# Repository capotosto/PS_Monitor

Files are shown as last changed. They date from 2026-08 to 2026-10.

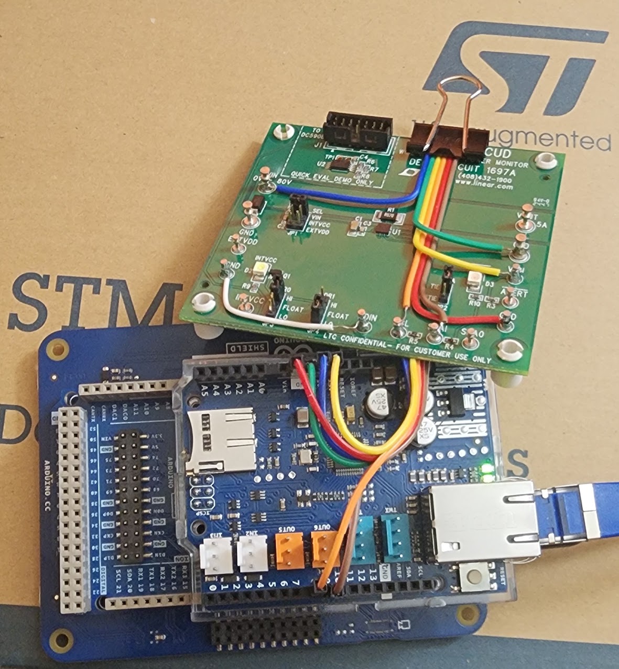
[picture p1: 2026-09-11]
documentation/Pictures/EVBArduinoAssembly.jpg

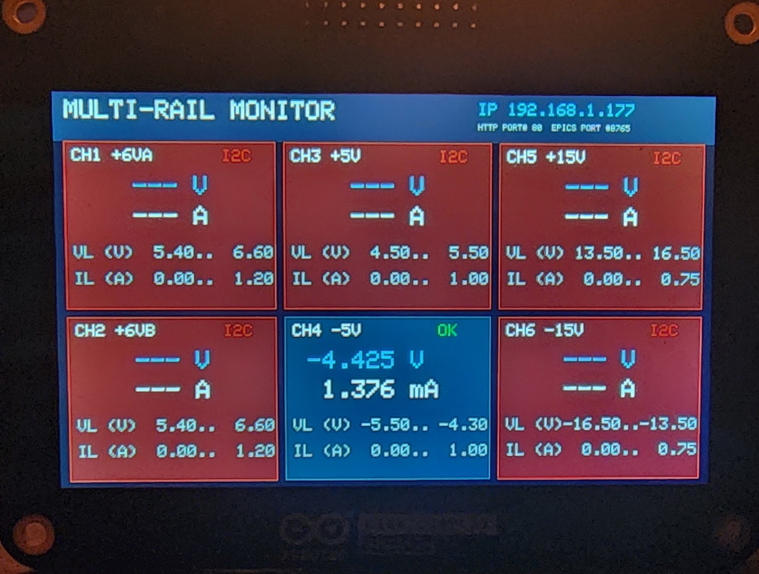
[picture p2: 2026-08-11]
documentation/Pictures/ExampleDisplay-Single_EVB_Connected_Non-ALM-3k3Load.jpg

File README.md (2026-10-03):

# Multi-Rail Isolated Power Supply Monitoring System

**Repository:** `PS_Monitor`  
**Author:** Mike Capotosto

## Project Overview

The Multi-Rail Isolated Power Supply Monitoring System measures the voltage and current of up to six floating power-supply rails while preserving galvanic isolation between measurement channels. Each rail is monitored by an LTC2945 power monitor connected through an isolated I²C interface to an Arduino GIGA R1 WiFi. The Arduino firmware performs data acquisition, engineering-unit conversion, alarm evaluation, persistent configuration storage, local display control, HTTP service, and Ethernet communication with an EPICS Input/Output Controller. Measurement and status information is presented locally on the GIGA Display Shield, through a browser-based dashboard, and remotely through a Phoebus Control System Studio operator interface.

The monitored rails are:

- `+5VA`
- `+5VB`
- `+5V`
- `-5V`
- `+15V`
- `-15V`

---

## System Features

- Six isolated voltage and current measurement channels
- LTC2945 voltage, current, and power monitoring
- Independent I²C isolation for each floating rail
- Support for positive and negative supply rails
- Configurable upper and lower voltage limits
- Configurable upper and lower current limits
- Persistent alarm and network settings stored in internal QSPI flash
- Local touchscreen display using the Arduino GIGA Display Shield
- Browser-based monitoring and configuration dashboard
- Ethernet communication through the Arduino Ethernet Shield
- PSC (Portable Streaming Controller) protocol interface for EPICS integration
- EPICS Process Variables for measurements, limits, alarms, and status
- Phoebus OPI for centralized operator monitoring
- I²C communication-error detection
- Text-based alarm states such as `OVL`, `UVL` (over/under voltage limit), `OCL`, and `UCL` (over/under current limit)

---

## System Architecture

### Data Flow

```text
┌──────────────────────────────────────────────┐
│ Floating Power-Supply Rails                  │
│ +5VA, +5VB, +5V, -5V, +15V, and -15V        │
└──────────────────────┬───────────────────────┘
                       │
                       ▼
┌──────────────────────────────────────────────┐
│ LTC2945 Voltage and Current Monitors         │
│ One monitor per power-supply rail            │
└──────────────────────┬───────────────────────┘
                       │
                       ▼
┌──────────────────────────────────────────────┐
│ Isolated I²C Interfaces                      │
│ Maintains isolation between floating rails   │
└──────────────────────┬───────────────────────┘
                       │
                       ▼
┌──────────────────────────────────────────────┐
│ Arduino GIGA R1 WiFi Firmware                │
│                                              │
│ • Sensor acquisition                         │
│ • Engineering-unit conversion                │
│ • Negative-rail sign correction              │
│ • Alarm evaluation                           │
│ • Persistent settings                        │
│ • Local display                              │
│ • HTTP dashboard                             │
│ • PSC protocol server                        │
└───────────────┬────────────────────┬─────────┘
                │                    │
                ▼                    ▼
┌─────────────────────────┐  ┌──────────────────────┐
│ GIGA Display Shield     │  │ Ethernet Network     │
│ Local touchscreen UI    │  │ HTTP and PSC         │
└─────────────────────────┘  └──────────┬───────────┘
                                       │
                                       ▼
                            ┌────────────────────────┐
                            │ EPICS IOC              │
                            │ PSCDriver and records  │
                            └──────────┬─────────────┘
                                       │
                                       ▼
                            ┌────────────────────────┐
                            │ Phoebus / CSS OPI      │
                            │ Operator interface     │
                            └────────────────────────┘
```

### Major Subsystems

| Subsystem | Function |
|---|---|
| Sensor hardware | Measures rail voltage, shunt voltage, current, and power |
| I²C isolation | Preserves galvanic isolation between floating rails |
| Arduino firmware | Acquires data, evaluates alarms, stores settings, and manages communications |
| Local display | Shows rail measurements, limits, alarms, and communication status |
| HTTP dashboard | Provides browser-based monitoring and configuration |
| PSC interface | Transfers measurement and status data to the EPICS IOC |
| EPICS IOC | Converts device data into EPICS Process Variables |
| Phoebus OPI | Provides the centralized operator interface |

---

## Repository Structure

```text
PS_Monitor/
├── README.md
├── hardware/
│   ├── kicad/
│   ├── bom/
│   ├── gerbers/
│   ├── mechanical/
│   └── datasheets/
├── firmware/
│   ├── platformio.ini
│   ├── include/
│   ├── lib/
│   ├── src/
│   └── test/
├── epics-ioc/
│   ├── configure/
│   ├── db/
│   ├── dbd/
│   ├── iocBoot/
│   ├── psuMonitorApp/
│   └── opi/
└── documentation/
```

### Directory Descriptions

- **`/hardware`**  
  KiCad schematic and PCB files, manufacturing outputs, bill of materials, mechanical drawings, and related.

- **`/firmware`**  
  PlatformIO project for the Arduino GIGA R1 WiFi. This directory contains the application source code, configuration headers, local libraries, and build configuration.

- **`/epics-ioc`**  
  EPICS IOC source tree containing database files, record definitions, startup scripts, PSCDriver configuration, device communication settings, and Phoebus Control System Studio displays.

- **`/documentation`**  
  Assorted Documentation

---

## Hardware

### Primary Components

- Arduino GIGA R1 WiFi
- Arduino GIGA Display Shield
- Arduino Ethernet Shield
- LTC2945 voltage, current, and power monitors
- DC1697A LTC2945 demonstration board for prototype testing
- Per-channel I²C digital isolators
- Current-sense shunt resistors
- Custom monitoring and interface PCB
- Six isolated power-supply inputs

### Measurement Method

Each LTC2945 measures:

- Supply voltage
- Differential voltage across a current-sense shunt
- Calculated load current
- Calculated electrical power

Because each monitored supply may float at a different potential, every sensor channel communicates through its own isolated I²C interface. Negative rails are monitored within their isolated domains, and the firmware applies the appropriate sign to the reported engineering values.

---

## Firmware

The firmware is built with PlatformIO using the Arduino Mbed OS framework.

### Main Firmware Modules

| Module | Responsibility |
|---|---|
| `AppState` | Global channel data, settings, alarms, and system state |
| `SensorManager` | Sensor initialization, acquisition, and channel updates |
| `LTC2945` | Low-level LTC2945 register access and unit conversion |
| `DisplayUI` | GIGA Display Shield rendering and status updates |
| `EthernetServices` | Ethernet initialization and network service handling |
| `HttpDashboard` | Browser-based monitoring and configuration |
| `PscProtocol` | PSC protocol communication with the EPICS IOC |
| `PersistentStorage` | QSPI storage of alarm limits and network settings |
| `main` | System initialization and application scheduling |

### Firmware Configuration

Hardware-specific settings are stored in configuration headers, including:

- I²C addresses
- Shunt-resistance values
- Channel names
- Rail polarity
- Voltage and current scaling
- Default alarm limits
- Static network configuration
- MAC address
- PSC port configuration
- Sensor polling intervals

---

## Persistent Settings

The firmware stores configuration data in the Arduino GIGA internal QSPI flash using LittleFS.

Saved settings include:

- Per-channel voltage-low limit
- Per-channel voltage-high limit
- Per-channel current-low limit
- Per-channel current-high limit
- Static IP address
- Subnet mask
- Gateway address
- DNS server address
---

## Network Interfaces

### HTTP Dashboard

The firmware hosts a local web interface for:

- Viewing voltage and current measurements
- Viewing alarm and communication status
- Editing alarm limits
- Editing network parameters
- Saving settings to QSPI

### PSC Protocol

The Arduino exposes a PSC protocol service over Ethernet. The EPICS IOC connects to the device using PSCDriver and maps transmitted parameters into EPICS records.

---

## EPICS IOC

### Requirements

- EPICS Base
- ASYN
- PSCDriver
- A supported Linux environment
- Phoebus for the operator interface

### Build the IOC

From the repository root:

```bash
cd epics-ioc
make
```

### Start the IOC

```bash
cd iocBoot/iocpsuMonitor
./st.cmd
```

An equivalent direct launch command may also be used:

```bash
../../bin/linux-x86_64/psuMonitor st.cmd
```

### Example IOC Configuration

```text
P=TEST:
R=GIGA
DEVICE=GIGA_PSC
HOST=192.168.1.177
PORT=8765
```

The final values are defined in the IOC startup script.

---

## EPICS Process Variables

The IOC is intended to provide Process Variables for:

- Channel voltage
- Channel current
- Voltage-low limit
- Voltage-high limit
- Current-low limit
- Current-high limit
- Voltage alarm status
- Current alarm status
- Sensor communication status
- I²C error status
- Arduino connection status
- Network information
- Firmware status

### Alarm States

| Status | Meaning |
|---|---|
| `OK` | Measurement is within configured limits |
| `OVL` | Over-voltage limit |
| `UVL` | Under-voltage limit |
| `OCL` | Over-current limit |
| `UCL` | Under-current limit |
| `I2C Error` | Sensor communication failure |
| `Disconnected` | IOC communication failure |

---

## Operator Interface

The Phoebus OPI provides a centralized display for all monitored rails.

Planned or implemented interface elements include:

- Voltage and current readbacks
- Alarm-limit displays
- Text-based alarm indicators
- Connection-status indicator
- I²C error indicator
- Per-channel status cards
- Network and firmware information
- Overall system status

---

## Project Milestones

- [x] Define system requirements and monitored power rails
- [x] Select the Arduino GIGA R1 WiFi as the primary controller
- [x] Establish the PlatformIO firmware project
- [x] Develop the initial six-channel display layout
- [x] Add configurable voltage and current alarm limits
- [x] Establish the Ethernet and PSC communication architecture
- [x] Complete single-channel LTC2945 prototype validation
- [ ] Verify current scaling for each shunt-resistor value
- [ ] Complete six-channel isolated I²C hardware
- [ ] Finalize persistent storage and recovery testing
- [ ] Complete browser-based configuration testing
- [ ] Finalize EPICS database records
- [ ] Complete Phoebus OPI
- [ ] Fabricate and assemble the custom PCB
- [ ] Calibrate all measurement channels
- [ ] Perform end-to-end system validation
- [ ] Complete final project documentation

---

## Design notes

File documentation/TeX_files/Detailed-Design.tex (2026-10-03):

% !TeX root = ../main.tex
\chapter{Detailed Design Review}
\label{chap:detailed-design}

\begin{weekthreechange}
    The preliminary architecture has been carried forward into this detailed implementation of six galvanically isolated V/I measurement channels, an Arduino Giga R1 micro, display module, ethernet interface, EPICS IOC, and Phoebus control panels. The monitored rails in this design are digital supplies +5VA, +5VB, and analog voltages +/-5V, and +/-15V. Component-level ratings, procurement, and porduction cost impacts are reviewed in the BOM and cost analysis sections of the following review.
\end{weekthreechange}

\section{Purpose and Scope}
This chapter documents the hardware and software design of the
Multi-Rail Isolated Power Supply Monitoring System. The design monitors six
power-supply rails, measures rail voltage and load current, preserves electrical
isolation between floating supplies and the controller, evaluates measurements
against user-configurable alarm limits, presents local status on the controller
display, and publishes measurements and status to an EPICS control-system
interface.

This design is intended to establish the major analog and digital
functional blocks, document supporting engineering calculations, define the
hardware schematic baseline, and provide software flowcharts detailed enough to
support implementation.

\section{Problem Definition}
The project addresses the need to monitor several low-voltage power-supply rails
that do not necessarily share a common reference. A conventional
monitoring circuit that directly connects the grounds together
would defeat the electrical isolation of the supplies and could create unwanted
return paths. However, the user needs a single location from which to observe rail voltage, rail current, alarm state, communication status, and the overall condition of the power system.

The required monitoring system must therefore make accurate measurements on
six separate rails while preserving isolation between the monitored domains. It
must support both positive and negative rails, detect sensor or communication
faults, provide configurable voltage and current limits, retain configuration
information after reset, present useful local status, and make the same data
available to the facility control system over Ethernet. The monitored rails in
the present design are +5 V A, +5 V B, +/-5 V, and +/-15 V.

\section{Proposed Solution}
The proposed solution assigns one LTC2945 voltage/current monitor to each power
rail. Load current is converted to a small differential voltage by a precision
high-side shunt resistor and the LTC2945 digitizes both the shunt voltage and the
rail voltage. Each sensor remains referenced to its own monitored supply domain.
The I\textsuperscript{2}C communication path is then isolated so that digital
measurement data can be transferred to a common Arduino GIGA R1 WiFi controller
without directly bonding the isolated supply returns together.

The Arduino GIGA performs channel acquisition, engineering-unit conversion,
negative-rail sign handling, alarm evaluation, configuration storage, display
updates, and network communication. A local GIGA Display Shield provides
immediate status at the hardware. Ethernet transports measurement and status
data using the PSC protocol to an EPICS IOC, where PSCDriver and EPICS records
make the values available to a CS-Studio Phoebus operator interface. This
architecture separates the rail-side analog measurement functions from the
controller and supervisory-control functions while maintaining a single user
interface for the complete system.

\section{Chosen Conceptual Design and Functional Block Diagram}
\label{sec:functional-blocks}
The major system functions are summarized below.

\begin{enumerate}
    \item \textbf{Power-Supply Interface:} Connect to the six monitored rails and
    route each rail through the associated voltage/current monitoring channel.
    \item \textbf{Current Measurement:} Convert load current to a differential
    voltage across a precision shunt resistor and digitize it with the
    LTC2945.
    \item \textbf{Voltage Measurement:} Measure the monitored rail voltage using
    the LTC2945 supply-voltage ADC channel.
    \item \textbf{Electrical Isolation:} Maintain galvanic isolation between each
    floating monitored supply and the common controller-side I\textsuperscript{2}C bus.
    \item \textbf{Digital Acquisition:} Poll each monitor, identify communication
    faults, apply channel-specific sign/scaling information, and calculate
    engineering-unit values.
    \item \textbf{Alarm Processing:} Compare voltage and current values against
    configured upper and lower limits and generate channel alarm states.
    \item \textbf{Local User Interface:} Present all rail measurements, alarms,
    network state, and communication status on the Arduino GIGA Display.
    \item \textbf{Network/EPICS Interface:} Publish measurements, alarm limits,
    alarm state, and connection status over Ethernet for the EPICS IOC and
    Phoebus interface.
\end{enumerate}

\subsection{Functional Block Diagram}

\begin{figure}[H]
    \centering

    \makebox[\textwidth][c]{%
        \rotatebox{90}{%
            \begin{minipage}{0.9\textheight}
                \centering

                \resizebox{0.78\textheight}{!}{%
                    \begin{tikzpicture}[
                        >=Stealth,
                        font=\small,
                        block/.style={
                            draw,
                            rectangle,
                            rounded corners=2pt,
                            align=center,
                            minimum height=1.25cm,
                            minimum width=2.75cm,
                            text width=2.45cm,
                            inner sep=5pt,
                            line width=0.8pt
                        },
                        rail/.style={
                            draw,
                            rectangle,
                            rounded corners=2pt,
                            align=center,
                            minimum height=0.55cm,
                            minimum width=1.35cm,
                            font=\footnotesize,
                            line width=0.7pt
                        },
                        group/.style={
                            draw,
                            dashed,
                            rounded corners=4pt,
                            inner sep=8pt,
                            line width=0.8pt
                        },
                        signal/.style={
                            ->,
                            line width=0.9pt
                        },
                        line/.style={
                            line width=0.9pt
                        },
                        bus/.style={
                            line width=1.1pt
                        },
                        busarrow/.style={
                            ->,
                            line width=1.1pt
                        },
                        siglabel/.style={
                            font=\scriptsize,
                            fill=white,
                            inner sep=1.5pt,
                            text depth=0pt,
                            text height=1.5ex,
                            align=center
                        }
                        ]

                        % ============================================================
                        % MONITORED POWER RAILS
                        % ============================================================

                        \node[rail] (p6a) at (0, 2.25) {+6 V A};
                        \node[rail] (p6b) at (0, 1.35) {+6 V B};
                        \node[rail] (p5)  at (0, 0.45) {+5 V};
                        \node[rail] (m5)  at (0,-0.45) {$-5$ V};
                        \node[rail] (p15) at (0,-1.35) {+15 V};
                        \node[rail] (m15) at (0,-2.25) {$-15$ V};

                        \node[
                        above=0.30cm of p6a,
                        font=\bfseries
                        ] {Monitored Power-Supply Rails};

                        % ============================================================
                        % RAIL COLLECTION BUS
                        % ============================================================

                        \coordinate (railBusTop)    at (1.15, 2.25);
                        \coordinate (railBusBottom) at (1.15,-2.25);
                        \coordinate (railBusMid)    at (1.15, 0);

                        \draw[bus] (railBusTop) -- (railBusBottom);

                        % Individual rail connections -- no overlapping arrowheads.
                        \foreach \railname/\y in {
                            p6a/2.25,
                            p6b/1.35,
                            p5/0.45,
                            m5/-0.45,
                            p15/-1.35,
                            m15/-2.25
                        }{
                            \draw[line] (\railname.east) -- (1.15,\y);
                        }

                        % ============================================================
                        % POWER-SUPPLY INTERFACE BOARD
                        % ============================================================

                        \node[
                        block,
                        anchor=west
                        ] (shunts) at (2.15,0)
                        {
                            High-Side\\
                            Current-Sense Shunts\\[2pt]
                            \footnotesize
                            One independent\\
                            sense element per rail
                        };

                        \node[
                        block,
                        right=0.65cm of shunts
                        ] (ltc)
                        {
                            LTC2945\\
                            Voltage / Current\\
                            Monitor Channels\\[2pt]
                            \footnotesize
                            Six independent\\
                            channels
                        };

                        \node[
                        block,
                        right=0.65cm of ltc
                        ] (iso)
                        {
                            I\textsuperscript{2}C Digital\\
                            Isolation\\[2pt]
                            \footnotesize
                            One isolated interface\\
                            per monitored rail
                        };

                        \draw[busarrow]
                        (railBusMid)
                        --
                        (shunts.west);

                        \draw[busarrow]
                        (shunts.east)
                        --
                        node[
                        siglabel,
                        midway,
                        rotate=90,
                        above=6pt
                        ]
                        {Sense Voltage}
                        (ltc.west);

                        \draw[busarrow]
                        (ltc.east)
                        --
                        node[
                        siglabel,
                        midway,
                        above=4pt
                        ]
                        {I\textsuperscript{2}C}
                        (iso.west);

                        % ============================================================
                        % POWER-SUPPLY INTERFACE GROUP
                        % ============================================================

                        \begin{scope}[on background layer]
                            \node[
                            group,
                            fit=(shunts)(ltc)(iso)
                            ] (interfaceGroup) {};
                        \end{scope}

                        \node[
                        font=\bfseries,
                        fill=white,
                        inner sep=2pt,
                        anchor=south
                        ]
                        at (interfaceGroup.north)
                        {Power Supply Interface Board};

                        % ============================================================
                        % ISOLATION BARRIER
                        % ============================================================

                        \coordinate (barrierTop)
                        at ($(iso.north east)+(0.50,0.55)$);

                        \coordinate (barrierBottom)
                        at ($(iso.south east)+(0.50,-0.55)$);

                        % Keep only the dashed isolation-barrier line; no text label.
                        \draw[
                        dashed,
                        line width=1.1pt
                        ]
                        (barrierTop) -- (barrierBottom);

                        % ============================================================
                        % ARDUINO GIGA
                        % ============================================================

                        \node[
                        block,
                        right=1.45cm of iso
                        ] (giga)
                        {
                            Arduino GIGA R1 WiFi\\[2pt]
                            \footnotesize
                            Acquire Measurements\\
                            Apply Scaling and Polarity\\
                            Evaluate Alarm Limits\\
                            Manage Configuration
                        };

                        \draw[busarrow]
                        (iso.east)
                        --
                        node[
                        siglabel,
                        midway,
                        rotate=90,
                        above=6pt
                        ]
                        {Isolated I\textsuperscript{2}C}
                        (giga.west);

                        % ============================================================
                        % DISPLAY AND ETHERNET
                        % ============================================================

                        \node[
                        block,
                        right=1.25cm of giga,
                        yshift=1.55cm
                        ] (display)
                        {
                            GIGA Display Shield\\[2pt]
                            \footnotesize
                            Voltage / Current\\
                            Alarm Status\\
                            Communication Status
                        };

                        \node[
                        block,
                        right=1.25cm of giga,
                        yshift=-1.55cm
                        ] (ethernet)
                        {
                            Ethernet Interface\\[2pt]
                            \footnotesize
                            PSC Protocol\\
                            Configuration Interface
                        };

                        \coordinate (controllerBranch)
                        at ($(giga.east)+(0.55,0)$);

                        \draw[line]
                        (giga.east)
                        --
                        (controllerBranch);

                        \draw[signal]
                        (controllerBranch)
                        |-
                        (display.west);

                        \draw[signal]
                        (controllerBranch)
                        |-
                        (ethernet.west);

                        \fill (controllerBranch) circle (1.5pt);

                        % ============================================================
                        % CONTROLLER GROUP
                        % ============================================================

                        \begin{scope}[on background layer]
                            \node[
                            group,
                            fit=(giga)(display)(ethernet)
                            ] (controllerGroup) {};
                        \end{scope}

                        \node[
                        font=\bfseries,
                        fill=white,
                        inner sep=2pt,
                        anchor=south
                        ]
                        at (controllerGroup.north)
                        {Controller Assembly};

                        % ============================================================
                        % EPICS IOC
                        % ============================================================

                        \node[
                        block,
                        right=1.20cm of ethernet
                        ] (ioc)
                        {
                            EPICS IOC / PSCDriver\\[2pt]
                            \footnotesize
                            Receive Measurements\\
                            Publish Engineering Values\\
                            Generate EPICS Alarms
                        };

                        \draw[busarrow]
                        (ethernet.east)
                        --
                        node[
                        siglabel,
                        midway,
                        rotate=90,
                        above=6pt
                        ]
                        {Ethernet}
                        (ioc.west);

                        % ============================================================
                        % PHOEBUS
                        % ============================================================

                        \node[
                        block,
                        right=1.20cm of ioc
                        ] (phoebus)
                        {
                            CS-Studio Phoebus\\[2pt]
                            \footnotesize
                            Operator Interface\\
                            Voltage / Current Display\\
                            Alarm and System Status
                        };

                        \draw[busarrow]
                        (ioc.east)
                        --
                        node[
                        siglabel,
                        midway,
                        rotate=90,
                        below=6pt
                        ]
                        {EPICS Channel Access}
                        (phoebus.west);

                        % ============================================================
                        % SUPERVISORY GROUP
                        % ============================================================

                        \begin{scope}[on background layer]
                            \node[
                            group,
                            fit=(ioc)(phoebus)
                            ] (supervisoryGroup) {};
                        \end{scope}

                        \node[
                        font=\bfseries,
                        fill=white,
                        inner sep=2pt,
                        anchor=south
                        ]
                        at (supervisoryGroup.north)
                        {Supervisory Control System};

                    \end{tikzpicture}%
                }

                \vspace{0.25cm}

                \caption{
                    Functional block diagram of the multi-rail isolated
                    power supply monitoring system. Six independent power-supply rails
                    are measured using high-side current sensing and LTC2945 voltage/current
                    monitoring channels. Digital isolation preserves electrical independence
                    between the monitored supplies and the common controller. The Arduino
                    GIGA processes the measurements, provides a local operator display, and
                    transmits measurement and status information over Ethernet to the EPICS
                    IOC and CS-Studio Phoebus operator interface.
                }
                \label{fig:functional-block-diagram}

            \end{minipage}%
        }%
    }

\end{figure}

\section{Engineering Calculations}
\label{sec:engineering-calculations}

\section{Functional Specifications}
\label{sec:functional-specifications}
The functional specifications used for the design are summarized in
Table~\ref{tab:functional-specifications}. These values define the intended
operating envelope of the prototype and establish the quantities that must be
checked during circuit analysis and later verification testing.

\begin{table}[H]
    \centering
    \caption{Functional specifications.}
    \label{tab:functional-specifications}
    \begin{tabularx}{\textwidth}{>{\raggedright\arraybackslash}p{0.27\textwidth}X}
        \toprule
        \textbf{Function} & \textbf{Specification} \\
        \midrule
        Monitored rails & +5 V A, +5 V B, +5 V, -5 V, +15 V, and -15 V \\
        Number of channels & Six independent voltage/current measurement channels \\
        +5 V A/B current range & 0 to 2 A design range per rail \\
        +5 V, -5 V, +15 V, -15 V current range & 0 to 1 A design range per rail \\
        Voltage measurement resolution & 25 mV/LSB nominal using the LTC2945 rail-voltage ADC \\
        Current-sense resolution & 25 \(\mu\)V/LSB across the selected shunt resistor; approximately 0.641 mA/LSB with 39 m\(\Omega\) and 0.500 mA/LSB with 50 m\(\Omega\) \\
        Isolation & Independent digital isolation for every floating monitor channel \\
        Alarm processing & User-configurable upper/lower voltage and current limits with local and EPICS status indication \\
        Fault handling & Detect failed I\textsuperscript{2}C transactions and prevent invalid data from being treated as a valid measurement \\
        Local interface & GIGA Display Shield showing voltage, current, alarm state, communication state, and configured limits \\
        Network interface & Ethernet PSC server for EPICS IOC communication plus browser-based configuration/monitoring services \\
        Configuration retention & Network parameters and alarm limits stored in nonvolatile memory \\
        Controller logic level & 3.3 V; external interfaces must not exceed the GIGA I/O limits \\
        \bottomrule
    \end{tabularx}
\end{table}

\section{Design Methodology}
The design was developed by dividing the system into measurement, isolation,
controller, user-interface, and control-system functions and then verifying the
interfaces between those blocks. The analog measurement design began with the
maximum required rail current. The shunt value was selected so that the maximum
nominal current produces a differential voltage comfortably below the LTC2945
102.4 mV current-sense full-scale value. Power dissipation in each shunt was
then calculated using \(P=I^2R\), and the selected resistor rating was checked
against the calculated worst-case dissipation. The same approach was used for
PCB copper: maximum continuous current, allowable temperature rise, and voltage
drop were considered before final trace and copper-pour dimensions were chosen.
Detailed calculations are included in Appendix~\ref{app:design-calculations}.

Electrical isolation was treated as a system-interface requirement rather than
only a component-selection problem. Each LTC2945 remains electrically local to
its rail, and the digital signals cross the isolation boundary through isolated
logic. Controller-side I\textsuperscript{2}C buffering and level compatibility
were checked against 3.3 V logic requirements. The controller does not drive
loads directly; its GPIO and I\textsuperscript{2}C pins only interface to
logic-level circuitry. This substantially reduces the current demanded from an
individual microcontroller pin and allows the high-current rail paths to remain
on the dedicated sensor hardware.

The embedded-software design follows the same functional partitioning. Sensor
acquisition is separated from display formatting, network services, persistent
storage, and PSC message handling. Alarm processing is performed on engineering-unit values after
channel polarity and scaling are applied. The EPICS IOC is intentionally kept
outside the embedded controller so that the Arduino is responsible for hardware
acquisition while the IOC is responsible for exposing process variables to the remote user control system.

\section{Design Schematics}
\label{sec:prelim-schematics}

The hardware schematics are maintained in KiCad and are included
below directly from the plotted PDF files in the project hardware directory.

\subsection{Sensor Board Schematic}

\includepdf[
pages=-,
angle=90,
scale=0.90,
pagecommand={}
]{
    ../hardware/Isolated Multi-Rail Power Supply Monitor Sensor Board/%
    Isolated Multi-Rail Power Supply Monitor Sensor Board.pdf
}

\subsection{Arduino Shield Board Schematic}

\includepdf[
pages=-,
angle=90,
scale=0.90,
pagecommand={}
]{
    ../hardware/Isolated Multi-Rail Power Supply Monitor Arduino Shield Board/%
    Isolated Multi-Rail Power Supply Monitor Arduino Shield Board.pdf
}

\section{Software Architecture and Critical Software Test Results}
\label{sec:software-architecture-tests}
The embedded software is organized into functional modules rather than one
loop. The current implementation contains shared application state,
sensor-management and LTC2945 register-access code, display handling, Ethernet
services, an web control page, PSC protocol handling, persistent storage, and the
main application controller. This separation permits the measurement code to be
tested independently of the EPICS IOC and permits the network/control-system
interface to consume already processed engineering-unit values.

At startup, the firmware initializes hardware interfaces, loads persistent
settings, configures the monitoring channels, and then enters repetitive sensor
acquisition and service processing. Each channel read is checked for successful
I\textsuperscript{2}C communication before conversion. Valid raw ADC values are
scaled using the configured shunt resistance and channel polarity; invalid
transactions produce a communication error state. Voltage and current values
are then compared with their configured lower and upper limits before the local
display and PSC message data are updated. The detailed execution flow is shown
in Appendix~\ref{app:software-flowchart}.

The most critical functions were tested to the extent possible on the available
single-channel evaluation board setup. Sensor acquisition returned stable voltage
and current data, open\slash unconnected channels produced I\textsuperscript{2}C fault
states instead of plausible but invalid values, negative-rail sign handling was
visible on the -5 V test channel, and changing a voltage limit changed the local
alarm state as expected. Ethernet/PSC communication was verified by the EPICS
IOC reporting a connected driver and by Phoebus displaying the same test-channel
voltage/current data. Remaining multi-channel verification, long-duration
operation, restart/persistence checks, and final PCB testing will be repeated on
the assembled production hardware. This is shown in more detail in \nameref{chap:prototyping-dev}

\section{Summary of Preliminary-Design Changes and Project Impact}
\label{sec:w2-design-changes}
The preliminary-design work identified several items that were clarified or
changed from the earliest project documentation. Table~\ref{tab:w2-changes}
summarizes the principal changes and their effect on the design baseline.

\begin{table}[H]
    \centering
    \caption{Week 2 design changes and resulting impact.}
    \label{tab:w2-changes}
    \begin{tabularx}{\textwidth}{>{\raggedright\arraybackslash}p{0.25\textwidth}>{\raggedright\arraybackslash}p{0.31\textwidth}X}
        \toprule
        \textbf{Item} & \textbf{Preliminary-design result} & \textbf{Impact} \\
        \midrule
        Rail naming & The two high-current digital rails are +5 V A and +5 V B. & Some documentation and channel labels were corrected where it showed +6V; electrical architecture is unchanged. \\
        Production shunts & 39 m\(\Omega\) selected for 2 A +5 V rails and 50 m\(\Omega\) selected for 1 A rails. & Improves headroom and keeps shunt dissipation well below the selected resistor rating. \\
        Prototype shunt & The DC1697A shunt was changed to approximately 17.8 \(\Omega\) for low-current Arduino-driven loads. & Allows realistic ADC utilization during testing without exceeding Arduino regulator current limits. \\
        I\textsuperscript{2}C pull-ups & External 4.7 k\(\Omega\) pull-up footprints remain available but are DNP where the selected buffer/current-source arrangement makes them unnecessary. & Reduces unnecessary loading and preserves the intended I\textsuperscript{2}C interface behavior. \\
        Fault handling & Missing or failed sensors are represented as communication faults rather than numerical measurements. & Reduces risk of a supervisory system accepting stale or fabricated values. \\
        Configuration and network software & Alarm/network settings, HTTP services, PSC communication, and the Phoebus interface are now part of the implemented software baseline. & Adds firmware integration work but reduces final-system risk because these interfaces can be exercised before all six production channels are assembled. \\
        Cost/schedule baseline & No formal budget or schedule re-baseline is required solely because of the Week 2 design changes. & Component values and firmware structure changed within the existing architecture; procurement cost will be rechecked after first-article PCB testing and any resulting BOM revisions. \\
        \bottomrule
    \end{tabularx}
\end{table}

The largest remaining technical risk is integration of all six isolated channels
on the final PCB rather than operation of any single functional block. The
single-channel prototype reduced uncertainty in the LTC2945 measurement,
firmware scaling, alarm processing, Ethernet/PSC firmware, and operator interface.
Final verification will focus on channel-to-channel isolation,
concurrent I\textsuperscript{2}C operation, and confirmation that all configured settings survive normal resets and power cycles.

\begin{weekthreechange}
    Following the PDR, the hardware design was finalized to the component level without change. The measurement architecture developed in the PDR is unchanged. Component selections were once again verified, confirming voltage, current, powe,r and tolerance of components were within requirements to meet the design specifications. Component availability and part numbers were verified against the BOM to ensure correct parts were specified.

    The hardware and firmware were reviewed together to ensure the software's scaling settings correspond to the component values selected, and to confirm channel polarity is consistent between the input and the software's final readout to the user.
\end{weekthreechange}

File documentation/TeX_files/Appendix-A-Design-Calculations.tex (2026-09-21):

% !TeX root = ../main.tex
\chapter{Design Calculations and Circuit Analysis}
\label{app:design-calculations}
This appendix contains the electrical calculations used to select and verify the
preliminary hardware. In addition to nominal values, voltage, current, power,
logic-level compatibility, and component capability are considered so that the
design does not intentionally operate a component beyond its specified limits.

\section{Current-Sense Shunt Resistor Sizing}
\label{sec:shunt-sizing}
The LTC2945 measures the differential voltage between SENSE+ and SENSE-- with a
full-scale range of \SI{102.4}{\milli\volt}. The ideal shunt resistance for a
specified maximum measurable current is therefore
\begin{equation}
    R_{SHUNT,ideal}=\frac{V_{SENSE,FS}}{I_{MAX}}
    =\frac{\SI{102.4}{\milli\volt}}{I_{MAX}}.
\end{equation}
To prevent saturation, a scaling factor, $K_H$, is applied to leave some headroom:
\begin{equation}
    R_{SHUNT}=K_H\frac{\SI{102.4}{\milli\volt}}{I_{MAX}},
    \qquad 0<K_H<1.
\end{equation}
For example, $K_H=0.80$ reserves 20\% headroom for overload, tolerance, and
transient conditions.

The shunt power at maximum continuous current is
\begin{equation}
    P_{SHUNT}=I_{MAX}^{2}R_{SHUNT}.
\end{equation}
The installed resistor power rating should exceed this value.

\subsection{Current Measurement Resolution}
The LTC2945 current-sense ADC has a nominal sense-voltage resolution of
\SI{25}{\micro\volt} per LSB. The current represented by one ADC count is
\begin{equation}
    I_{LSB}=\frac{\SI{25}{\micro\volt}}{R_{SHUNT}}.
\end{equation}
This relationship provides an important design tradeoff: a smaller shunt lowers
power dissipation but also increases the minimum current increment represented by
one ADC count.

\subsection{Production Shunt Design Table}
\begin{table}[H]
    \centering
    \caption{Production current-sense resistor calculations.}
    \label{tab:production-shunts}
    \begin{tabular}{lrrrrrr}
        \toprule
        Rail & $I_{MAX}$ & $R_{ideal}$ & Selected $R$ &
        $V_{SHUNT}$ & $I_{LSB}$ & $P_{MAX}$ \\
        & (A) & ($\Omega$) & ($\Omega$) &
        (mV) & (mA/LSB) & (W) \\
        \midrule
        +5VA  & 2.00 & 0.0512 & 0.039 & 78.0 & 0.641 & 0.156 \\
        +5VB  & 2.00 & 0.0512 & 0.039 & 78.0 & 0.641 & 0.156 \\
        +5V   & 1.00 & 0.1024 & 0.050 & 50.0 & 0.500 & 0.050 \\
        -5V   & 1.00 & 0.1024 & 0.050 & 50.0 & 0.500 & 0.050 \\
        +15V  & 1.00 & 0.1024 & 0.050 & 50.0 & 0.500 & 0.050 \\
        -15V  & 1.00 & 0.1024 & 0.050 & 50.0 & 0.500 & 0.050 \\
        \bottomrule
    \end{tabular}
\end{table}

\subsection{Evaluation-Board Shunt Calculation}
The prototype LTC2945 evaluation board was tested from a \SI{5}{\volt} source
with a load range of approximately \SI{1}{\kilo\ohm} to \SI{10}{\kilo\ohm}.
This is a low-current bench-test condition and is separate from the production
shunt design.

At the minimum load resistance, the shunt required to place the current-sense
input at full scale is
\begin{equation}
    R_{S,FS}=\frac{V_{SHUNT}R_L}{V_S-V_{SHUNT}}
    =\frac{(\SI{0.1024}{\volt})(\SI{1}{\kilo\ohm})}
    {\SI{5}{\volt}-\SI{0.1024}{\volt}}
    =\SI{20.91}{\ohm}.
\end{equation}
Applying approximately 15\% headroom gives
\begin{equation}
    R_S=(0.85)(\SI{20.91}{\ohm})\approx\SI{17.8}{\ohm}.
\end{equation}
At a \SI{10}{\kilo\ohm} load,
\begin{equation}
    I_{MIN}=\frac{\SI{5}{\volt}}
    {\SI{10}{\kilo\ohm}+\SI{17.8}{\ohm}}
    \approx\SI{499.1}{\micro\ampere},
\end{equation}
and therefore
\begin{equation}
    V_{SHUNT,MIN}=I_{MIN}R_S
    \approx(\SI{499.1}{\micro\ampere})(\SI{17.8}{\ohm})
    \approx\SI{8.88}{\milli\volt}.
\end{equation}
The prototype sense voltage therefore remains inside the LTC2945
\SI{102.4}{\milli\volt} full-scale range over the intended test loads.

\section{PCB Trace and Copper-Pour Current Capacity}
\label{sec:trace-width}
Power-path copper must carry the maximum rail current without excessive
temperature rise or voltage drop. KiCad's track-width calculator uses a
closed-form fit to IPC-2152 data. For an external trace it can be expressed as
\begin{equation}
    \Delta T = K I^a W^b T_h^c,
\end{equation}
where $I$ is current in amperes, $W$ is trace width in mils, $T_h$ is copper
thickness in mils, and for external tracks the KiCad coefficients are
\begin{equation}
    K=215.3,\qquad a=2,\qquad b=-1.15,\qquad c=-1.0.
\end{equation}
Solving for minimum width,
\begin{equation}
    W_{MIN}=\left(\frac{\Delta T}
    {K I^a T_h^c}\right)^{1/b}.
\end{equation}
For \SI{1}{oz} copper ($T_h\approx\SI{1.378}{mil}$) and a preliminary
\SI{10}{\celsius} allowed rise, the calculated external-trace widths are
approximately \SI{3.27}{mil} at \SI{0.5}{A}, \SI{10.9}{mil} at \SI{1}{A}, and
\SI{36.4}{mil} at \SI{2}{A}. These are thermal minimums only; the actual layout
should use wider traces or copper pours where space permits.

\section{I\texorpdfstring{\textsuperscript{2}}{2}C Pull-Up Resistor Sizing}
\label{sec:i2c-pullups}
The I2C bus buffer and I2C line driver both have internal active current sources that eliminate the need for external pullups. Footprints were placed for 4.7k pullups but are set as Do Not Populate.

\section{LTC2945 Voltage Measurement Resolution}
The LTC2945 rail-voltage channel has a nominal full-scale range of
\SI{102.4}{\volt} and a nominal resolution of \SI{25}{\milli\volt} per LSB.
The quantization-only percentage of a measured rail voltage is therefore
\begin{equation}
    \epsilon_Q=\frac{\SI{25}{\milli\volt}}{V_{RAIL}}\times100\%.
\end{equation}
For example, one count corresponds to approximately 0.50\% of a \SI{5}{\volt}
rail and 0.17\% of a \SI{15}{\volt} rail.
This is only ADC resolution and not total measurement
accuracy.

\section{Negative-Rail Sign Convention}
The -5 V and -15 V supplies are electrically isolated from the controller. The
monitor can therefore be placed in the high side of each isolated rail and read a
positive local differential quantity even when the system-level rail is labeled
negative. Firmware applies the configured sign after acquisition:
\begin{equation}
    V_{DISPLAY}=S_VV_{MEASURED},\qquad S_V\in\{+1,-1\}.
\end{equation}
The same channel metadata is used by the local display and network interface so
that a negative rail is represented consistently throughout the system.

\section{Alarm-Limit Scaling}
User alarm thresholds are stored and compared in engineering units. For a lower
voltage limit $V_L$ and upper voltage limit $V_H$, the normal voltage state is
\begin{equation}
    V_L\le V_{MEAS}\le V_H.
\end{equation}
Similarly, for lower and upper current limits,
\begin{equation}
    I_L\le I_{MEAS}\le I_H.
\end{equation}
If raw ADC thresholds are ever written directly to the LTC2945, the corresponding
register value must be calculated from the ADC LSB size. For the current-sense
channel,
\begin{equation}
    N_I=\frac{I_{LIMIT}R_{SHUNT}}{\SI{25}{\micro\volt/LSB}},
\end{equation}
and for the rail-voltage channel,
\begin{equation}
    N_V=\frac{V_{LIMIT}}{\SI{25}{\milli\volt/LSB}}.
\end{equation}

\section{Controller-Supply Power Budget}

A preliminary controller power budget was developed using datasheet maximum
values where available and conservative design-current allowances for assemblies
where a complete board-level maximum current is not specified. A 25\% design
margin is applied to the calculated load.

\begin{table}[H]
    \centering
    \caption{Preliminary controller-side power budget.}
    \label{tab:power-budget}
    \begin{tabular}{lrrr}
        \toprule
        Load & Supply & Design Current & Power \\
        & (V) & (A) & (W) \\
        \midrule
        Arduino GIGA R1 WiFi
        & 5.0 & 0.500 & 2.500 \\

        GIGA Display Shield
        & 3.3 & 0.250 & 0.825 \\

        W6100 Ethernet interface
        & 3.3 & 0.265 & 0.875 \\

        I\textsuperscript{2}C isolation/controller circuitry
        & 3.3 & 0.065 & 0.215 \\
        \midrule
        Subtotal
        & -- & -- & 4.415 \\

        25\% design margin
        & -- & -- & 1.104 \\
        \midrule
        \textbf{Total}
        & -- & -- & \textbf{5.519} \\
        \bottomrule
    \end{tabular}
\end{table}

\section{Component Capability Checks}
\label{sec:component-capability}
The calculations above establish the required electrical values. The following
checks compare those values with the capability of the selected components.

\section{Current-Sense Resistor Power Margin}
The selected LVK-series 39 m\(\Omega\) and 50 m\(\Omega\) four-terminal shunts
are rated at 0.75 W. At the maximum design current of 2 A, the 39 m\(\Omega\)
resistor dissipates
\begin{equation}
    P=(2\,\mathrm{A})^2(0.039\,\Omega)=0.156\,\mathrm{W}.
\end{equation}
This is approximately 20.8\% of the 0.75 W rating, corresponding to about a
4.8:1 power-rating margin before considering PCB temperature and derating. At
1 A, a 50 m\(\Omega\) shunt dissipates only 0.050 W, approximately 6.7\% of a
0.75 W rating.

\section{LTC2945 Input and ADC Range}
The highest monitored nominal rail is 15 V, far below the LTC2945 0--80 V rail
monitoring range. The selected production shunts produce 78 mV at 2 A on the
39 m\(\Omega\) channels and 50 mV at 1 A on the 50 m\(\Omega\) channels. Both
values are below the 102.4 mV current-sense full scale, leaving approximately
24.4 mV and 52.4 mV of ADC headroom respectively. The LTC2945 can operate from
an external 2.7--5.9 V supply, so a 3.3 V sensor-side logic supply is within its
specified operating range.

\section{Microcontroller I/O Compatibility}
The Arduino GIGA R1 WiFi operates with 3.3 V logic and specifies 8 mA maximum DC
current per I/O pin. The controller-side I\textsuperscript{2}C interface is a
logic interface, not a load-power interface. The TCA9803 used in the design
supports a 0.8--3.6 V A-side supply and a 1.65--3.6 V B-side supply and provides
an internal B-side current source of up to 3 mA. A 3 mA bus-low current is below
the 8 mA GIGA per-pin limit, providing more than a factor of two current margin.
The GIGA pins therefore do not directly source the optocoupler LED or rail-load
current; the external interface circuitry performs the required buffering and
isolation.

\section{Digital-Isolation Margin}
The ACPL-064L digital optocoupler is specified for 3.3 V/5 V operation and is
UL 1577 recognized for 3750 V\textsubscript{RMS} isolation for one minute. The
largest normal potential difference between the nominal monitored rails is only
30 V from -15 V to +15 V. The optocoupler rating therefore greatly exceeds the
functional isolation voltage required by this low-voltage monitoring system.
This comparison verifies component capability; it is not intended to redefine
the safety rating of the complete assembled product, which also depends on PCB
creepage, clearance, connectors, wiring, and enclosure construction.

\section{3.3 V Regulator Loading}
The TPS62912 is rated for up to 2 A output. Using the Week 1 design-current
allowances for the display, Ethernet interface, and controller-side isolation
circuitry gives an estimated 3.3 V load of
\begin{equation}
    I_{3.3}=0.250+0.265+0.065=0.580\,\mathrm{A}.
\end{equation}
This is approximately 29\% of the regulator's 2 A output rating and leaves
substantial current margin for transient and implementation variation.

\section{Tolerance and Measurement-Uncertainty Considerations}
The production current-sense resistors have a 1\% resistance tolerance. Because
current is calculated from \(I=V_{SHUNT}/R_{SHUNT}\), an uncorrected 1\% shunt
error produces approximately a 1\% gain error in calculated current. On a 2 A
range, this corresponds to approximately 20 mA, which is much larger than the
0.641 mA quantization step of the 39 m\(\Omega\) channel. The LTC2945 also has
its own conversion error; therefore component tolerance rather than ADC
quantization is an important contributor to absolute current accuracy. If
higher accuracy is required, the actual shunt resistance can be measured and a
per-channel calibration factor stored in firmware.

A conservative worst-case linear addition of a 1\% shunt tolerance and the
LTC2945's less-than-\(\pm0.75\%\) total unadjusted conversion error gives an
upper-bound estimate of approximately \(\pm1.75\%\) before wiring, thermal, and
calibration effects. This estimate is used for design margin rather than as a
claim of final calibrated system accuracy.

\section{Reference Specifications Used for Capability Checks}
\begin{itemize}
    \item Analog Devices, LTC2945 data sheet and product information: \url{https://www.analog.com/en/products/ltc2945.html}
    \item Arduino, GIGA R1 WiFi technical specifications: \url{https://store.arduino.cc/products/giga-r1-wifi}
    \item Broadcom, ACPL-064L low-power digital optocoupler data sheet/product page: \url{https://www.broadcom.com/products/optocouplers/industrial-plastic/digital-optocouplers/10mbd/acpl-064l-000e}
    \item Texas Instruments, TCA9803 I\textsuperscript{2}C buffer data sheet: \url{https://www.ti.com/product/TCA9803}
    \item Texas Instruments, TPS62912 buck converter data sheet: \url{https://www.ti.com/product/TPS62912}
    \item Ohmite LVK-series current-sense resistor specifications:
    \url{https://www.ohmite.com/assets/files/Datasheets/lvk-series.pdf}
\end{itemize}

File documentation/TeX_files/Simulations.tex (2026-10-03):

% !TeX root = ../main.tex
\chapter{Simulation Results}
\label{chap:simulations}

\begin{weekthreechange}
    \st{No simulations were performed for this project; instead, calculations were performed, and preliminary tests carried out with an evaluation board.}

    Simulations were performed using LTSpice in a DC Operating Point simulation to verify the calculation for the full-load shunt voltage for each of the voltages. Only the positive polarity was tested in the simulation, as negative polarity will naturally not matter to a a passive element such as the resistor.

    The data collected in this simulation matches the data found in Appendix A section \ref{sec:shunt-sizing}, table \ref{tab:production-shunts}

    \begin{figure}[H]
        \centering
        \includegraphics[
        width=.85\textwidth,
        %height=0.85\textwidth,
        keepaspectratio
        ]{Pictures/SimulationResultsLog}
        \caption{Simulation verifying current shunt voltage drops, data log}
    \end{figure}

\end{weekthreechange}

\clearpage

\begin{sidewaysfigure}[p]
    \centering
    \includegraphics[
    width=0.95\textheight,
    keepaspectratio
    ]{Pictures/SimulationResults}
    \caption{Simulation verifying current shunt voltage drops, full simulation screenshot}
    \label{fig:SimulationResults}
\end{sidewaysfigure}

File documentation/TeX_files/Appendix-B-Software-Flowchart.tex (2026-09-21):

% !TeX root = ../main.tex
\chapter{Detailed Software Flowchart}
\label{app:software-flowchart}
This appendix provides the detailed software flow requested for the Week 2
preliminary-design package. It shows the firmware acquisition/alarm loop and the
PSC-to-EPICS data path used by the implemented software.

The software for the Multi-Rail Isolated Power Supply Monitoring System is
maintained with the hardware design files in the project Git repository:

\begin{center}
    \url{https://github.com/capotosto/PS_Monitor}
\end{center}

The repository provides version control for the Arduino GIGA firmware,
hardware-design files, and EPICS IOC software used by the monitoring system.
The embedded firmware is maintained under the \texttt{firmware} portion of the
repository, while the EPICS IOC and associated database/configuration files are
maintained under \texttt{epics-ioc}. The flowcharts in this section describe
the major software operations implemented by these portions of the project.

The Arduino GIGA firmware performs system initialization, acquires voltage and
current measurements from the six LTC2945 monitor channels, evaluates alarm
conditions, updates the local display, and publishes data through the Ethernet interface. The primary firmware execution
sequence is:

\begin{enumerate}
    \item Initialize the GIGA Display, persistent settings, Ethernet interface,
    I\textsuperscript{2}C interface, and channel configuration.

    \item Load stored network parameters and voltage/current alarm limits from
    persistent storage.

    \item Initialize communication with each of the six LTC2945 monitoring
    channels.

    \item Enter the continuous acquisition and communication loop.

    \item Poll each LTC2945 channel for voltage and current measurements.

    \item Verify I\textsuperscript{2}C communication status for each channel.

    \item If communication fails, mark the associated channel with an
    I\textsuperscript{2}C error and prevent invalid measurement data from being
    used.

    \item Convert valid raw measurement data to engineering units and apply the
    appropriate channel polarity and calibration/scaling information.

    \item Compare each voltage and current measurement with its configured
    upper and lower alarm limits.

    \item Update the GIGA Display when measurement values, alarm states, or
    communication states change.

    \item Publish the current measurements and status information through the
    Ethernet PSC protocol interface.

    \item Service incoming configuration requests and store modified settings
    when required.

    \item Repeat the acquisition and communication sequence continuously.
\end{enumerate}

% =====================================================================
\section{Arduino GIGA Firmware Flowchart}
\label{sec:giga-firmware-flowchart}

Figure~\ref{fig:firmware-flowchart} shows the top-level execution flow of the
Arduino GIGA firmware. Following initialization, the controller continuously
acquires data from each monitoring channel, verifies communication, converts
valid measurements to engineering units, evaluates alarm limits, updates the
local display, and services the Ethernet/PSC interface.

\begin{figure}[H]
    \centering

    \begin{adjustbox}{
            max totalsize={0.94\textwidth}{0.88\textheight},
            center
        }

        \begin{tikzpicture}[
            >=Stealth,
            font=\small,
            node distance=0.55cm and 1.6cm,
            process/.style={
                draw,
                rectangle,
                rounded corners=2pt,
                align=center,
                minimum width=5.0cm,
                minimum height=0.80cm,
                text width=4.7cm,
                inner sep=4pt,
                line width=0.8pt
            },
            decision/.style={
                draw,
                diamond,
                aspect=2.4,
                align=center,
                text width=2.8cm,
                inner sep=1pt,
                line width=0.8pt
            },
            terminator/.style={
                draw,
                rectangle,
                rounded corners=8pt,
                align=center,
                minimum width=3.2cm,
                minimum height=0.75cm,
                line width=0.8pt
            },
            arrow/.style={
                ->,
                line width=0.9pt
            },
            flowlabel/.style={
                font=\scriptsize,
                fill=white,
                inner sep=1.5pt
            }
            ]

            % ============================================================
            % INITIALIZATION
            % ============================================================

            \node[terminator] (start)
            {Power-Up / Reset};

            \node[process, below=of start] (init)
            {Initialize GIGA Hardware\\
                Display, I\textsuperscript{2}C, Ethernet, and GPIO};

            \node[process, below=of init] (settings)
            {Load Persistent Configuration\\
                Network Settings and Alarm Limits};

            \node[process, below=of settings] (configure)
            {Configure Six LTC2945 Monitor Channels\\
                and Initialize PSC Communication};

            % ============================================================
            % ACQUISITION LOOP
            % ============================================================

            \node[process, below=0.9cm of configure] (select)
            {Select Next Monitor Channel};

            \node[process, below=of select] (read)
            {Request Voltage and Current\\
                Measurements from LTC2945};

            \node[decision, below=0.70cm of read] (comm)
            {I\textsuperscript{2}C Communication\\Successful?};

            % Error branch
            \node[process, right=2.1cm of comm] (error)
            {Set Channel\\
                I\textsuperscript{2}C Error Status};

            % Valid measurement path
            \node[process, below=0.75cm of comm] (convert)
            {Convert Raw ADC Data to Engineering Units\\
                and Apply Scaling / Rail Polarity};

            \node[process, below=of convert] (alarms)
            {Compare Voltage and Current\\
                Against Configured Alarm Limits};

            \node[decision, below=0.70cm of alarms] (last)
            {Last Channel?};

            % ============================================================
            % SYSTEM UPDATE
            % ============================================================

            \node[process, below=0.75cm of last] (display)
            {Update Changed Display Fields\\
                Measurements, Alarms, and Status};

            \node[process, below=of display] (psc)
            {Publish Measurements and Status\\
                through PSC / Ethernet};

            \node[decision, below=0.70cm of psc] (configreq)
            {Configuration\\Request Received?};

            \node[process, right=2.1cm of configreq] (save)
            {Process Request and Save\\
                Persistent Settings};

            % ============================================================
            % PRIMARY FLOW
            % ============================================================

            \draw[arrow] (start) -- (init);
            \draw[arrow] (init) -- (settings);
            \draw[arrow] (settings) -- (configure);
            \draw[arrow] (configure) -- (select);
            \draw[arrow] (select) -- (read);
            \draw[arrow] (read) -- (comm);

            % Communication successful
            \draw[arrow]
            (comm.south)
            --
            node[flowlabel, right] {Yes}
            (convert.north);

            \draw[arrow] (convert) -- (alarms);
            \draw[arrow] (alarms) -- (last);

            % Communication failure
            \draw[arrow]
            (comm.east)
            --
            node[flowlabel, above] {No}
            (error.west);

            % Error skips conversion/alarm processing
            \draw[arrow]
            (error.south)
            |- (last.east);

            % More channels remain
            \draw[arrow]
            (last.west)
            -- ++(-1.3,0)
            |- node[flowlabel, near start, above] {No}
            (select.west);

            % All six channels complete
            \draw[arrow]
            (last.south)
            --
            node[flowlabel, right] {Yes}
            (display.north);

            \draw[arrow] (display) -- (psc);
            \draw[arrow] (psc) -- (configreq);

            % Configuration request
            \draw[arrow]
            (configreq.east)
            --
            node[flowlabel, above] {Yes}
            (save.west);

            % No configuration request:
            % loop back without dropping below the figure
            \coordinate (loopbottom)
            at ($(configreq.south)+(0,-0.45)$);

            \draw[arrow]
            (configreq.south)
            --
            node[flowlabel, right] {No}
            (loopbottom)
            -| ($(select.west)+(-1.3,0)$)
            |- (select.west);

            % After saving configuration, re-enter acquisition loop
            \draw[arrow]
            (save.south)
            |- ($(configreq.south)+(0,-0.45)$);

        \end{tikzpicture}

    \end{adjustbox}

    \caption{
        Top-level Arduino GIGA firmware flowchart. Following initialization,
        the controller continuously acquires measurements from the six LTC2945
        monitoring channels, validates I\textsuperscript{2}C communication,
        converts valid data to engineering units, evaluates configured alarm
        limits, updates the local display, publishes measurements through the
        PSC/Ethernet interface, and services configuration requests.
    }
    \label{fig:firmware-flowchart}

\end{figure}

\section{PSC and EPICS Communication Flow}
\label{sec:epics-software-flowchart}
% =====================================================================

The Arduino GIGA does not directly implement EPICS Channel Access. Instead,
measurement and status information is transmitted through the Ethernet
interface using the PSC protocol. The EPICS IOC uses PSCDriver to communicate
with the GIGA, maps the received values into EPICS process variables, and makes
those process variables available to the CS-Studio Phoebus operator interface.

This separation allows the embedded controller to remain responsible for
hardware acquisition and local alarm evaluation while the IOC provides the
interface between the embedded hardware and the facility control system.
Figure~\ref{fig:epics-data-flow} summarizes this software data path.

\begin{figure}[H]
    \centering

    \resizebox{0.95\textwidth}{!}{%
        \begin{tikzpicture}[
            >=Stealth,
            node distance=1.25cm,
            process/.style={
                draw,
                rectangle,
                rounded corners=2pt,
                align=center,
                minimum width=3.2cm,
                minimum height=1.5cm,
                text width=3.0cm,
                line width=0.8pt
            },
            arrow/.style={
                ->,
                line width=1.0pt
            },
            siglabel/.style={
                font=\scriptsize,
                fill=white,
                inner sep=2pt,
                rotate=90
            }
            ]

            \node[process] (measure)
            {Arduino GIGA\\[2pt]
                \footnotesize
                Acquire and Process\\
                Measurements};

            \node[process, right=1.5cm of measure] (psc)
            {PSC Protocol\\[2pt]
                \footnotesize
                Package Voltage, Current,\\
                Alarm, and Status Data};

            \node[process, right=1.5cm of psc] (ethernet)
            {Ethernet Interface\\[2pt]
                \footnotesize
                Network Transport};

            \node[process, right=1.5cm of ethernet] (ioc)
            {EPICS IOC / PSCDriver\\[2pt]
                \footnotesize
                Decode Data and Update\\
                EPICS Process Variables};

            \node[process, right=1.5cm of ioc] (phoebus)
            {CS-Studio Phoebus\\[2pt]
                \footnotesize
                Display Measurements,\\
                Alarms, and Status};

            \draw[arrow]
            (measure.east) --
            node[siglabel, midway] {Processed Data}
            (psc.west);

            \draw[arrow]
            (psc.east) --
            node[siglabel, midway] {PSC Messages}
            (ethernet.west);

            \draw[arrow]
            (ethernet.east) --
            node[siglabel, midway] {Ethernet}
            (ioc.west);

            \draw[arrow]
            (ioc.east) --
            node[siglabel, midway] {EPICS Channel Access}
            (phoebus.west);

        \end{tikzpicture}%
    }

    \caption{
        Software communication path from the Arduino GIGA firmware through
        PSCDriver and the EPICS IOC to the CS-Studio Phoebus operator interface.
    }
    \label{fig:epics-data-flow}
\end{figure}

% =====================================================================
\section{Software Configuration Management}
\label{sec:software-configuration}
% =====================================================================

Firmware, IOC configuration files, database definitions, and operator-interface
files are maintained under Git version control so that hardware and software
revisions can be associated with a defined project baseline. The current
software implementation and revision history are available in the
\texttt{PS\_Monitor} repository at:

\begin{center}
    \url{https://github.com/capotosto/PS_Monitor}
\end{center}

Changes made during implementation and testing are committed to the repository,
providing traceability between the preliminary design presented in this report
and the final implemented system. The repository therefore serves as the
controlled source for the firmware and control-system software associated with
the project.

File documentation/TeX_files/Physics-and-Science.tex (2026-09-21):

% !TeX root = ../main.tex
\chapter{Role of Physics and Other Sciences}
\label{chap:physics-science}

To measure the currents of the various supplies, the load current is passed through a shunt resistor for each supply. Ohm's law, \(V=IR\), converts the sampled current into a voltage that can be measured by the LTC2945 PMIC. For example, the digital rail's 2 A current flowing
through a 39 m\(\Omega\) shunt produces a 78 mV differential voltage. The
resistor also converts part of the electrical energy into heat according to
Joule heating, \(P=I^2R\). That same 2 A operating point dissipates 0.156 W in
the shunt. These two equations create the main current-sensor design tradeoff:
a larger resistance produces more measurable voltage and better current
resolution, but also produces greater voltage drop and heat. The selected shunt
must therefore provide adequate ADC signal while remaining comfortably below its
power rating and while causing acceptably small voltage/IR drop to the monitored
rail.

Voltage measurement relies on the physics of electric potential difference and
on analog-to-digital (ADC) conversion. Each LTC2945 is referenced to its own local
power-supply domain via optocouplers, so it can measure the potential of that rail without
requiring all six rails to share a common ground. The converter represents an
analog input with a finite number of digital states. With the LTC2945's 25
mV-per-count resolution, quantization sets the bar for the lower measurable limit. The current channel similarly resolves 25 \(\mu\)V per count across the shunt. Mathematics is required not only to convert the ADC code into volts and amps but also to determine whether the selected shunt and expected signal range make use of the full
ADC span. The calculations in Appendix~\ref{app:design-calculations} explicitly
convert between current, shunt voltage, ADC counts, and measurement resolution.

Galvanic isolation is another important physical concept in the project. Two
circuits can exchange information without sharing a conductive DC path by using
an isolator. In the ACPL-064L, an electrical input drives an LED, which is then detected by a photodiode on the other side, forming an isolated barrier between the two sides of the circuit. The signal crosses the isolation barrier while the two circuit grounds remain
electrically independent. This is important because directly connecting the
returns of floating supplies can create ground loops or force current through a
path that the original power system did not intend. The mathematical treatment
of the isolation interface includes logic voltage limits, LED/interface current,
and the allowable voltage across the isolation barrier. Although the monitored
rails are only in the tens of volts, the isolation components have ratings in excess of 100V, providing ample headroom.

The digital communication buses also depend on basic circuit behavior. An
I\textsuperscript{2}C bus uses open-drain I/O, meaning that devices pull a
line low while a pull-up element or active current source returns it high. Bus
capacitance and pull-up strength determine the line's electrical rise time. Pull ups that are too weak, or too much bus capacitance can prevent a logic-high level from being
reached quickly enough at the selected clock rate. The TCA9803 buffer used in
the design includes an active current source on one side, which eliminates the need to be concerned with setting RC time constants so long as bus capacitance remains below the max for the driver.

Power conversion on the controller hardware also uses electromagnetic energy
storage. The TPS62912 is a switching buck regulator: it alternately connects and
disconnects the input through switching devices while an inductor and capacitors
store and release energy to produce a lower average DC output. The basic
relationships among voltage, current, inductance, capacitance, switching
frequency, ripple, and load determine output quality. For this project the regulator is required to produce a 3.3 V logic rail from a higher input while supplying the display, Ethernet, and interface electronics. The preliminary load estimate is compared with the regulator's output-current rating so the design has sufficient current and thermal margin rather than selecting the regulator only from its nominal output voltage.

Finally, the project relies on mathematics to turn these physical principles
into engineering decisions. Kirchhoff's and Ohm's laws are used to solve the
prototype test network; \(P=VI\), \(P=I^2R\), and related equations are used for
component heating and power budgeting; ADC scale factors are used to convert
between raw counts and engineering units; inequalities define acceptable alarm
regions; and tolerance analysis estimates how resistor error and converter error
propagate into the reported current. The firmware then implements these same
relationships numerically. In this sense the software is not separate from the
physics of the hardware: it is the mathematical model that converts measured
electrical quantities into the voltage, current, alarm, and status information
presented to the user and to EPICS.

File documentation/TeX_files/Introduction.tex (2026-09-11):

% !TeX root = ../main.tex

\chapter{Introduction}
\label{chap:introduction}

\section{Project Overview}

The Multi-Rail Isolated Power Supply Monitoring System is a hardware and
software system developed to provide centralized monitoring of multiple
electrically isolated power-supply rails. The system measures both output
voltage and load current, provides configurable alarm
limits, displays operating status and measurement data via a local display or ethernet for integration with an EPICS-based control system.

The completed system monitors six independent power-supply rails:

\begin{itemize}
    \item +5VA
    \item +5VB
    \item +5V
    \item -5V
    \item +15V
    \item -15V
\end{itemize}

Because the monitored supplies may be electrically isolated from one another,
the monitoring system must preserve that isolation while still allowing all six
channels to communicate with a common controller. Each supply rail therefore
uses an independent voltage/current monitoring channel and an isolated digital
communication path.

The primary controller is an Arduino GIGA R1 WiFi. The controller acquires
measurement data from the individual monitor channels, converts the data to
engineering units, applies the appropriate rail polarity, evaluates configured
alarm limits, and presents the resulting information on a GIGA Display Shield.
An Ethernet interface provides network communication between the embedded
controller and an EPICS Input/Output Controller (IOC). The EPICS IOC then makes
the measurements, alarms, and system status available to a CS-Studio Phoebus
operator interface.

\section{Project Motivation}

Power-supply systems containing multiple isolated voltage rails present a
monitoring challenge because each circuit associated with one supply
can't share a direct electrical reference with another supply.
Connecting conventional measurement or communication circuits across these
references can break isolation between the rails.

A centralized monitor is desirable because it allows the user to observe all supply voltages and currents from a single interface,
identify abnormal operating conditions, detect communication or sensor faults,
and integrate the power-supply status into a larger control system.

The design developed for this project addresses these requirements by
performing voltage and high-side current measurement locally on each monitored
rail and transferring the resulting information across electrically isolated
digital interfaces. The controller receives measurement data from all
six rails without requiring their power references to be directly connected
together.

\section{System Architecture}

The monitoring system is divided into three primary functional areas:
the power-supply monitoring hardware, the microcontroller, and the
supervisory control interface.

The power supply monitoring hardware contains the current-sense resistors,
LTC2945 PMICs, and digital isolation circuitry. Each LTC2945 measures the supply
voltage and the differential voltage developed across a high-side current-sense
resistor. The resulting digital measurement information is sent over the I\textsuperscript{2}C bus while maintaining the required electrical isolation.

The Arduino GIGA R1 WiFi provides the mcu processing functions. Its
firmware initializes the monitoring channels, acquires voltage and current
measurements, detects communication errors, converts raw measurements to
engineering units, applies channel-specific polarity and scaling, evaluates
alarm limits, and updates the local display. Configuration information,
including network parameters and alarm limits, is retained in persistent
storage so that required settings can survive a controller reset or power
cycle.

Network communication is provided through an Ethernet interface using the PSC
protocol. The EPICS IOC communicates with the embedded controller using
PSCDriver and converts the transmitted values into EPICS process variables.
CS-Studio Phoebus provides the remote operator interface for viewing
measurements, alarm conditions, connection status, and system state.

\section{Design Objectives}

The major design objectives for the Multi-Rail Isolated Power Supply Monitoring
System are to:

\begin{enumerate}
    \item Measure the voltage of six independent power-supply rails.

    \item Measure the load current of each rail using high-side current sensing.

    \item Preserve electrical isolation between independently referenced
    power-supply rails and the common controller.

    \item Convert acquired data into meaningful engineering units and correctly
    represent both positive and negative voltage rails.

    \item Detect I\textsuperscript{2}C communication failures and prevent invalid
    sensor data from being presented as valid measurements.

    \item Compare voltage and current measurements against configurable upper and
    lower alarm limits.

    \item Provide a local graphical display of voltage, current, alarm status,
    communication status, and network state.

    \item Retain configuration and alarm settings through controller resets and
    power cycles.

    \item Provide Ethernet communication for remote monitoring and configuration.

    \item Integrate the monitoring system with an EPICS IOC and CS-Studio Phoebus
    operator interface.

    \item Maintain the hardware, firmware, and control-system software under
    revision control so that changes made during design, implementation, and
    testing remain traceable.
\end{enumerate}

\section{Project Scope}

The scope of the project includes the design and implementation of the sensor
interface hardware, Arduino GIGA controller hardware, embedded firmware,
Ethernet communication interface, EPICS IOC, and operator-interface software.
The hardware portion includes the six voltage/current monitoring channels,
current-sense resistors, digital isolation circuitry, controller interface,
Ethernet circuitry, and supporting power-supply circuitry.

The software portion includes the embedded acquisition and alarm-processing
firmware, persistent configuration storage, local display interface, PSC
network communication, EPICS IOC configuration and database records, and the
CS-Studio Phoebus operator interface.

Design files and software associated with the project are maintained in the
project Git repository:

\begin{center}
    \url{https://github.com/capotosto/PS_Monitor}
\end{center}

The repository provides revision control for the hardware design, firmware,
EPICS IOC files, documentation, and other project artifacts generated during
development.

\section{Report Organization}

This report documents the development of the monitoring system from preliminary
design through implementation and testing. The preliminary-design chapter
defines the major functional blocks, presents the system architecture,
documents supporting engineering calculations, includes the hardware
schematics and bills of materials, and describes the primary firmware and
control-system software flows.

Subsequent chapters document prototyping and development activities, the EPICS
IOC implementation, and the CS-Studio Phoebus operator interface. Supporting
project-management and design documents developed during the earlier phases of
the capstone project are retained as part of the overall project documentation
and provide traceability between the original requirements, design decisions,
implementation, and final system.

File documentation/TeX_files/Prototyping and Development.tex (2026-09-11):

% !TeX root = ../main.tex
\chapter{Prototyping and Development}
\label{chap:prototyping-dev}

\section{Introduction}

\section{Testing the LTC2945}
    The LTC2945 testing was carried out using a Linear Tech eval board, DEMO CIRCUIT 1697A. Connections and modifications were made as follows:
    \begin{itemize}
        \item VIN: tied to Arduino +5V
        \item GND: tied to Arduino GND
        \item ADIN: Tied to GND
        \item SCL: Tied to Arduino Pin D8 I2C2 SCL
        \item SDAI/SDAO (JP2 set to TIE): Arduino Pin D9 I2C2 SDA
        \item VPU: Tied to Arduino +3v3
        \item VOUT: Float or tied to dummy load (1k$\Omega$ to 10k$\Omega$)
        \item 20m$\Omega$ shunt replaced with 17$\Omega$ shunt for testing with $\sim$5k$\Omega$ load
        \item Installed 4.7k$\Omega$ pull up on I2C lines via R4, R5 footprints on EVB
    \end{itemize}

    \newpage
    \subsection{Calculating Shunt Value for Test}
    Using the 5V from the arduino as a source, and a load ranging 1k to 10k ohms, we calculate:
    $$R_{L,min}=1k\Omega$$
    $$V_{shunt}=V_S\frac{R_S}{R_L+R_S}$$
    $$R_S=\frac{V_{Shunt}R_L}{V_s-V_{Shunt}}$$
    $$V_{shunt}=0.1024V$$
    $$R_{S,full scale}=\frac{(0.1024V)(1k\Omega)}{5V-0.1024V}=20.91\Omega$$
    Adding some headroom, say, 15\%, and going to an E96 resistor value...
    $$R_S=0.85(20.91)=17.8\Omega$$
    Verifying for the high end of the range:
    $$I_{min}=\frac{5V}{10k\Omega + 17.8\Omega}=499.1\mu A$$
    $$V_{shunt, min}=(499.1\mu A)(17.8\Omega)=8.88mV$$
    The shunt will range from 8.88mV to 87.44mV, within the ADC's usable range of 0V to 102.4mV.

    \newpage
    \subsection{Pictures of Evaluation Board, Display, and Phoebus Panels}
    \begin{figure}[H]
        \centering
        \includegraphics[
        width=3.5in,
        %height=0.85\textwidth,
        keepaspectratio
        ]{Pictures/LTC2945_EVB_Original_Shunt}
        \caption{DEMO CIRCUIT 1697A Eval Board with Original Shunt, fly leads to connect to Arduino.}
    \end{figure}

    \begin{figure}[H]
        \centering
        \includegraphics[
        width=3.5in,
        %height=0.85\textwidth,
        keepaspectratio
        ]{Pictures/LTC2945_EVB_17Ohm_Shunt}
        \caption{DEMO CIRCUIT 1697A Eval Board with 17$\Omega$ Shunt, fly leads to connect to Arduino, and 4.7k$\Omega$ test load.}
    \end{figure}

    \begin{figure}[H]
        \centering
        \includegraphics[
        width=3.5in,
        %height=0.85\textwidth,
        keepaspectratio
        ]{Pictures/ExampleDisplay-Single\_EVB_Connected\_Non-ALM}
        \caption{Arduino Giga with GIGA DISPLAY SHIELD showing dummy -5V rail being monitored, without alarm}
    \end{figure}

    \begin{figure}[H]
    \centering
    \includegraphics[
    width=3.5in,
    %height=0.85\textwidth,
    keepaspectratio
    ]{Pictures/ExampleDisplay-Single\_EVB_Connected\_ALM}
    \caption{Arduino Giga with GIGA DISPLAY SHIELD showing dummy -5V rail being monitored, with UVL alarm, other channels I2C ALARM.}
    \end{figure}

    \begin{figure}[H]
        \centering
        \includegraphics[
        width=3.5in,
        %height=0.85\textwidth,
        keepaspectratio
        ]{Pictures/ExampleDisplay-Single\_EVB\_Connected\_Non-ALM-3k3Load}
        \caption{Arduino Giga with GIGA DISPLAY SHIELD showing dummy -5V rail being monitored, without alarm, 3.3k$\Omega$ Load}
    \end{figure}

    \begin{figure}[H]
        \centering
        \includegraphics[
        width=\textwidth,
        %height=0.85\textwidth,
        keepaspectratio
        ]{Pictures/Phoebus-SS-N5V-Test-3k3Load}
        \caption{Arduino Giga with GIGA DISPLAY SHIELD showing dummy -5V rail being monitored, without alarm, 3.3k$\Omega$ Load}
    \end{figure}

    \begin{figure}[H]
        \centering
        \includegraphics[
        width=\textwidth,
        %height=0.85\textwidth,
        keepaspectratio
        ]{Pictures/EVBArduinoAssembly}
        \caption{Arduino Giga with GIGA DISPLAY SHIELD connected to an LTC2945 eval board}
    \end{figure}

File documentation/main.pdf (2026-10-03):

# Multi-Rail Isolated Power Supply Monitoring System

### Capstone Design Documentation

### Michael Capotosto

### September 30, 2026

Rev. ET450-W3

ii

iii

# Contents

1 Introduction | 1
2 Detailed Design Review | 5
3 Cost Analysis, Design for Manufacturing, and Sustainability | 23
September 30, 2026 | Rev. ET450-W3

iv | CONTENTS
4 Simulation Results | 27
5 Role of Physics and Other Sciences | 29
6 Installing EPICS Base and IOCs | 31
7 CS-Studio - Phoebus | 35
8 Prototyping and Development | 37
A Design Calculations and Circuit Analysis | 45

CONTENTS | v
B Detailed Software Flowchart | 53
C Updated Component List | 57

vi | CONTENTS

# Chapter 1

# Introduction

## 1.1 Project Overview

The Multi-Rail Isolated Power Supply Monitoring System is a hardware and software system developed to provide centralized monitoring of multiple electrically isolated power-supply rails. The system measures both output voltage and load current, provides configurable alarm limits, displays operating status and measurement data via a local display or ethernet for integration with an EPICS-based control system.

The completed system monitors six independent power-supply rails:

- +5VA
- +5VB
- +5V
- -5V
- +15V
- -15V

Because the monitored supplies may be electrically isolated from one another, the monitoring system must preserve that isolation while still allowing all six channels to communicate with a common controller. Each supply rail therefore uses an independent voltage/current monitoring channel and an isolated digital communication path.

The primary controller is an Arduino GIGA R1 WiFi. The controller acquires measurement data from the individual monitor channels, converts the data to engineering units, applies the appropriate rail polarity, evaluates configured alarm limits, and presents the resulting information on a GIGA Display Shield. An Ethernet interface provides network communication between the embedded controller and an EPICS Input/Output Controller (IOC). The EPICS IOC then makes the measurements, alarms, and system status available to a CS-Studio Phoebus operator interface.

## 1.2 Project Motivation

Power-supply systems containing multiple isolated voltage rails present a monitoring challenge because each circuit associated with one supply can’t share a direct electrical reference with another supply. Connecting conventional measurement or communication circuits across these references can break isolation between the rails.

A centralized monitor is desirable because it allows the user to observe all supply voltages and currents from a single interface, identify abnormal operating conditions, detect communication or sensor faults, and integrate the power-supply status into a larger control system.

The design developed for this project addresses these requirements by performing voltage and high-side current measurement locally on each monitored rail and transferring the resulting information across electrically isolated digital interfaces. The controller receives measurement data from all six rails without requiring their power references to be directly connected together.

## 1.3 System Architecture

The monitoring system is divided into three primary functional areas: the power-supply monitoring hardware, the microcontroller, and the supervisory control interface.

The power supply monitoring hardware contains the current-sense resistors, LTC2945 PMICs, and digital isolation circuitry. Each LTC2945 measures the supply voltage and the differential voltage developed across a high-side current-sense resistor. The resulting digital measurement information is sent over the I²C bus while maintaining the required electrical isolation.

The Arduino GIGA R1 WiFi provides the mcu processing functions. Its firmware initializes the monitoring channels, acquires voltage and current measurements, detects communication errors, converts raw measurements to engineering units, applies channel-specific polarity and scaling, evaluates alarm limits, and updates the local display. Configuration information, including network parameters and alarm limits, is retained in persistent storage so that required settings can survive a controller reset or power cycle.

Network communication is provided through an Ethernet interface using the PSC protocol. The EPICS IOC communicates with the embedded controller using PSCDriver and converts the transmitted values into EPICS process variables. CS-Studio Phoebus provides the remote operator interface for viewing measurements, alarm conditions, connection status, and system state.

## 1.4 Design Objectives

The major design objectives for the Multi-Rail Isolated Power Supply Monitoring System are to:

1. Measure the voltage of six independent power-supply rails.
2. Measure the load current of each rail using high-side current sensing.
3. Preserve electrical isolation between independently referenced power-supply rails and the common controller.
4. Convert acquired data into meaningful engineering units and correctly represent both positive and negative voltage rails.
5. Detect I²C communication failures and prevent invalid sensor data from being presented as valid measurements.
6. Compare voltage and current measurements against configurable upper and lower alarm limits.
7. Provide a local graphical display of voltage, current, alarm status, communication status, and network state.
8. Retain configuration and alarm settings through controller resets and power cycles.
9. Provide Ethernet communication for remote monitoring and configuration.
10. Integrate the monitoring system with an EPICS IOC and CS-Studio Phoebus operator interface.
11. Maintain the hardware, firmware, and control-system software under revision control so that changes made during design, implementation, and testing remain traceable.

## 1.5 Project Scope

The scope of the project includes the design and implementation of the sensor interface hardware, Arduino GIGA controller hardware, embedded firmware, Ethernet communication interface, EPICS IOC, and operator-interface software. The hardware portion includes the six voltage/current monitoring channels, current-sense resistors, digital isolation circuitry, controller interface, Ethernet circuitry, and supporting power-supply circuitry.

The software portion includes the embedded acquisition and alarm-processing firmware, persistent configuration storage, local display interface, PSC network communication, EPICS IOC configuration and database records, and the CS-Studio Phoebus operator interface.

Design files and software associated with the project are maintained in the project Git repository:

https://github.com/capotosto/PS_Monitor

The repository provides revision control for the hardware design, firmware, EPICS IOC files, documentation, and other project artifacts generated during development.

## 1.6 Report Organization

This report documents the development of the monitoring system from preliminary design through implementation and testing. The preliminary-design chapter defines the major functional blocks, presents the system architecture, documents supporting engineering calculations, includes the hardware schematics and bills of materials, and describes the primary firmware and control-system software flows.

Subsequent chapters document prototyping and development activities, the EPICS IOC implementation, and the CS-Studio Phoebus operator interface. Supporting project-management and design documents developed during the earlier phases of the capstone project are retained as part of the overall project documentation and provide traceability between the original requirements, design decisions, implementation, and final system.

# Chapter 2

# Detailed Design Review

The preliminary architecture has been carried forward into this detailed implementation of six galvanically isolated V/I measurement channels, an Arduino Giga R1 micro, display module, ethernet interface, EPICS IOC, and Phoebus control panels. The monitored rails in this design are digital supplies +5VA, +5VB, and analog voltages +/-5V, and +/-15V. Component-level ratings, procurement, and porduction cost impacts are reviewed in the BOM and cost analysis sections of the following review.

## 2.1 Purpose and Scope

This chapter documents the hardware and software design of the Multi-Rail Isolated Power Supply Monitoring System. The design monitors six power-supply rails, measures rail voltage and load current, preserves electrical isolation between floating supplies and the controller, evaluates measurements against user-configurable alarm limits, presents local status on the controller display, and publishes measurements and status to an EPICS control-system interface.

This design is intended to establish the major analog and digital functional blocks, document supporting engineering calculations, define the hardware schematic baseline, and provide software flowcharts detailed enough to support implementation.

## 2.2 Problem Definition

The project addresses the need to monitor several low-voltage power-supply rails that do not necessarily share a common reference. A conventional monitoring circuit that directly connects the grounds together would defeat the electrical isolation of the supplies and could create unwanted return paths. However, the user needs a single location from which to observe rail voltage, rail current, alarm state, communication status, and the overall condition of the power system.

The required monitoring system must therefore make accurate measurements on six separate rails while preserving isolation between the monitored domains. It must support both positive and negative rails, detect sensor or communication faults, provide configurable voltage and current limits, retain configuration information after reset, present useful local status, and make the same data available to the facility control system over Ethernet. The monitored rails in the present design are +5 V A, +5 V B, +/-5 V, and +/-15 V.

## 2.3 Proposed Solution

The proposed solution assigns one LTC2945 voltage/current monitor to each power rail. Load current is converted to a small differential voltage by a precision high-side shunt resistor and the LTC2945 digitizes both the shunt voltage and the rail voltage. Each sensor remains referenced to its own monitored supply domain. The I²C communication path is then isolated so that digital measurement data can be transferred to a common Arduino GIGA R1 WiFi controller without directly bonding the isolated supply returns together.

The Arduino GIGA performs channel acquisition, engineering-unit conversion, negative-rail sign handling, alarm evaluation, configuration storage, display updates, and network communication. A local GIGA Display Shield provides immediate status at the hardware. Ethernet transports measurement and status data using the PSC protocol to an EPICS IOC, where PSCDriver and EPICS records make the values available to a CS-Studio Phoebus operator interface. This architecture separates the rail-side analog measurement functions from the controller and supervisory-control functions while maintaining a single user interface for the complete system.

## 2.4 Chosen Conceptual Design and Functional Block Diagram

The major system functions are summarized below.

1. Power-Supply Interface: Connect to the six monitored rails and route each rail through the associated voltage/current monitoring channel.
2. Current Measurement: Convert load current to a differential voltage across a precision shunt resistor and digitize it with the LTC2945.
3. Voltage Measurement: Measure the monitored rail voltage using the LTC2945 supply-voltage ADC channel.
4. Electrical Isolation: Maintain galvanic isolation between each floating monitored supply and the common controller-side I²C bus.
5. Digital Acquisition: Poll each monitor, identify communication faults, apply channel-specific sign/scaling information, and calculate engineering-unit values.

6. Alarm Processing: Compare voltage and current values against configured upper and lower limits and generate channel alarm states.
7. Local User Interface: Present all rail measurements, alarms, network state, and communication status on the Arduino GIGA Display.
8. Network/EPICS Interface: Publish measurements, alarm limits, alarm state, and connection status over Ethernet for the EPICS IOC and Phoebus interface.

2.4.1 | Functional Block Diagram +⁶ V A | +⁶ V B | +⁵ V

Figure 2.1: Functional block diagram of the multi-rail isolated power supply monitoring system. Six independent
power-supply rails are measured using high-side current sensing and LTC2945 voltage/current monitoring channels.

Digital isolation preserves electrical independence between the monitored supplies and the common controller. The
Arduino GIGA processes the measurements, provides a local operator display, and transmits measurement and

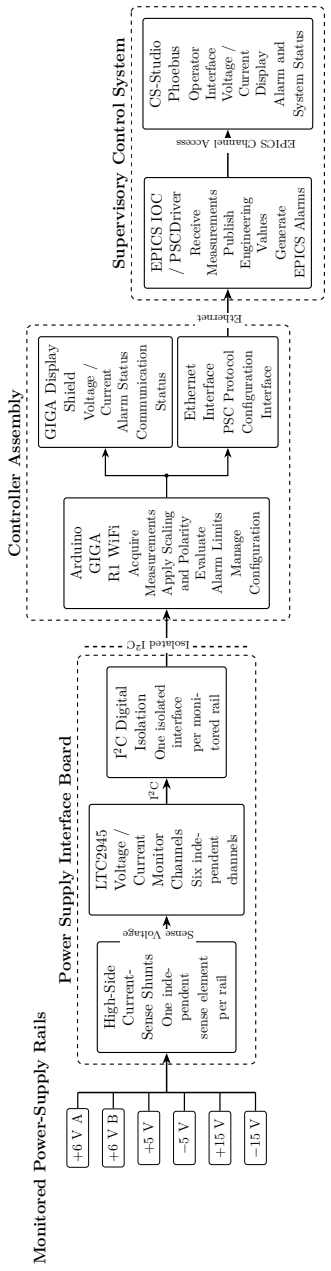
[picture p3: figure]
Monitored Power-Supply Rails; High-Side; Current-; Sense Shunts; One inde-; pendent; sense element; per rail; LTC2945; Voltage /; Current; Monitor; Channels; Six inde-; channels; 2C Digital; Isolation; One isolated; interface; per moni-; tored rail; Power Supply Interface Board Arduino; GIGA; R1 WiFi; Acquire; Measurements; Apply Scaling; and Polarity; Evaluate; Alarm Limits; Manage; Configuration; GIGA Display; Shield; Alarm Status; Communication; Status; Ethernet; Interface; PSC Protocol; Controller Assembly; EPICS IOC; / PSCDriver; Receive; Publish; Engineering; Values; Generate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

status information over Ethernet to the EPICS IOC and CS-Studio Phoebus operator interface.

## 2.5 Engineering Calculations

## 2.6 Functional Specifications

The functional specifications used for the design are summarized in Table 2.1. These values define the intended operating envelope of the prototype and establish the quantities that must be checked during circuit analysis and later verification testing.

Table 2.1: Functional specifications.

Function | Specification
Monitored rails | +5 V A, +5 V B, +5 V, -5 V, +15 V, and -15 V
Number of channels | Six independent voltage/current measurement channels
+5 V A/B current range 0 to 2 A design range per rail
+5 V, -5 V, +15 V, -15 V current range | 0 to 1 A design range per rail
Voltage measurement resolution | 25 mV/LSB nominal using the LTC2945 rail-voltage ADC
Current-sense resolution | 25 µV/LSB across the selected shunt resistor; approximately
| 0.641 mA/LSB with 39 mΩ and 0.500 mA/LSB with 50 mΩ
Isolation | Independent digital isolation for every floating monitor channel
Alarm processing | User-configurable upper/lower voltage and current limits with
| local and EPICS status indication
Fault handling | Detect failed I²C transactions and prevent invalid data from
| being treated as a valid measurement
Local interface | GIGA Display Shield showing voltage, current, alarm state,
| communication state, and configured limits
Network interface | Ethernet PSC server for EPICS IOC communication plus
| browser-based configuration/monitoring services
Configuration retention | Network parameters and alarm limits stored in nonvolatile
| memory
Controller logic level | 3.3 V; external interfaces must not exceed the GIGA I/O limits

## 2.7 Design Methodology

The design was developed by dividing the system into measurement, isolation, controller, user-interface, and control-system functions and then verifying the interfaces between those blocks. The analog measurement design began with the maximum required rail current. The shunt value was selected so that the maximum nominal current produces a differential voltage comfortably below the LTC2945 102.4 mV current-sense full-scale value. Power dissipation in each shunt was then calculated using P = I

| 2R, and the selected resistor rating was
checked against the calculated worst-case dissipation. The same approach was used for PCB copper: maximum continuous current, allowable temperature rise, and voltage drop were considered before final trace and copper-pour dimensions were chosen. Detailed calculations are included in Appendix A.

Electrical isolation was treated as a system-interface requirement rather than only a componentselection problem. Each LTC2945 remains electrically local to its rail, and the digital signals cross the isolation boundary through isolated logic. Controller-side I²C buffering and level compatibility were checked against 3.3 V logic requirements. The controller does not drive loads directly; its GPIO and I²C pins only interface to logic-level circuitry. This substantially reduces the current demanded from an individual microcontroller pin and allows the high-current rail paths to remain on the dedicated sensor hardware.

The embedded-software design follows the same functional partitioning. Sensor acquisition is separated from display formatting, network services, persistent storage, and PSC message handling. Alarm processing is performed on engineering-unit values after channel polarity and scaling are applied. The EPICS IOC is intentionally kept outside the embedded controller so that the Arduino is responsible for hardware acquisition while the IOC is responsible for exposing process variables to the remote user control system.

## 2.8 Design Schematics

The hardware schematics are maintained in KiCad and are included below directly from the plotted PDF files in the project hardware directory.

### 2.8.1 Sensor Board Schematic

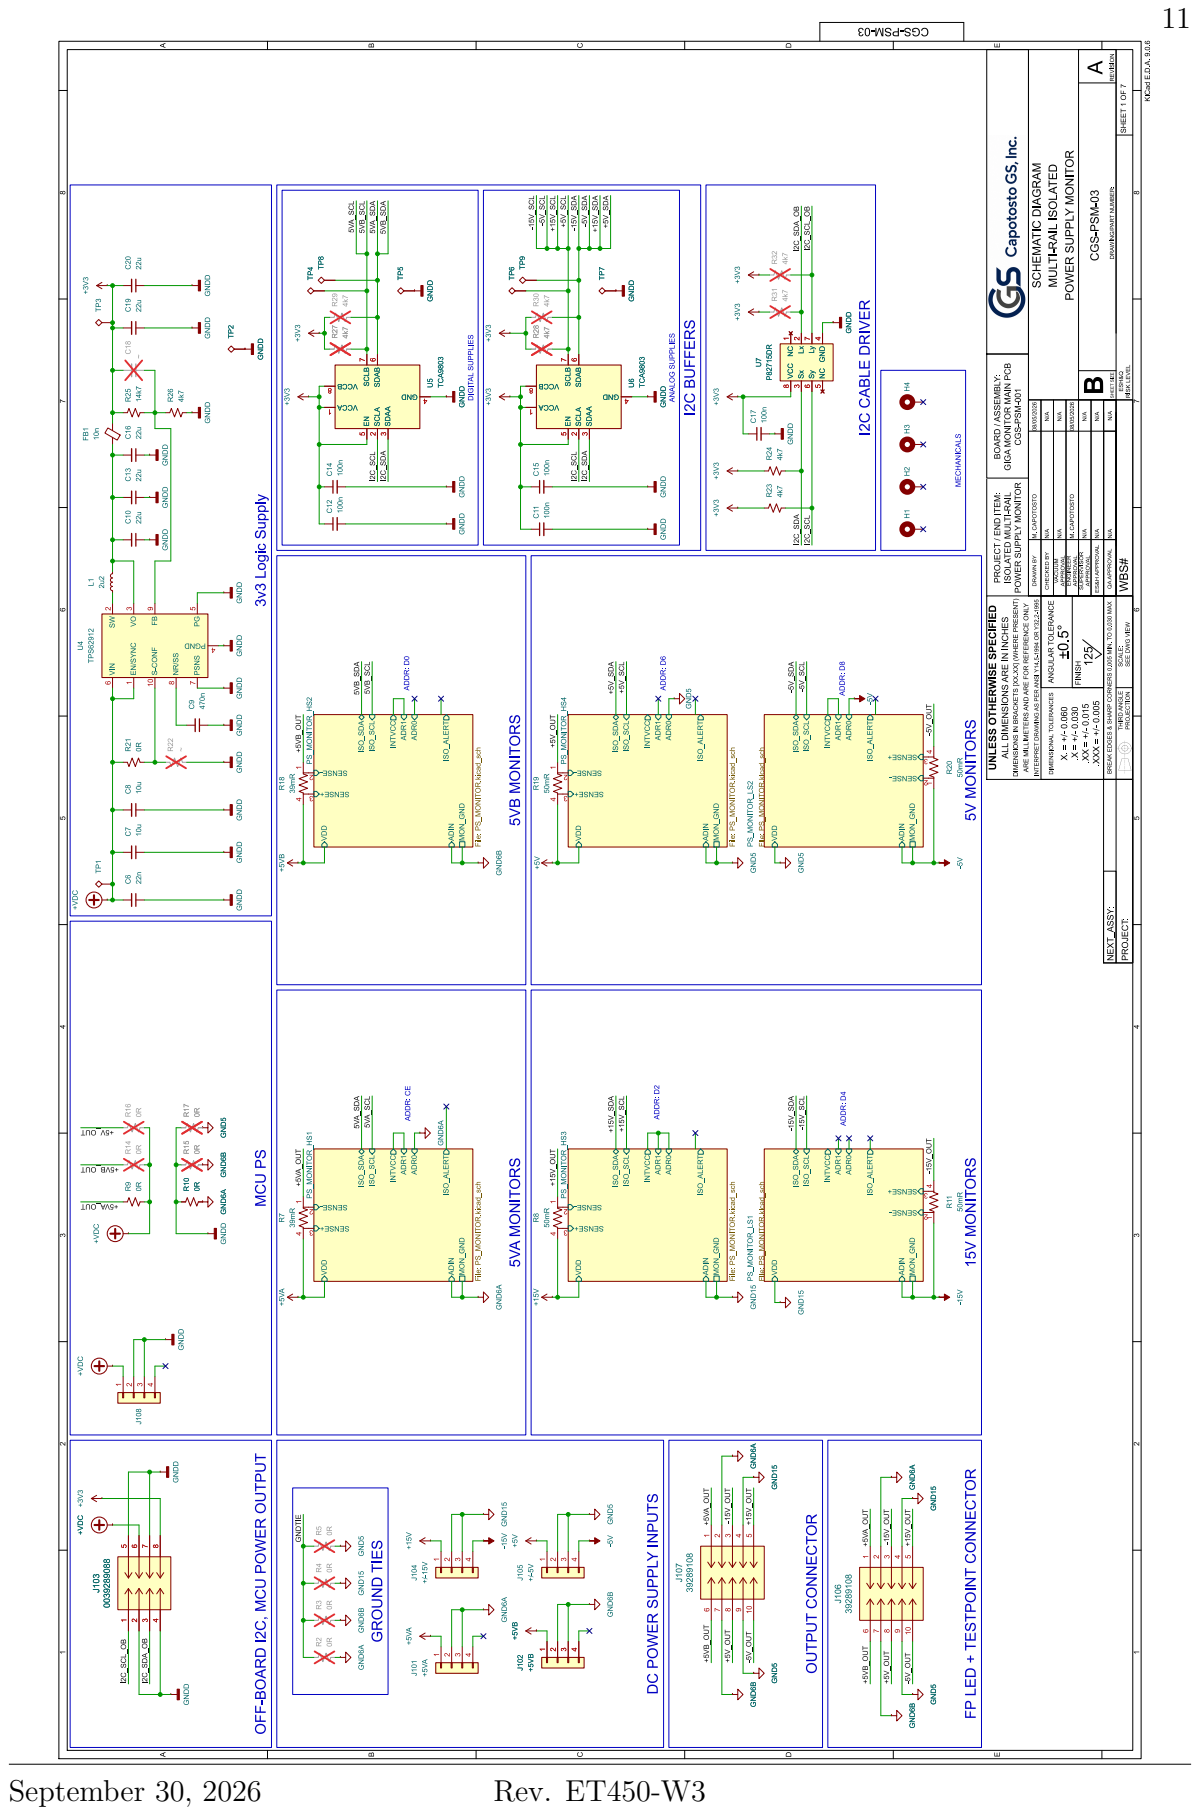
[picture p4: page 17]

KiCad E.D.A. 9.0.6 POWER SUPPLY MONITOR

RISK LEVEL SHEET 1 OF 7 A

SHEET SIZE REVISION DRAWING/PART NUMBER: ESH&Q

TP2 TP8 TP4TP9 TP6 U6 TCA9803 EN 5 SCLA 2 SDAA 3 VCCA

TP5 EN 5 SCLA 2 SDAA 3 VCCA

TP5 U5 TCA9803 EN 5 SCLA 2 SDAA 3 VCCA

Ly 7 GND 4 VCC 8 Sx 3 Sy 6 NC 5 U7 P82715DR R31

CGS-PSM-001 PROJECT / END ITEM:

ADDR: D4 ADDR: D2 ADDR: D0 ADDR: D8 ADDR: D6 GNDD

Ly 7 GND 4 VCC 8 Sx 3 Sy 6 NC 5 GND5 GND6B GND6A GND15 GND5 GND6B GND15GND6A GNDD

GIGA MONITOR MAIN PCB

100n EN 5 SCLA 2 SDAA 3 VCCA

DRAWN BY QA APPROVAL SUPERVISOR

SEE DWG VIEW THIRD ANGLE

PROJECTION UNLESS OTHERWISE SPECIFIED

ALL DIMENSIONS ARE IN INCHES

DIMENSIONS IN BRACKETS [XX.XX] (WHERE PRESENT) ARE MILLIMETERS AND ARE FOR REFERENCE ONLY

INTERPRET DRAWING AS PER ANSI Y14.5-1994 OR Y32.2-1995 NEXT_ASSY:

BREAK EDGES & SHARP CORNERS 0.005 MIN. TO 0.030 MAX

VIN 6 EN/SYNC 1 S-CONF 10 NR/SS 8 PSNS 7 PGND

MCU PS OFF-BOARD I2C, MCU POWER OUTPUT

FP LED + TESTPOINT CONNECTOR

DC POWER SUPPLY INPUTS

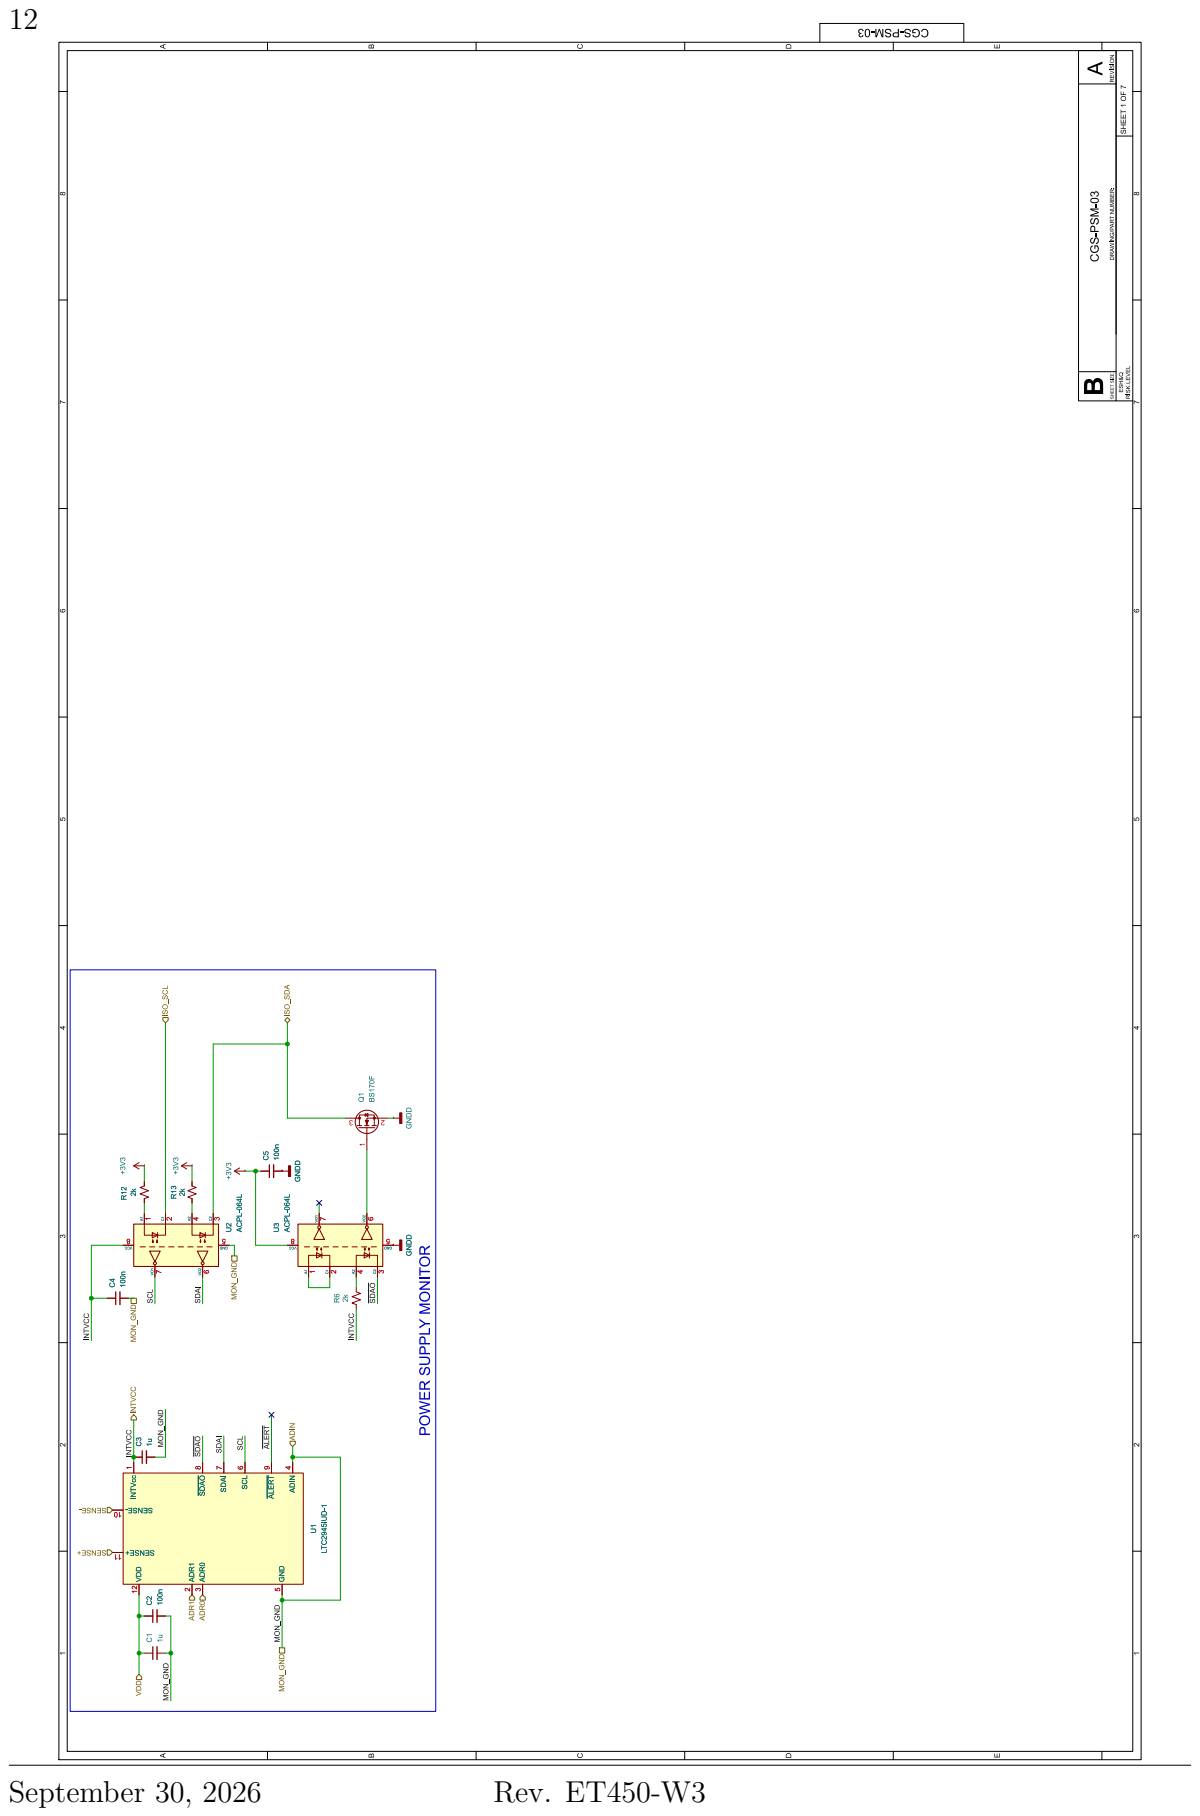
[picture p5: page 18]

RISK LEVEL SHEET 1 OF 7 A CGS-PSM-03 B

SHEET SIZE REVISION DRAWING/PART NUMBER: ESH&Q

INTVcc 1 ~{SDAO}8 SDAI 7 SCL 6 ~{ALERT}9 ADIN 4 C3

INTVcc 1 ~{SDAO}8 SDAI 7 SCL 6 ~{ALERT}9 ADIN 4 U1

LTC2945IUD-1 VDD 12 ADR1 2 ADR0 3 GND 5 SENSE+ 11 SENSE- 10

1u VDD 12 ADR1 2 ADR0 3 GND 5 SENSE+ 11 SENSE- 10

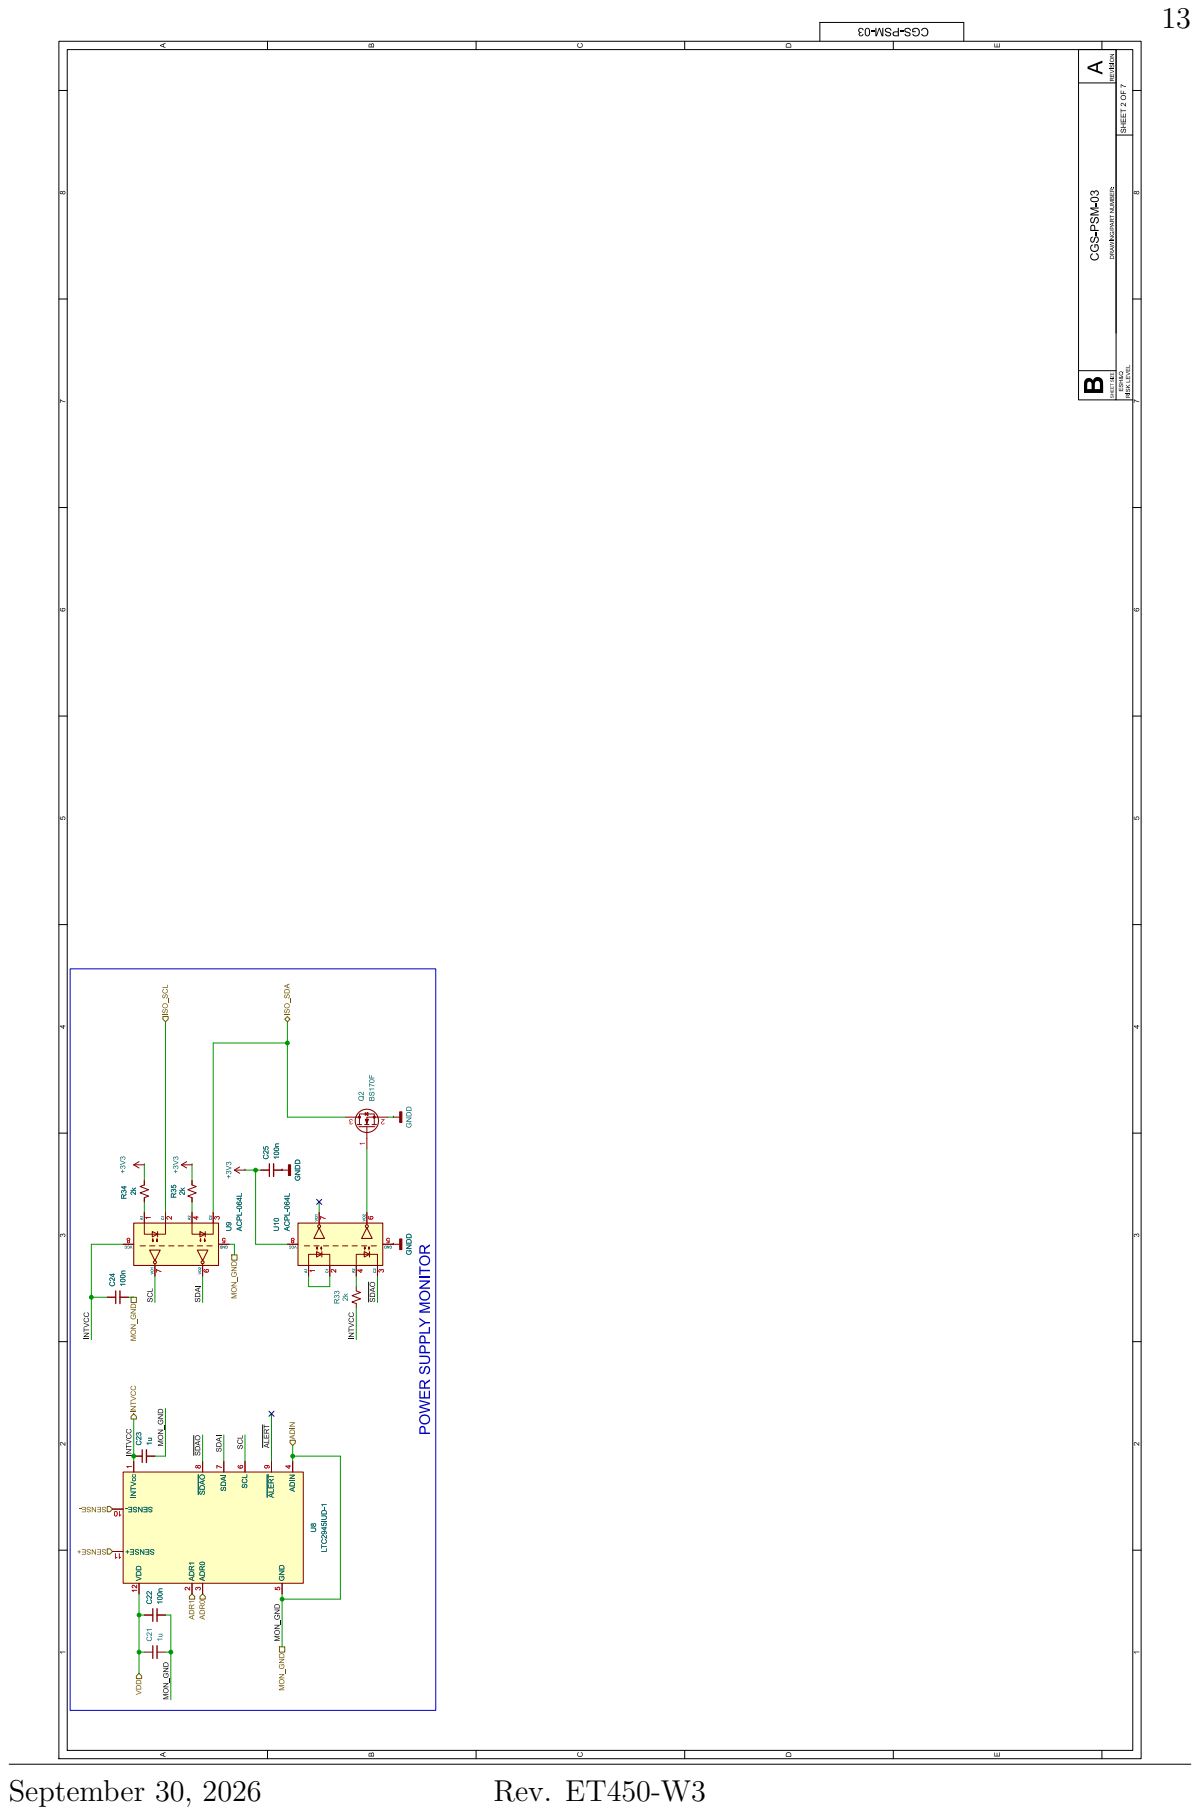
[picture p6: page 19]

RISK LEVEL SHEET 2 OF 7 A CGS-PSM-03 B

SHEET SIZE REVISION DRAWING/PART NUMBER: ESH&Q

~{SDAO} SCLPOWER SUPPLY MONITOR

1u VDD 12 ADR1 2 ADR0 3 GND 5 SENSE+ 11 SENSE- 10

INTVcc 1 ~{SDAO}8 SDAI 7 SCL 6 ~{ALERT}9 ADIN 4 C23

INTVcc 1 ~{SDAO}8 SDAI 7 SCL 6 ~{ALERT}9 ADIN 4 U8

LTC2945IUD-1 VDD 12 ADR1 2 ADR0 3 GND 5 SENSE+ 11 SENSE- 10

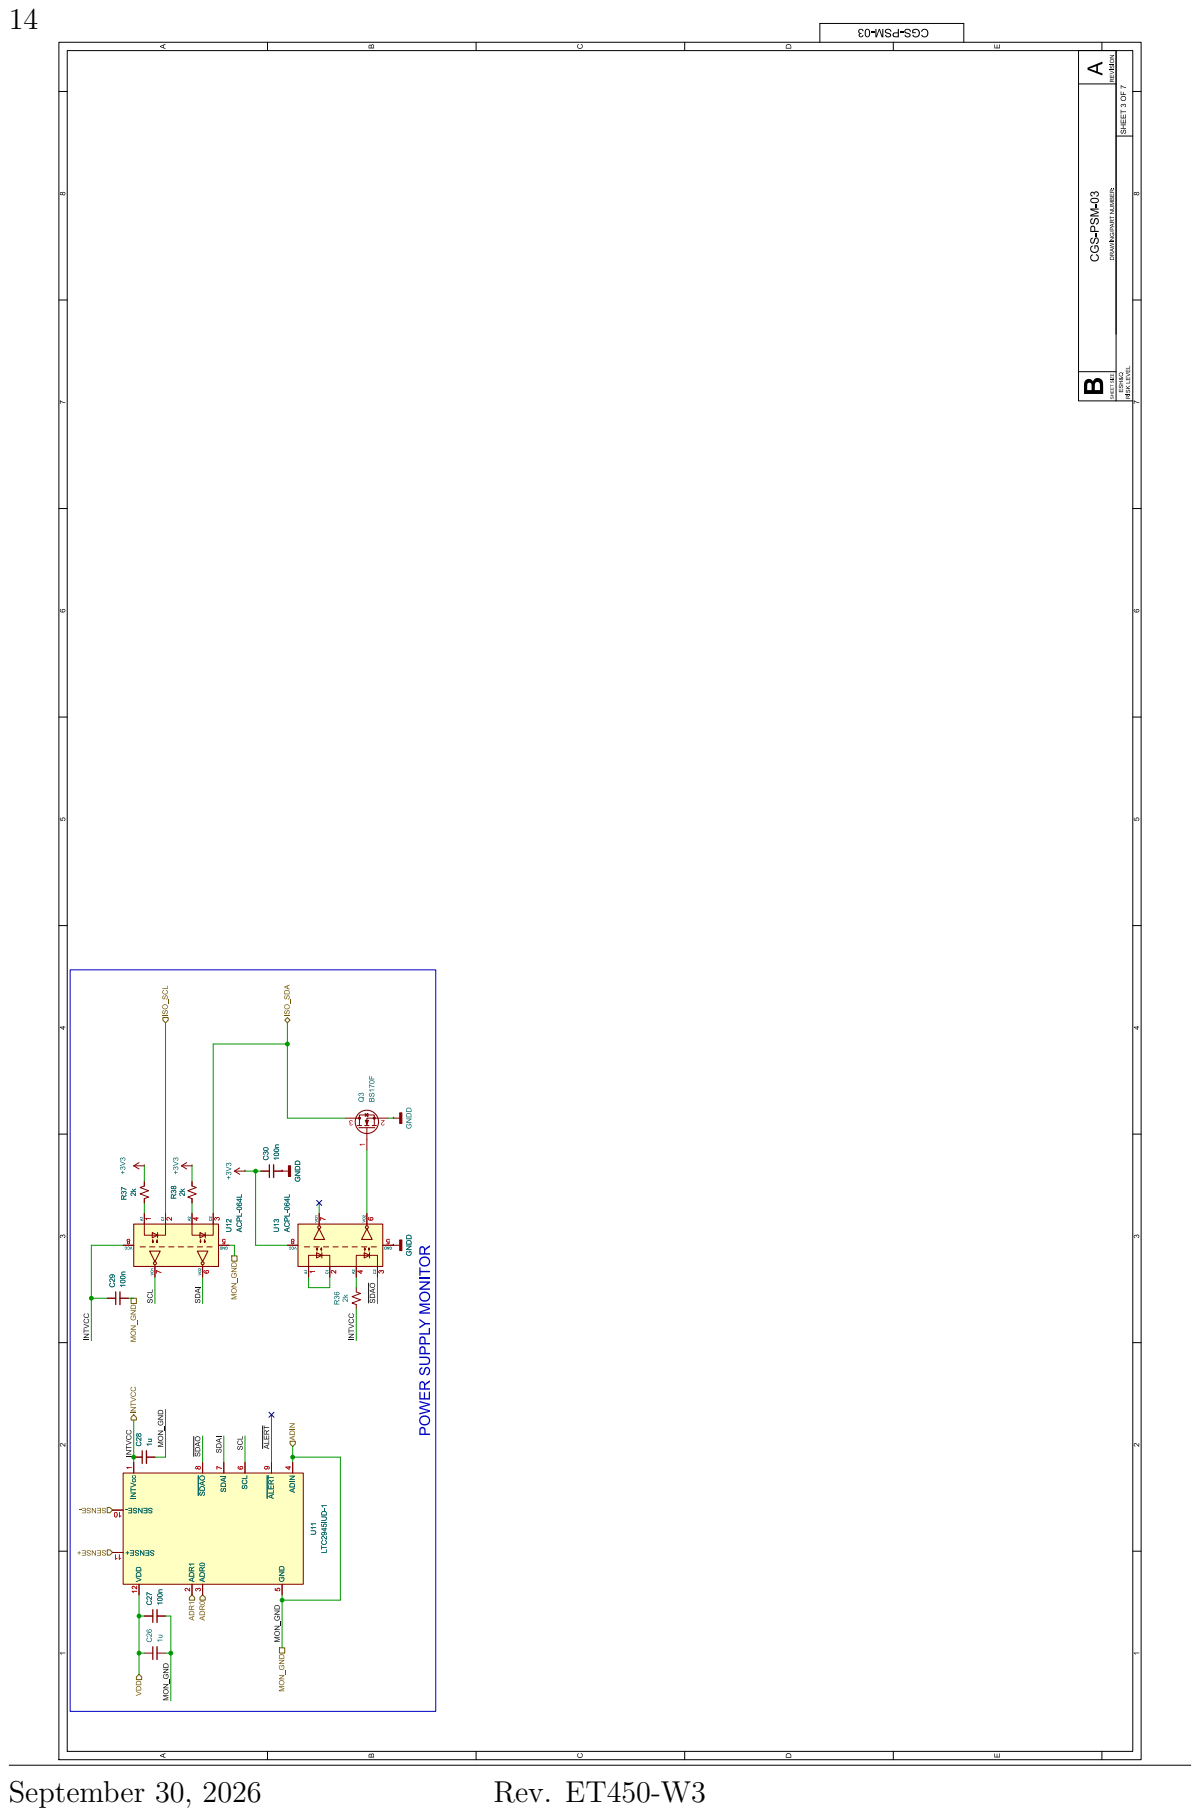
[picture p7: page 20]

RISK LEVEL SHEET 3 OF 7 A CGS-PSM-03 B

SHEET SIZE REVISION DRAWING/PART NUMBER: ESH&Q

2k +3V3 +3V3 VDD 12 ADR1 2 ADR0 3 GND 5 SENSE+ 11 SENSE- 10

~{ALERT} SDAI SDAI SCL

INTVcc 1 ~{SDAO}8 SDAI 7 SCL 6 ~{ALERT}9 ADIN 4 U11

INTVcc 1 ~{SDAO}8 SDAI 7 SCL 6 ~{ALERT}9 ADIN 4 C27

LTC2945IUD-1 VDD 12 ADR1 2 ADR0 3 GND 5 SENSE+ 11 SENSE- 10

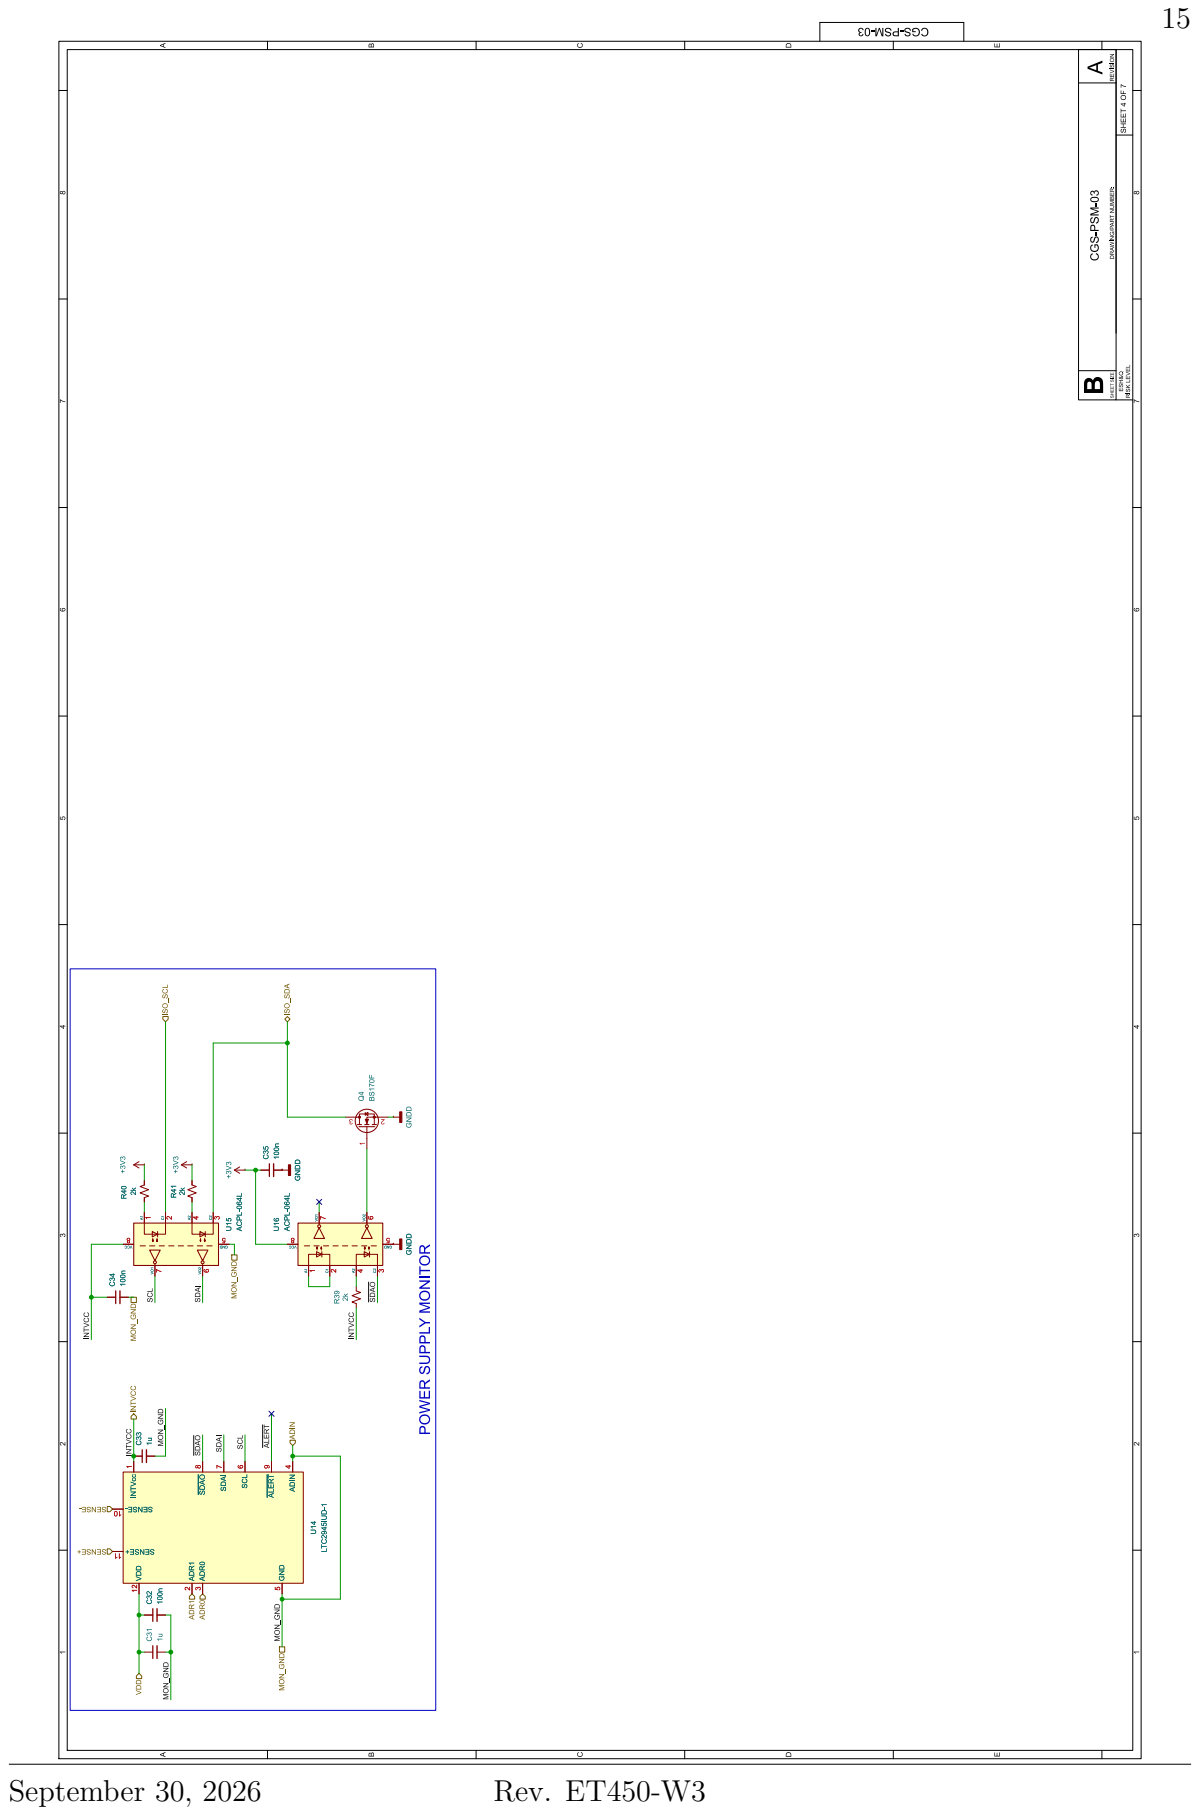
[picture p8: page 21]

RISK LEVEL SHEET 4 OF 7 A CGS-PSM-03 B

SHEET SIZE REVISION DRAWING/PART NUMBER: ESH&Q

INTVCC POWER SUPPLY MONITOR

~{ALERT} SDAI SDAI SCL

INTVcc 1 ~{SDAO}8 SDAI 7 SCL 6 ~{ALERT}9 ADIN 4 U14

INTVcc 1 ~{SDAO}8 SDAI 7 SCL 6 ~{ALERT}9 ADIN 4 C32

LTC2945IUD-1 VDD 12 ADR1 2 ADR0 3 GND 5 SENSE+ 11 SENSE- 10

1u VDD 12 ADR1 2 ADR0 3 GND 5 SENSE+ 11 SENSE- 10

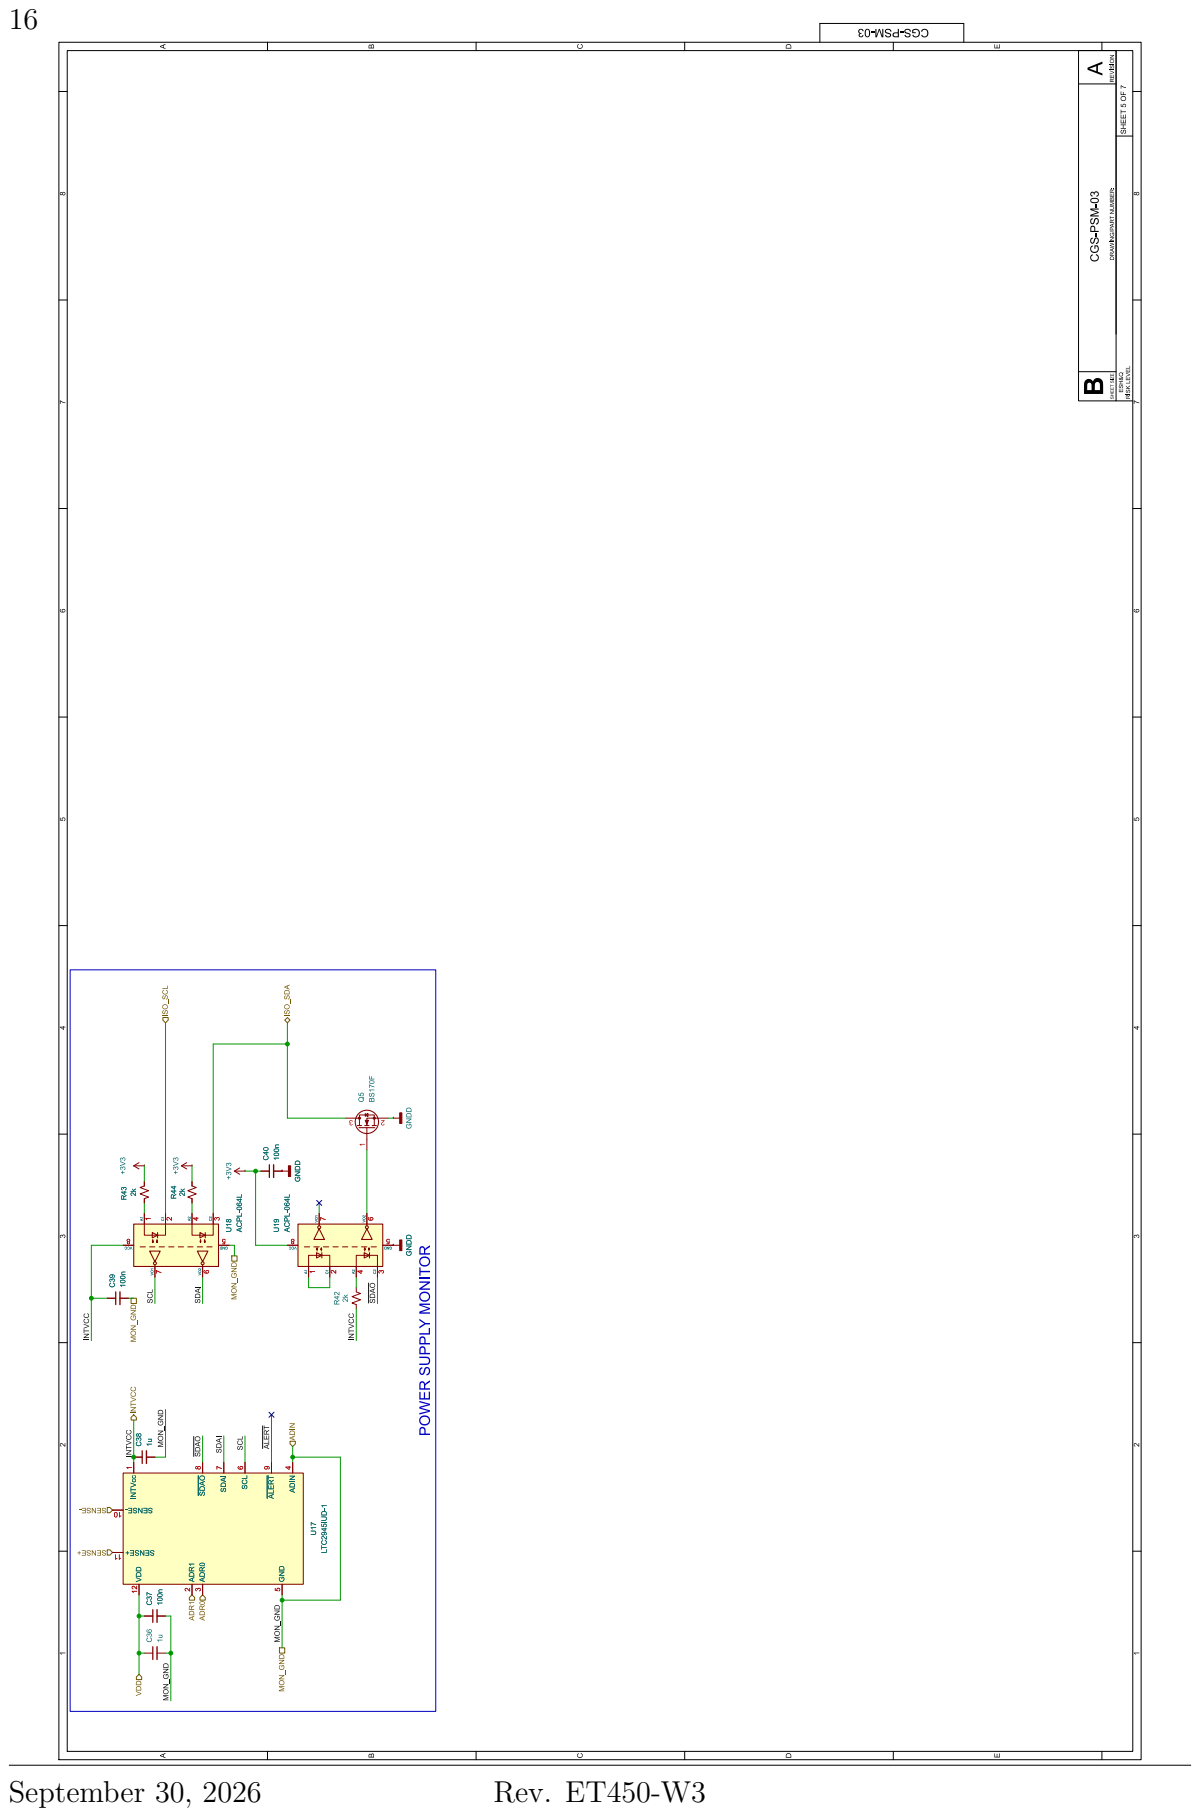
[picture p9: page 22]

RISK LEVEL SHEET 5 OF 7 A CGS-PSM-03 B

SHEET SIZE REVISION DRAWING/PART NUMBER: ESH&Q

~{ALERT} SDAI SDAI SCL

INTVcc 1 ~{SDAO}8 SDAI 7 SCL 6 ~{ALERT}9 ADIN 4 C38

INTVcc 1 ~{SDAO}8 SDAI 7 SCL 6 ~{ALERT}9 ADIN 4 U17

LTC2945IUD-1 VDD 12 ADR1 2 ADR0 3 GND 5 SENSE+ 11 SENSE- 10

VDD 12 ADR1 2 ADR0 3 GND 5 SENSE+ 11 SENSE- 10

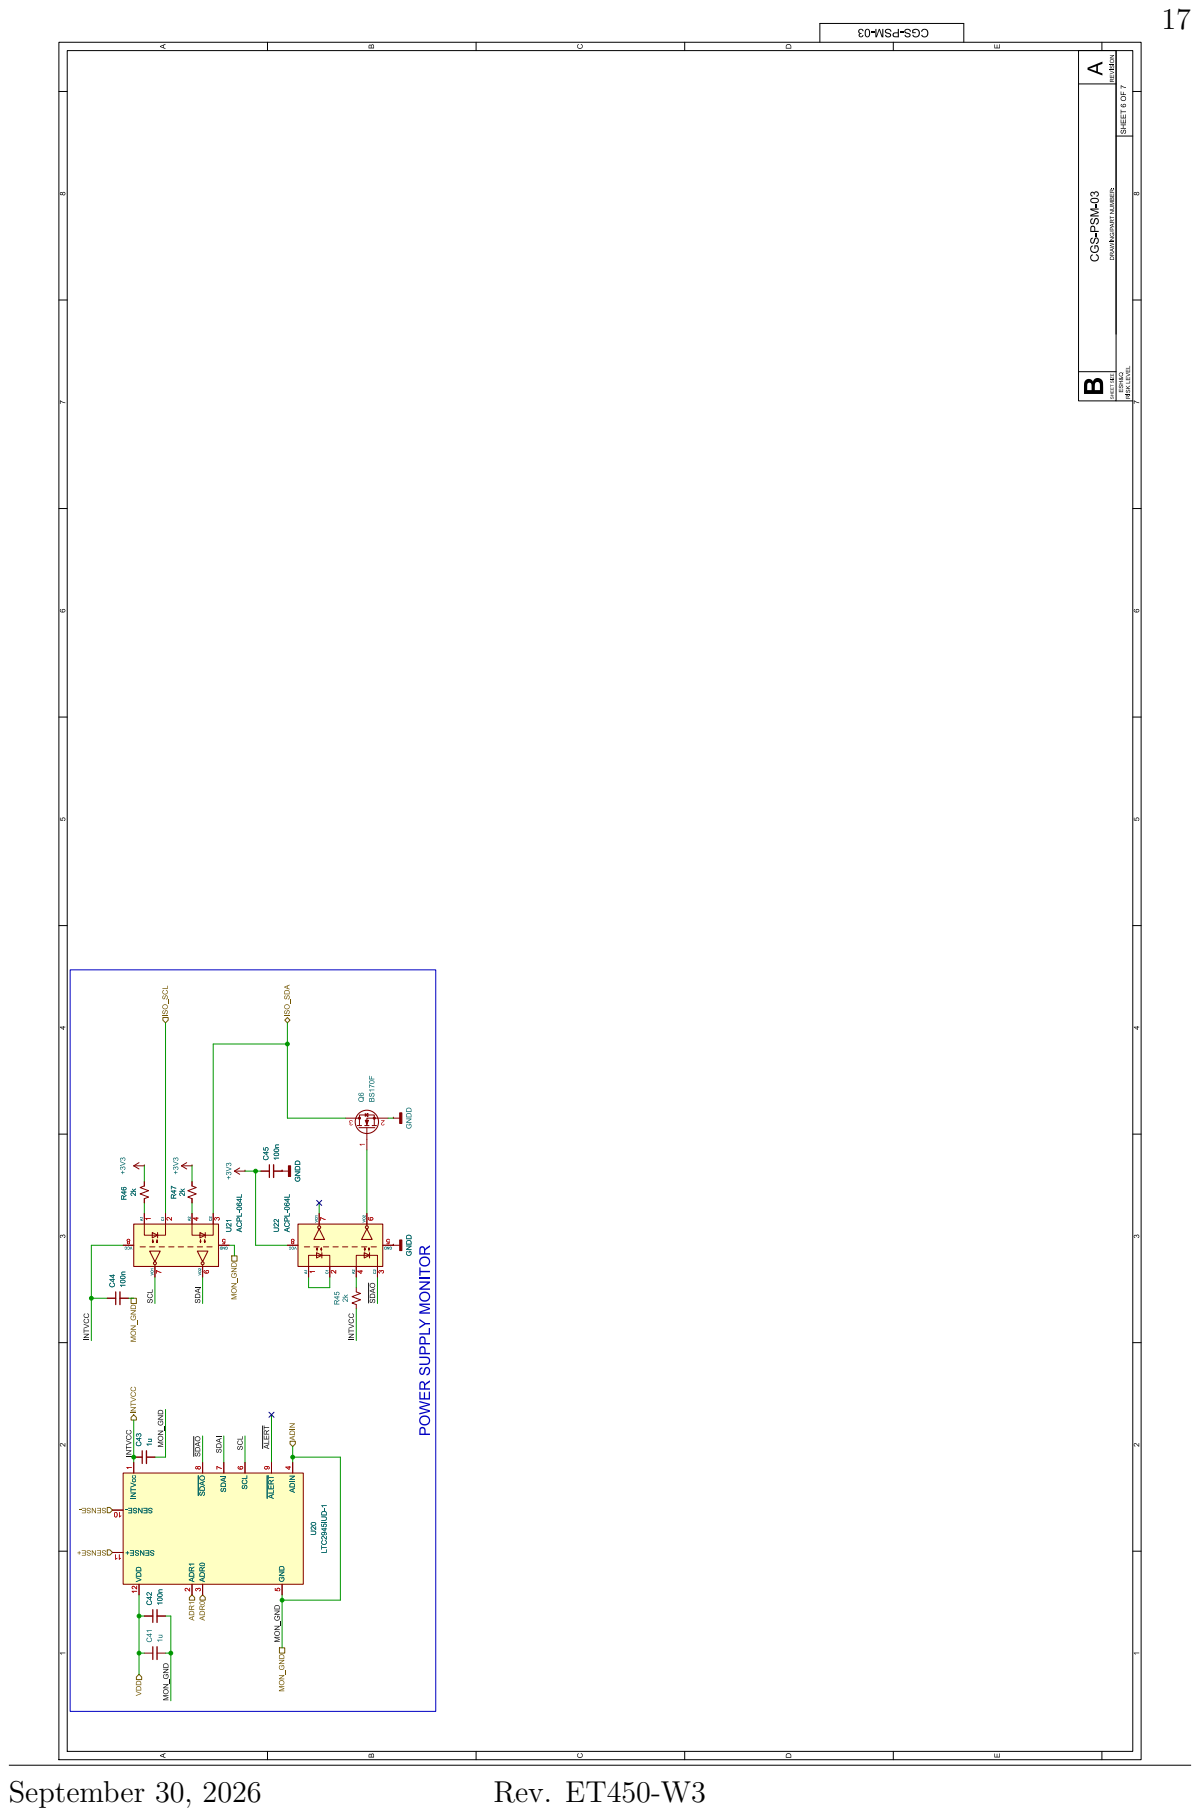
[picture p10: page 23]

RISK LEVEL SHEET 6 OF 7 A CGS-PSM-03 B

SHEET SIZE REVISION DRAWING/PART NUMBER: ESH&Q

~{ALERT} SDAI SDAI SCL

INTVcc 1 ~{SDAO}8 SDAI 7 SCL 6 ~{ALERT}9 ADIN 4 U20

INTVcc 1 ~{SDAO}8 SDAI 7 SCL 6 ~{ALERT}9 ADIN 4 C42

LTC2945IUD-1 VDD 12 ADR1 2 ADR0 3 GND 5 SENSE+ 11 SENSE- 10
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

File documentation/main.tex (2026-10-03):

% !TeX TXS-program:compile = txs:///pdflatex/[--shell-escape]
\documentclass[letterpaper,12pt]{book}

\pdfminorversion=7

\input {preamble}

\begin{document}
    \frontmatter
    \maketitle
    \tableofcontents
%    \listoffigures
%    \listoftables

    \mainmatter
    \pagestyle{fancy}

    \include{./TeX_files/Introduction}
    \include{./TeX_files/Detailed-Design}
    \include{./TeX_files/Cost-Analysis}
    \include{./TeX_files/Simulations}
    \include{./TeX_files/Physics-and-Science}
    \include{./TeX_files/IOCs}
    \include{./TeX_files/CS-Studio-Phoebus}
    \include{./TeX_files/Prototyping and Development}

    \appendix
    \include{./TeX_files/Appendix-A-Design-Calculations}
    \include{./TeX_files/Appendix-B-Software-Flowchart}
    \include{./TeX_files/Appendix-C-Component-List}

    \backmatter
    % bibliography, glossary and index would go here.

\end{document}

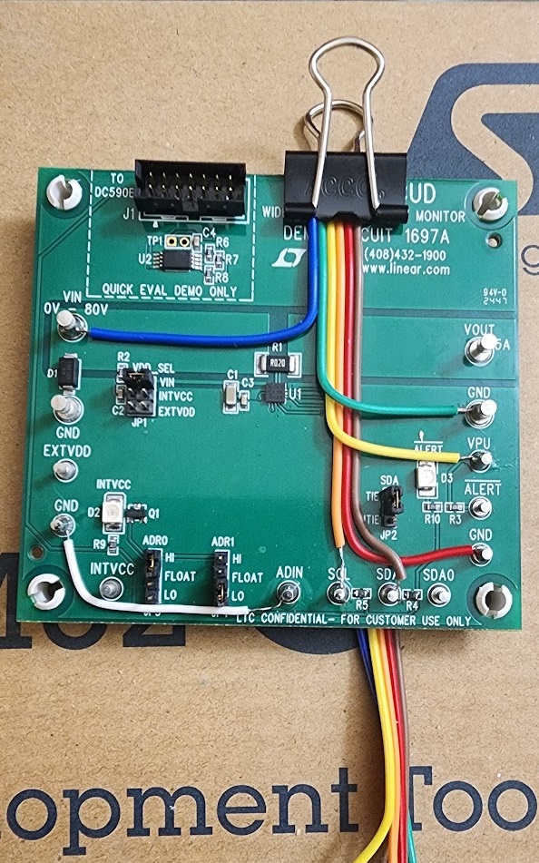
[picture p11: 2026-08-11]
documentation/Pictures/LTC2945_EVB_Original_Shunt.jpg

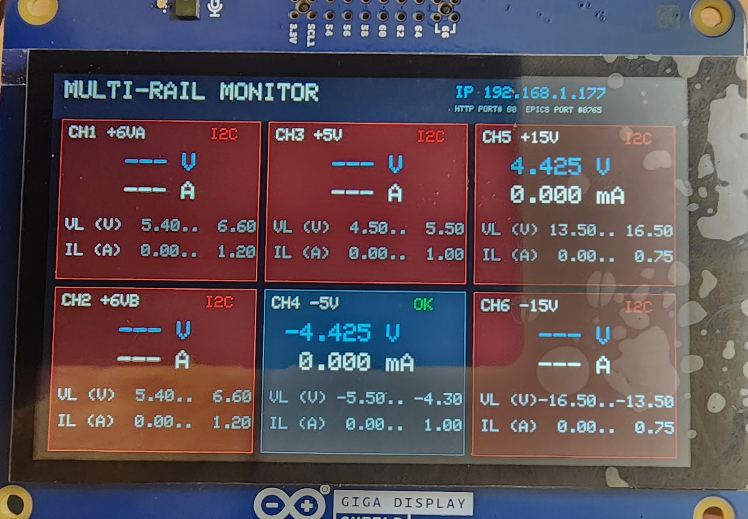
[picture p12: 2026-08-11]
documentation/Pictures/ExampleDisplay-Single_EVB_Connected_Non-ALM.jpg

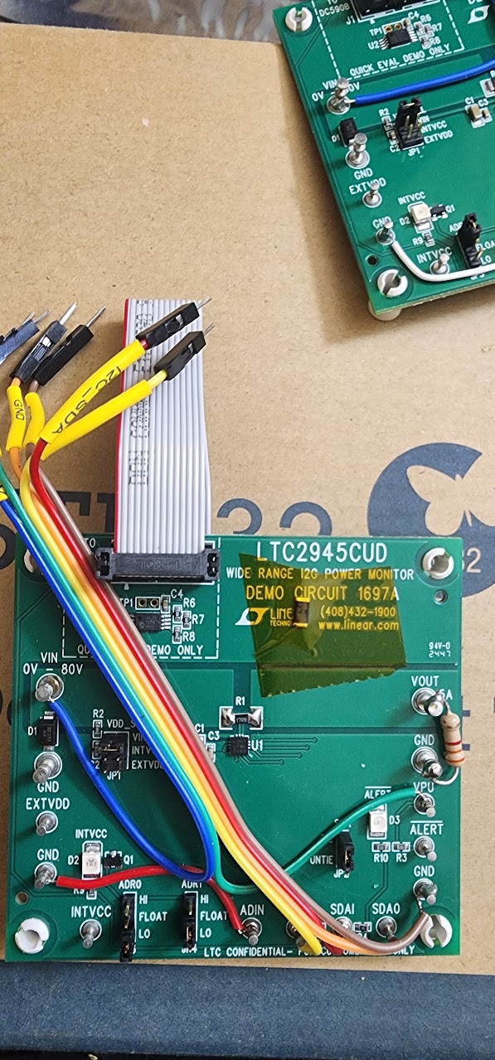
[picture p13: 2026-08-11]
documentation/Pictures/LTC2945_EVB_17Ohm_Shunt.jpg

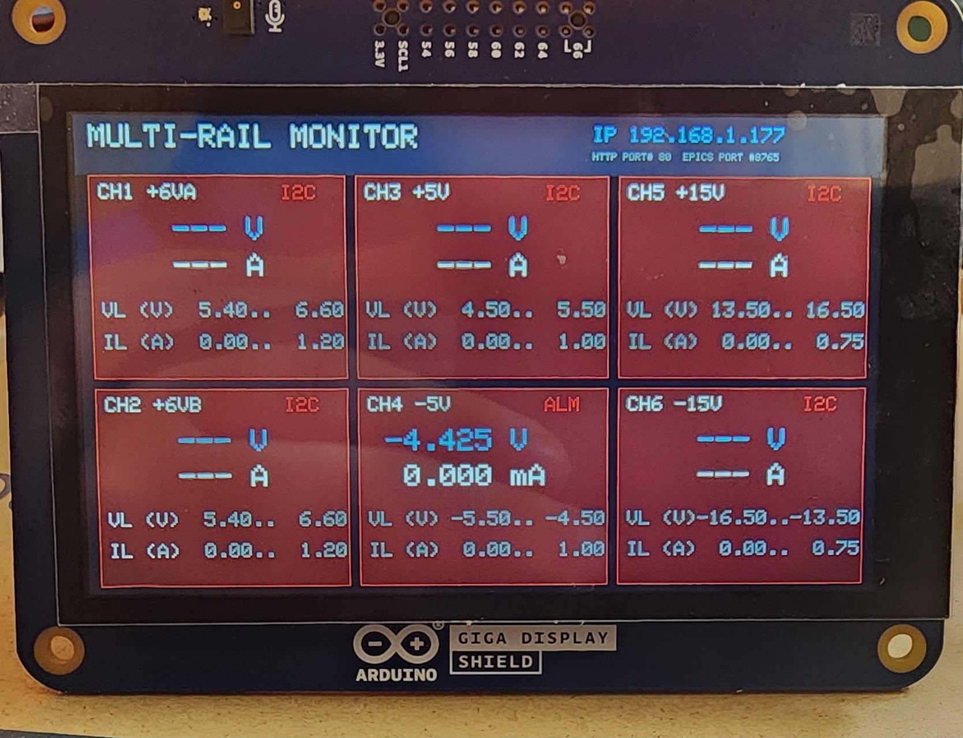
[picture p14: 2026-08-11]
documentation/Pictures/ExampleDisplay-Single_EVB_Connected_ALM.jpg

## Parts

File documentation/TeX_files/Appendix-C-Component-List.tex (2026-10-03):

% !TeX root = ../main.tex
\chapter{Updated Component List}
\label{app:component-list}
The Week 2 component list is intentionally presented in the three-column format
requested by the assignment. Quantities represent the present design quantity
for one complete monitoring-system hardware set and exclude optional/DNP parts
and purchasing spares. Detailed manufacturer and distributor information
remains in the KiCad bills of materials.

\begin{longtable}{>{\raggedleft\arraybackslash}p{0.10\textwidth}>{\raggedright\arraybackslash}p{0.70\textwidth}>{\raggedleft\arraybackslash}p{0.10\textwidth}}
\caption{Updated preliminary component list.}\label{tab:updated-components}\\
\toprule
\textbf{Item} & \textbf{Part Description} & \textbf{Qty.} \\
\midrule
\endfirsthead
\toprule
\textbf{Item} & \textbf{Part Description} & \textbf{Qty.} \\
\midrule
\endhead
\bottomrule
\endfoot
1 & Custom isolated multi-rail sensor PCB & 1 \\
2 & Custom Arduino GIGA interface/shield PCB & 1 \\
3 & Arduino GIGA R1 WiFi controller, ABX00063 & 1 \\
4 & Arduino GIGA Display Shield, ASX00039 & 1 \\
5 & LTC2945IUD-1 voltage/current monitor & 6 \\
6 & ACPL-064L dual-channel digital optocoupler & 12 \\
7 & TCA9803 I\textsuperscript{2}C bus buffer/repeater & 2 \\
8 & P82B715 I\textsuperscript{2}C bus extender & 2 \\
9 & TPS62912 low-noise 2 A buck regulator & 1 \\
10 & W6100-Q Ethernet controller & 1 \\
11 & SI-46014-F RJ45 Ethernet connector/magnetics assembly & 1 \\
12 & NTA7002NT1G N-channel MOSFET & 6 \\
13 & 39 m\(\Omega\), 1\% four-terminal current-sense resistor & 2 \\
14 & 50 m\(\Omega\), 1\% four-terminal current-sense resistor & 4 \\
15 & 2 k\(\Omega\) resistor & 18 \\
16 & 4.7 k\(\Omega\) resistor, populated positions only & 8 \\
17 & 14.7 k\(\Omega\) resistor & 1 \\
18 & 12.3 k\(\Omega\) resistor & 1 \\
19 & 10 k\(\Omega\) resistor & 5 \\
20 & 49.9 \(\Omega\) resistor & 4 \\
21 & 3.3 \(\Omega\) resistor & 4 \\
22 & 470 \(\Omega\) resistor & 2 \\
23 & 1 M\(\Omega\) resistor & 1 \\
24 & 0 \(\Omega\) jumper resistor / populated zero-ohm link & 4 \\
25 & 100 nF ceramic capacitor & 37 \\
26 & 1 \(\mu\)F ceramic capacitor & 12 \\
27 & 10 \(\mu\)F ceramic capacitor & 2 \\
28 & 22 \(\mu\)F ceramic capacitor & 5 \\
29 & 470 nF ceramic capacitor & 1 \\
30 & 22 nF ceramic capacitor & 1 \\
31 & 3.3 \(\mu\)F capacitor & 1 \\
32 & 1 nF capacitor & 1 \\
33 & 18 pF capacitor & 2 \\
34 & 2.2 \(\mu\)H power inductor & 1 \\
35 & 120 \(\Omega\) ferrite bead & 3 \\
36 & Sensor-board EMI/filter bead (BLE18PS080SN1D) & 1 \\
37 & 25 MHz crystal, FL2500169 & 1 \\
38 & Molex 0039299049 connector/header positions & 5 \\
39 & Molex 0039289088 connector/header & 2 \\
40 & Molex 0039289108 connector/header & 2 \\
41 & Arduino shield connector set & 1 \\
42 & Keystone 5000 test point & 3 \\
43 & Keystone 5001 test point & 2 \\
44 & Keystone 5015 test point & 9 \\
\end{longtable}

This list is expected to change slightly after first-article assembly and final
verification. In particular, optional pull-up resistors and other DNP footprints
may be populated temporarily for troubleshooting, and component values may be
adjusted if testing shows that additional margin or filtering is required.

\section{Bill of Materials}
\label{sec:bom}

The current bills of materials for the Sensor Board and Arduino Shield Board
are maintained with their respective KiCad hardware-design files in the
project \texttt{hardware} directory. They are included below for reference.

\begin{weekthreechange}
    The BOMs below were updated udring the DDR to add extended BOM costs for quantity ranges 1, 100, and 1000 boards.

    Price breaks were set for using the required quantity of components at production quantities, going to re-spooled or full reels, so some components may have the ~\$7 reeling fees added.
\end{weekthreechange}
\subsection{Sensor Board Bill of Materials}
    \subsubsection{Preliminary}
        \begin{center}
            \includegraphics[
            page=1,
            angle=90,
            width=\textwidth,
            height=0.9\textheight,
            keepaspectratio
            ]{
                ../hardware/Isolated Multi-Rail Power Supply Monitor Sensor Board/%
                Isolated Multi-Rail Power Supply Monitor Sensor Board BOM 8-22-2026 REV -.pdf
            }
        \end{center}

        \begin{landscape}
            \subsubsection{Final}
                \begin{center}
                    \scriptsize

                    \captionof{table}{Final Sensor Board Bill of Materials and Production Cost Analysis}
                    \label{tab:sensor-bom-cost}

                    \resizebox{0.96\linewidth}{!}{%
                        \begin{tabular}{
                                p{0.17\linewidth}
                                r
                                p{0.24\linewidth}
                                p{0.15\linewidth}
                                p{0.20\linewidth}
                                p{0.12\linewidth}
                                r
                                r
                                r
                            }
                            \toprule
                            \textbf{Reference} &
                            \textbf{Qty./System} &
                            \textbf{Specification} &
                            \textbf{Manufacturer} &
                            \textbf{Mfr. P/N} &
                            \textbf{Pricing Source} &
                            \textbf{1 System} &
                            \textbf{100 Systems} &
                            \textbf{1000 Systems} \\
                            \midrule

                            C1,\allowbreak C3,\allowbreak C21,\allowbreak C23,\allowbreak C26,\allowbreak C28,\allowbreak C31,\allowbreak C33,\allowbreak C36,\allowbreak C38,\allowbreak C41,\allowbreak C43
                            & 12
                            & 1 \textmu{}F $\pm$10\%, 50 V, X5R, 0603
                            & Samsung Electro-Mechanics
                            & CL10A105KB8NNNC
                            & DigiKey
                            & \$1.12
                            & \$54.73
                            & \$374.72 \\

                            C2,\allowbreak C4,\allowbreak C5,\allowbreak C11,\allowbreak C12,\allowbreak C14,\allowbreak C15,\allowbreak C17,\allowbreak C22,\allowbreak C24,\allowbreak C25,\allowbreak C27,\allowbreak C29,\allowbreak C30,\allowbreak C32,\allowbreak C34,\allowbreak C35,\allowbreak C37,\allowbreak C39,\allowbreak C40,\allowbreak C42,\allowbreak C44,\allowbreak C45
                            & 23
                            & 100 nF $\pm$10\%, 50 V, X5R, 0402
                            & Murata Electronics
                            & GRM155R61H104KE14D
                            & Mouser
                            & \$0.44
                            & \$34.83
                            & \$180.00 \\

                            C6
                            & 1
                            & 2.2 nF $\pm$10\%, 50 V, X7R, 0402
                            & Murata Electronics
                            & GRM155R71H222KA01D
                            & DigiKey
                            & \$0.22
                            & \$8.20
                            & \$15.25 \\

                            C7,\allowbreak C8
                            & 2
                            & 10 \textmu{}F $\pm$10\%, 25 V, X7S, 0805
                            & TDK
                            & C2012X7S1E106K125AC
                            & DigiKey
                            & \$1.77
                            & \$61.21
                            & \$446.16 \\

                            C9
                            & 1
                            & 470 nF $\pm$10\%, 25 V, X5R, 0402
                            & TDK
                            & C1005X5R1E474K050BB
                            & DigiKey
                            & \$0.20
                            & \$10.40
                            & \$28.95 \\

                            C10,\allowbreak C13,\allowbreak C16,\allowbreak C19,\allowbreak C20
                            & 5
                            & 22 \textmu{}F $\pm$20\%, 10 V, X7S, 0805
                            & Cal-Chip Electronics
                            & GMC21X7S226M10NT
                            & DigiKey
                            & \$4.52
                            & \$421.15
                            & \$4,148.50 \\

                            FB1
                            & 1
                            & Ferrite bead, 8.5 $\Omega$ @ 100 MHz, 8 A, 4 m$\Omega$ max DCR, 0603
                            & Murata Electronics
                            & BLE18PS080SN1D
                            & Mouser
                            & \$0.62
                            & \$23.50
                            & \$89.50 \\

                            J101,\allowbreak J102,\allowbreak J104,\allowbreak J105,\allowbreak J108
                            & 5
                            & 4-position Mini-Fit Jr. vertical header, 4.2 mm
                            & Molex
                            & 0039299049
                            & DigiKey
                            & \$15.78
                            & \$931.41
                            & \$7,941.18 \\

                            J103
                            & 1
                            & 8-position Mini-Fit Jr. vertical header, 4.2 mm
                            & Molex
                            & 0039289088
                            & DigiKey
                            & \$9.16
                            & \$364.00
                            & \$3,249.31 \\

                            J106,\allowbreak J107
                            & 2
                            & 10-position Mini-Fit Jr. vertical header, 4.2 mm
                            & Molex
                            & 0039289108
                            & DigiKey
                            & \$14.94
                            & \$790.75
                            & \$6,722.03 \\

                            L1
                            & 1
                            & 2.2 \textmu{}H $\pm$20\%, 4.7 A rated, 6.2 A Isat
                            & Würth Elektronik
                            & 74438356022
                            & DigiKey
                            & \$3.88
                            & \$190.92
                            & \$1,702.10 \\

                            Q1,\allowbreak Q2,\allowbreak Q3,\allowbreak Q4,\allowbreak Q5,\allowbreak Q6
                            & 6
                            & N-MOSFET, 30 V, 154 mA, 300 mW, SC-75
                            & onsemi
                            & NTA7002NT1G
                            & Mouser
                            & \$2.03
                            & \$60.46
                            & \$432.00 \\

                            R6,\allowbreak R12,\allowbreak R13,\allowbreak R33,\allowbreak R34,\allowbreak R35,\allowbreak R36,\allowbreak R37,\allowbreak R38,\allowbreak R39,\allowbreak R40,\allowbreak R41,\allowbreak R42,\allowbreak R43,\allowbreak R44,\allowbreak R45,\allowbreak R46,\allowbreak R47
                            & 18
                            & 2.00 k$\Omega$ $\pm$1\%, 0.10 W, 0402
                            & Panasonic Industry
                            & ERJ-2RKF2001X
                            & DigiKey
                            & \$0.62
                            & \$24.19
                            & \$103.80 \\

                            R7,\allowbreak R18
                            & 2
                            & 39 m$\Omega$ $\pm$1\%, 0.75 W, Kelvin 2010
                            & Ohmite
                            & LVK20R039FER
                            & DigiKey
                            & \$4.56
                            & \$176.40
                            & \$1,503.00 \\

                            R8,\allowbreak R11,\allowbreak R19,\allowbreak R20
                            & 4
                            & 50 m$\Omega$ $\pm$1\%, 0.75 W, Kelvin 2010
                            & Ohmite
                            & LVK20R050FER
                            & Newark
                            & \$9.85
                            & \$376.64
                            & \$2,140.00 \\

                            R9,\allowbreak R10
                            & 2
                            & 0 $\Omega$ jumper, 1206
                            & Keystone Electronics
                            & 5108
                            & DigiKey
                            & \$0.81
                            & \$51.00
                            & \$447.00 \\

                            R21
                            & 1
                            & 0 $\Omega$ jumper, 1/16 W, 0402
                            & Vishay Dale
                            & CRCW04020000Z0ED
                            & DigiKey
                            & \$0.20
                            & \$8.09
                            & \$14.18 \\

                            R23,\allowbreak R24
                            & 2
                            & 4.70 k$\Omega$ $\pm$1\%, 1/16 W, 0402
                            & Vishay Dale
                            & CRCW04024K70FKED
                            & DigiKey
                            & \$0.30
                            & \$10.45
                            & \$26.40 \\

                            R25
                            & 1
                            & 14.7 k$\Omega$ $\pm$0.1\%, 1/16 W, 0402
                            & Panasonic Industry
                            & ERA-2APB1472X
                            & DigiKey
                            & \$0.96
                            & \$43.31
                            & \$312.74 \\

                            R26
                            & 1
                            & 4.70 k$\Omega$ $\pm$0.1\%, 1/16 W, 0402
                            & Panasonic Industry
                            & ERA-2ARB472X
                            & DigiKey
                            & \$1.20
                            & \$52.45
                            & \$409.25 \\

                            TP1,\allowbreak TP3
                            & 2
                            & Red through-hole test point
                            & Keystone Electronics
                            & 5000
                            & DigiKey
                            & \$0.81
                            & \$41.80
                            & \$418.00 \\

                            TP2
                            & 1
                            & Black through-hole test point
                            & Keystone Electronics
                            & 5001
                            & DigiKey
                            & \$0.54
                            & \$20.90
                            & \$209.00 \\

                            TP4,\allowbreak TP5,\allowbreak TP6,\allowbreak TP7,\allowbreak TP8,\allowbreak TP9
                            & 6
                            & SMT miniature test point
                            & Keystone Electronics
                            & 5015
                            & DigiKey
                            & \$3.43
                            & \$160.94
                            & \$1,335.67 \\

                            U1,\allowbreak U8,\allowbreak U11,\allowbreak U14,\allowbreak U17,\allowbreak U20
                            & 6
                            & Power/current monitor, 4--80 V input, 12-QFN
                            & Analog Devices
                            & LTC2945IUD\#TRPBF
                            & DigiKey
                            & \$98.56
                            & \$6,287.96
                            & \$62,816.56 \\

                            U2,\allowbreak U3,\allowbreak U9,\allowbreak U10,\allowbreak U12,\allowbreak U13,\allowbreak U15,\allowbreak U16,\allowbreak U18,\allowbreak U19,\allowbreak U21,\allowbreak U22
                            & 12
                            & Dual digital optoisolator, 3.75 kVrms, 10 MBd, 8-SO
                            & Broadcom
                            & ACPL-064L-500E
                            & DigiKey
                            & \$52.51
                            & \$3,506.85
                            & \$34,532.19 \\

                            U4
                            & 1
                            & 2 A adjustable synchronous buck, 3--17 V input
                            & Texas Instruments
                            & TPS62912RPUR
                            & DigiKey
                            & \$5.06
                            & \$176.32
                            & \$1,565.46 \\

                            U5,\allowbreak U6
                            & 2
                            & Dual-channel I\textsuperscript{2}C level translator/buffer, 8-VSSOP
                            & Texas Instruments
                            & TCA9803DGKR
                            & DigiKey
                            & \$2.85
                            & \$126.53
                            & \$1,077.39 \\

                            U7
                            & 1
                            & I\textsuperscript{2}C bus buffer/re-driver, 4.5--12 V, 8-SOIC
                            & Texas Instruments
                            & P82B715DR
                            & DigiKey
                            & \$5.42
                            & \$188.32
                            & \$1,582.29 \\

                            \midrule

                            \multicolumn{6}{r}{\textbf{Component subtotal}}
                            & \textbf{\$242.36}
                            & \textbf{\$14,203.71}
                            & \textbf{\$133,822.63} \\

                            PCB
                            & 1
                            & Custom fabricated bare Sensor Board PCB; 5-board MOQ for prototype quantity
                            & ---
                            & Custom
                            &
                            & \$473.57
                            & \$1,288.53
                            & \$6,825.82 \\

                            \midrule

                            \multicolumn{6}{r}{\textbf{Sensor Board total including PCB}}
                            & \textbf{\$715.93}
                            & \textbf{\$15,492.24}
                            & \textbf{\$140,648.45} \\

                            \bottomrule
                        \end{tabular}%
                    }

                    \vspace{0.6em}

                    \begin{minipage}{0.94\linewidth}
                        \footnotesize
                        \textit{Pricing note:}
                        Costs are extended purchase costs for each production scale.
                        A 10\% spare allowance is included for non-module components;
                        Arduino modules are purchased at exact system quantity.
                        For 100- and 1000-system production, custom reels/re-reels and
                        full manufacturer reels were compared lower line purchase cost was used.
                        Bare PCB fabrication is included from the provided quote.
                        Shipping, tax, tariffs, PCB assembly, enclosure, cables, and other
                        non-PCB system hardware are excluded.
                    \end{minipage}

                \end{center}
            \end{landscape}

    \subsection{Arduino Shield Board Bill of Materials}
        \subsubsection{Preliminary}
            \begin{center}
                \includegraphics[
                page=1,
                angle=90,
                width=\textwidth,
                height=0.95\textheight,
                keepaspectratio
                ]{
                    ../hardware/Isolated Multi-Rail Power Supply Monitor Arduino Shield Board/%
                    Isolated Multi-Rail Power Supply Monitor Arduino Shield Board BOM 8-22-2026 REV -.pdf
                }
            \end{center}

            \begin{landscape}
                \subsubsection{Final}
                    \begin{center}
                        \scriptsize

                        \captionof{table}{Final Arduino Shield Board Bill of Materials and Production Cost Analysis}
                        \label{tab:shield-bom-cost}

                        \resizebox{0.96\linewidth}{!}{%
                            \begin{tabular}{
                                    p{0.17\linewidth}
                                    r
                                    p{0.24\linewidth}
                                    p{0.15\linewidth}
                                    p{0.20\linewidth}
                                    p{0.12\linewidth}
                                    r
                                    r
                                    r
                                }
                                \toprule
                                \textbf{Reference} &
                                \textbf{Qty./System} &
                                \textbf{Specification} &
                                \textbf{Manufacturer} &
                                \textbf{Mfr. P/N} &
                                \textbf{Pricing Source} &
                                \textbf{1 System} &
                                \textbf{100 Systems} &
                                \textbf{1000 Systems} \\
                                \midrule

                                A201
                                & 1
                                & Arduino GIGA R1 WiFi module
                                & Arduino
                                & ABX00063
                                & DigiKey
                                & \$69.60
                                & \$6,229.02
                                & \$62,290.20 \\

                                C17,\allowbreak C201,\allowbreak C202,\allowbreak C203,\allowbreak
                                C211,\allowbreak C215,\allowbreak C216,\allowbreak C217,\allowbreak
                                C220,\allowbreak C221,\allowbreak C223,\allowbreak C224,\allowbreak
                                C225,\allowbreak C227
                                & 14
                                & 100 nF $\pm$10\%, 50 V, X5R, 0402
                                & Murata Electronics
                                & GRM155R61H104KE14D
                                & Mouser
                                & \$0.27
                                & \$25.48
                                & \$120.00 \\

                                C218
                                & 1
                                & 3.3 \textmu{}F $\pm$10\%, 25 V, X5R, 0603
                                & Cal-Chip Electronics, Inc.
                                & GMC10X5R335K25NT
                                & DigiKey
                                & \$0.92
                                & \$26.95
                                & \$166.17 \\

                                C219
                                & 1
                                & 1 nF $\pm$10\%, 2 kV, X7R, 1206
                                & KYOCERA AVX
                                & 1206GC102KAT1A
                                & DigiKey
                                & \$0.60
                                & \$19.19
                                & \$101.12 \\

                                C222,\allowbreak C226
                                & 2
                                & 18 pF $\pm$5\%, 50 V, C0G/NP0, 0402
                                & Murata Electronics
                                & GRM1555C1H180JA01D
                                & DigiKey
                                & \$0.30
                                & \$10.21
                                & \$29.53 \\

                                FB201,\allowbreak FB202,\allowbreak FB203
                                & 3
                                & Ferrite bead, 120 $\Omega$ @ 100 MHz, 3 A, 0603
                                & Pulse Electronics
                                & BBUP00160805121Y00
                                & DigiKey
                                & \$0.52
                                & \$24.98
                                & \$147.91 \\

                                J201
                                & 1
                                & RJ45 MagJack, 10/100Base-T, through-hole
                                & Bel Fuse
                                & SI-46014-F
                                & DigiKey
                                & \$11.62
                                & \$469.26
                                & \$4,251.93 \\

                                J309
                                & 1
                                & 8-position Mini-Fit Jr. vertical header, 4.2 mm
                                & Molex
                                & 0039289088
                                & DigiKey
                                & \$9.16
                                & \$364.00
                                & \$3,249.31 \\

                                N101
                                & 1
                                & Arduino GIGA Display Shield module
                                & Arduino
                                & ASX00039
                                & DigiKey
                                & \$63.60
                                & \$5,692.01
                                & \$56,920.10 \\

                                N201
                                & 1
                                & Arduino stacking header set
                                & Adafruit Industries
                                & 85
                                & DigiKey
                                & \$3.90
                                & \$214.50
                                & \$2,145.00 \\

                                R23,\allowbreak R24,\allowbreak R205,\allowbreak R206,\allowbreak R207
                                & 5
                                & 4.70 k$\Omega$ $\pm$1\%, 1/16 W, 0402
                                & Vishay Dale
                                & CRCW04024K70FKED
                                & DigiKey
                                & \$0.60
                                & \$12.69
                                & \$42.31 \\

                                R101,\allowbreak R102,\allowbreak R103,\allowbreak R104,\allowbreak R105
                                & 5
                                & 10 k$\Omega$ $\pm$1\%, 0.10 W, 50 V, 0402
                                & Panasonic Industry
                                & ERJ-2RKF1002X
                                & DigiKey / Newark
                                & \$0.31
                                & \$16.90
                                & \$41.71 \\

                                R208
                                & 1
                                & 12.3 k$\Omega$ $\pm$0.1\%, 1/16 W, 0402
                                & KOA Speer
                                & RN73R1ETTP1232B25
                                & DigiKey
                                & \$0.20
                                & \$13.28
                                & \$59.25 \\

                                R209,\allowbreak R210,\allowbreak R215,\allowbreak R216
                                & 4
                                & 49.9 $\Omega$ $\pm$1\%, 1/16 W, 0402
                                & Vishay Dale
                                & CRCW040249R9FKED
                                & DigiKey
                                & \$0.50
                                & \$12.40
                                & \$45.81 \\

                                R211,\allowbreak R212,\allowbreak R213,\allowbreak R214
                                & 4
                                & 3.30 $\Omega$ $\pm$1\%, 1/16 W, 0402
                                & Vishay Dale
                                & CRCW04023R30FKED
                                & DigiKey
                                & \$0.50
                                & \$14.08
                                & \$58.96 \\

                                R217
                                & 1
                                & 1.00 M$\Omega$ $\pm$1\%, 1/16 W, 0402
                                & Vishay Dale
                                & CRCW04021M00FKED
                                & DigiKey
                                & \$0.20
                                & \$8.73
                                & \$16.70 \\

                                R218,\allowbreak R219
                                & 2
                                & 470 $\Omega$ $\pm$1\%, 0.10 W, 0402
                                & Panasonic Industry
                                & ERJ-2RKF4700X
                                & DigiKey
                                & \$0.30
                                & \$10.41
                                & \$26.10 \\

                                R220
                                & 1
                                & 0 $\Omega$ jumper, 1/16 W, 0402
                                & Vishay Dale
                                & CRCW04020000Z0ED
                                & DigiKey
                                & \$0.20
                                & \$8.09
                                & \$14.18 \\
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

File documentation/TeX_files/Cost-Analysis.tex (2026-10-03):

% !TeX root = ../main.tex
\chapter{Cost Analysis, Design for Manufacturing, and Sustainability}
\label{chap:cost-dfm-sustainability}

\begin{weekthreechange}
    \section{Cost Analysis}
    The finalized bill of materials was used to evaluate the expected hardware cost
    of the isolated multi-rail power supply monitor at both the prototype and proposed production quantities. Component pricing was obtained from distributors, including DigiKey, Mouser, Newark, Master Electronics, and Allied Electronics. For the 100- and 1000-system production cases, cut-tape pricing, re-reel services, and full manufacturer reels were compared where applicable, and the lowest practical purchase cost was used. A 10\% spare allowance was included for non-module components, while the Arduino GIGA R1 WiFi and GIGA Display modules were purchased at the exact required system quantity.

    The component quantities per-board were summed, and then multiplied by the number of assemblies to produce to get the quantities and costs listed in the BOM.

    Bare PCB fabrication was also included in the analysis. The Sensor Board was quoted at \$473.57 for the 5-board minimum order, \$1,288.53 for 100 boards, and \$6,825.82 for 1000 boards. The Arduino Shield Board was quoted at \$122.19 for the 5-board minimum order, \$250.77 for 100 boards, and \$1,402.23 for 1000 boards. For the single-system case, the full minimum-order cost is included even though only one PCB of each type is required.

    \begin{table}[H]
        \centering
        \caption{Estimated Hardware Cost Versus Production Quantity}
        \label{tab:system-production-cost}
        \resizebox{\textwidth}{!}{%
            \begin{tabular}{rrrrrrr}
                \toprule
                \textbf{Production Qty.} &
                \textbf{Sensor Components} &
                \textbf{Sensor PCB} &
                \textbf{Shield Components} &
                \textbf{Shield PCB} &
                \textbf{Total Purchase Cost} &
                \textbf{Cost/System} \\
                \midrule
                1
                & \$242.36
                & \$473.57
                & \$180.90
                & \$122.19
                & \$1,019.03
                & \$1,019.03 \\
                100
                & \$14,203.71
                & \$1,288.53
                & \$13,838.70
                & \$250.77
                & \$29,581.71
                & \$295.82 \\

                1,000
                & \$133,822.63
                & \$6,825.82
                & \$135,338.93
                & \$1,402.23
                & \$277,389.61
                & \$277.39 \\
                \bottomrule
            \end{tabular}%
        }
    \end{table}

    The cost analysis shows a substantial reduction in per-system cost when produced in volume. The prototype case is below some minimum order quantities, pushing the estimated hardware purchase cost to \$1,326.11 for one complete system. At a production quantity of 100 systems, the estimated cost decreases to \$298.56 per system. At 1000 systems, additional component and PCB quantity discounts reduce the
    estimated cost to \$277.53 per system.

    \section{Design for Manufacturing}

    DFM, or Design for manufacturing was considered during final component and PCB selection. The six measurement channels use a repeated circuit architecture, which reduces the number of unique circuit blocks that must be fabricated, inspected, and tested. Reuse of common component values and package sizes also reduces the number of unique feeder setups and component reels required during assembly. Standard surface-mount packages and conventional PCB fabrication processes were favored so that the design can be manufactured without specialized assembly processes.

    Surface mount components were selected for personal preference and ease of hand-assembly and wider component availability along with much smaller component footprints when compared to through hole devices. Connectors used were through hole so a selective solder process, hand-installation process, or wave soldering process will still be required for autoamted assembly.

    The production cost analysis also influenced component packaging decisions. At higher quantities, distributor re-reel services and full manufacturer reels were evaluated against cut-tape pricing to reduce component cost while still providing packaging compatible with automated assembly. The PCB designs use standard fabrication methods and do not depend on unusual substrates/dielectrics, materials or proprietary manufacturing processes, allowing production to be sourced from
    any number of run-of-the-mill PCB and assembly vendors.

    \section{Design for Assembly}

    Design for assembly was addressed by minimizing the number of unique components, using repeated measurement-channel circuitry, and using connectors and modules that simplify final system integration. The Arduino GIGA R1 WiFi and GIGA Display are COTS (commercial off the shelf) pluggable modules rather than being reproduced as custom boards, reducing assembly complexity and allowing independent replacement of those modules if necessary.

    Test points are included at important nodes to support board-level     inspection, troubleshooting, and functional test after assembly. The repeated channel architecture also allows a common test procedure to be applied to each measurement channel rather than requiring a different assembly and test process for every monitored rail. These choices reduce assembly complexity and improve serviceability during both prototype development and future production.

    \section{Sustainability and Serviceability}
    Sustainability was considered primarily through serviceability, component reuse, and reduction of unnecessary replacement. The system is divided into separate parts - a Sensor Board, Arduino Shield, controller, and display assemblies, allowing a failed subsystem to be replaced or repaired without discarding the complete monitoring system. The use of commercially available components and standard packages also improves the likelihood that equivalent or replacement parts can be sourced during the service life of the design.

    Configuration values, alarm limits, and network settings are implemented in
    software rather than requiring hardware modifications for routine changes. This allows the system to be modified for changing operating requirements without replacing components or boards. The use of repeated channel circuitry and a limited set of common component values also reduces the number of spare part types that must be stocked. At production quantities, purchasing components in appropriate reel quantities further reduces packaging and handling associated with many small individual orders.

    \textit{Cost scope note:} The values in Table~\ref{tab:system-production-cost}
    include electronic components and bare PCB fabrication. They do not include PCB
    assembly labor or assembly service, shipping, sales tax, tariffs, enclosure
    hardware, cabling, or other system-level mechanical components.

    \section{Procurements}
    All components needed have been procured from vendors, including Digikey, Mouser, Master Electronics, Texas Instruments webstore, JLCPCB, and PCBWay.

    Assembly of the boards is slated to begin the week of October 5, 2026.
\end{weekthreechange}

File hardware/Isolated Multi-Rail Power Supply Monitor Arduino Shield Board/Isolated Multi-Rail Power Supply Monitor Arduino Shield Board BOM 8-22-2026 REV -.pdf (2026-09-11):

BOM: Arduino Shield Board | Production Quantity: | 1 Tape and Reel/Reeling Fees Allowable? No | Add 10% spares for components excluding modules
Reference | Value | DNP | MPN | Manufacturer | DPN | Distributor | Qty | Qty+10% | Order Qty | Extended Price
A201 | Arduino_Giga_R1_WiFi | ABX00063 | Arduino | 1050-ABX00063-ND | Digikey | 1 | 2 | 1 | $69.60
C6 | 22n | DNP | GRM155R71H222KA01D Murata Electronics | 490-1305-6-ND | Digikey | 1 | 2 | 0
C7,C8 | 10u | DNP | C2012X7S1E106K125AC TDK | 445-181600-6-ND | Digikey | 2 | 3 | 0
C9 | 470n | DNP | C1005X5R1E474K050BB | 445-8020-6-ND | Digikey | 1 | 2 | 0
C10,C13,C16,C19,C20 | 22u | DNP | GMC21X7S226M10NT | Cal-Chip Electronics, Inc. | 4713-GMC21X7S226M10NTDKR-ND | Digikey | 5 | 6 | 0
C17,C201,C202,C203,C211,
C215,C216,C217,C220,C221
,C223,C224,C225,C227 | 100n | GRM155R61H104KE14D Murata Electronics | 490-10697-6-ND | Digikey | 14 | 16 | 100 | $1.41
C218 | 3u3 | Digikey | 1 | 2
C219 | 1n | 1206GC102KAT1A | KYOCERA AVX | 478-2956-6-ND | Digikey | 1 | 2 | 10 | $1.43
C222,C226 | 18p | GRM1555C1H180JA01D Murata Electronics | 490-5858-6-ND | Digikey | 2 | 3 | 100 | $1.43
FB1 | 10n | DNP | BLE18PS080SN1D | Murata Electronics | 490-BLE18PS080SN1DDKR-ND | Digikey | 1 | 2
FB201,FB202,FB203 | 120R | BBUP00160805121Y00 | Pulse Electronics | 553-BBUP00160805121Y00CT-ND | Digikey | 3 | 4 | 25 | $1.97
J201 | SI-46014-F | SI-46014-F | Bel Fuse Inc. | 5923-SI-46014-F-ND | Digikey | 1 | 2 | 1 | $5.81
J309 | 0039289088 | 0039289088 | Molex | WM3835-ND | Digikey | 1 | 2 | 1 | $4.58
L1 | 2u2 | DNP | 74438356022 Wurth Elektronik | 732-8232-6-ND | Digikey | 1 | 2 | 3 | $5.82
N101 | Giga_Display | ASX00039 | Arduino | 1050-ASX00039-ND | Digikey | 1 | 2 | 1 | $63.60
N201 | Connector_Set | 85 Adafruit Industries | 1528-1074-ND | Digikey | 1 | 2 | 2 | $3.90
R21 | 0R | DNP | ERJ-2RKF4701X | Panasonic Industry | P4.70KLDKR-ND | Digikey | 1 | 2
R23,R24,R205,R206,R207 | 4k7 | CRCW04024K70FKED | Vishay Dale | 541-4.70KLCT-ND | Digikey | 5 | 6 | 100 | $1.57
R25 | 15k2 | DNP | ERJ-2RKF4701X | Panasonic Industry | P4.70KLDKR-ND | Digikey | 1 | 2
R26 | 4k87 | DNP | ERJ-2RKF4701X | Panasonic Industry | P4.70KLDKR-ND | Digikey | 1 | 2
R31,R32 | 4k7 | DNP | ERJ-2RKF4701X | Panasonic Industry | P4.70KLDKR-ND | Digikey | 2 | 3
R101,R102,R103,R104,R105 10k | Digikey | 5 | 6
R208 | 12k3 | RN73R1ETTP1232B25 | KOA Speer Electronics, Inc. | 2019-RN73R1ETTP1232B25DKR-ND | Digikey | 1 | 2 | 50 | $3.02
R209,R210,R215,R216 | 49R9 | CRCW040249R9FKED | Vishay Dale | 541-49.9LDKR-ND | Digikey | 4 | 5 | 100 | $1.57
R211,R212,R213,R214 | 3R3 | CRCW04023R30FKED | Vishay Dale | 541-3.30LLDKR-ND | Digikey | 4 | 5 | 100 | $2.03
R217 | 1M | CRCW04021M00FKED | Vishay Dale | 541-1.00MLDKR-ND | Digikey | 1 | 2 | 100 | $1.57
R218,R219 | 470R | ERJ-2RKF4700X | Panasonic Industry | P470LDKR-ND | Digikey | 2 | 3 | 100 | $1.64
R220 | 0R | CRCW04020000Z0ED | Vishay Dale | 541-0.0JDKR-ND | Digikey | 1 | 2 | 100 | $0.99
TP1,TP3 | 2 DNP | 5000 Keystone | 36-5000-ND | Digikey | 2 | 3
TP2 | 1 DNP | 5001 Keystone | 36-5001-ND | Digikey | 1 | 2
TP101 | 1 | 5000 Keystone | 36-5000-ND | Digikey | 1 | 2 | 10 | $2.04
TP102 | 1 | 5001 Keystone | 36-5001-ND | Digikey | 1 | 2 | 10 | $2.03
TP201,TP202,TP203 | 3 | 5015 Keystone | 36-5015CT-ND | Digikey | 3 | 4 | 10 | $3.70
U4 | TPS62912 | DNP | 1 | 2
U7 | P82715DR | P82B715DR | 296-24729-6-ND | 1 | 2 | 2 | $5.42
U202 | W6100-Q | W6100Q | WIZnet | 950-W6100Q | WIZnet | 1 | 2 | 2 | $5.04
Y201 | 25MHz | FL2500169 | Diodes Incorporated | 31-FL2500169DKR-ND | Digikey | 1 | 2 | 2 | $1.38
| | | | | | | | | TOTAL COST: | $191.55

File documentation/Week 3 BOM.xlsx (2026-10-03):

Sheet: Sensor BOM & Cost
Sensor Board BOM and Production Cost Analysis
 |  |  | Non-module spare allowance | 10%
Final Component Specification |  |  |  |  |  |  |  | 1-System Purchase |  |  |  |  |  | 100-System Purchase |  |  |  |  |  | 1000-System Purchase
Reference | Qty/System | Specification | Manufacturer | MPN | Pricing Supplier | Price Source | Module? | Required Qty | Order Qty | Unit Price | Reel Fee | Packaging | Extended Cost | Required Qty | Order Qty | Unit Price | Reel Fee | Packaging | Extended Cost | Required Qty | Order Qty | Unit Price | Reel Fee | Packaging | Extended Cost
C1,C3,C21,C23,C26,C28,C31,C33,C36,C38,C41,C43 | 12 | 1 µF ±10%, 50 V, X5R, 0603 | Samsung Electro-Mechanics | CL10A105KB8NNNC | DigiKey | https://www.digikey.com/en/products/detail/samsung-electro-mechanics/CL10A105KB8NNNC/3887518 | No | 14 | 14 | $0.08000 | $0.00 | Cut tape/bulk/tray | $1.12 | 1320 | 1320 | $0.03616 | $7.00 | Digi-Reel | $54.73 | 13200 | 16000 | $0.02342 | $0.00 | Full reel (4000/reel) | $374.72
C2,C4,C5,C11,C12,C14,C15,C17,C22,C24,C25,C27,C29,C30,C32,C34,C35,C37,C39,C40,C42,C44,C45 | 23 | 100 nF ±10%, 50 V, X5R, 0402 | Murata Electronics | GRM155R61H104KE14D | Mouser | https://www.mouser.com/en/ProductDetail/Murata-Electronics/GRM155R61H104KE14D | No | 26 | 26 | $0.01700 | $0.00 | Cut tape/bulk/tray | $0.44 | 2530 | 2530 | $0.01100 | $7.00 | MouseReel | $34.83 | 25300 | 30000 | $0.00600 | $0.00 | Full reel (10000/reel) | $180.00
C6 | 1 | 2.2 nF ±10%, 50 V, X7R, 0402 | Murata Electronics | GRM155R71H222KA01D | DigiKey | https://www.digikey.com/en/products/detail/murata-electronics/GRM155R71H222KA01D/587234 | No | 2 | 2 | $0.11000 | $0.00 | Cut tape/bulk/tray | $0.22 | 110 | 110 | $0.01090 | $7.00 | Digi-Reel | $8.20 | 1100 | 1100 | $0.00750 | $7.00 | Digi-Reel | $15.25
C7,C8 | 2 | 10 µF ±10%, 25 V, X7S, 0805 | TDK | C2012X7S1E106K125AC | DigiKey | https://www.digikey.com/en/products/detail/tdk/C2012X7S1E106K125AC/9991385 | No | 3 | 3 | $0.59000 | $0.00 | Cut tape/bulk/tray | $1.77 | 220 | 220 | $0.24640 | $7.00 | Digi-Reel | $61.21 | 2200 | 2200 | $0.19962 | $7.00 | Digi-Reel | $446.16
C9 | 1 | 470 nF ±10%, 25 V, X5R, 0402 | TDK | C1005X5R1E474K050BB | DigiKey | https://www.digikey.com/en/products/detail/tdk/C1005X5R1E474K050BB/2792144 | No | 2 | 2 | $0.10000 | $0.00 | Cut tape/bulk/tray | $0.20 | 110 | 110 | $0.03090 | $7.00 | Digi-Reel | $10.40 | 1100 | 1100 | $0.01995 | $7.00 | Digi-Reel | $28.95
C10,C13,C16,C19,C20 | 5 | 22 µF ±20%, 10 V, X7S, 0805 | Cal-Chip Electronics | GMC21X7S226M10NT | DigiKey | (existing uploaded DigiKey BOM quote) | No | 6 | 6 | $0.75300 | $0.00 | Cut tape/bulk/tray | $4.52 | 550 | 550 | $0.75300 | $7.00 | Digi-Reel | $421.15 | 5500 | 5500 | $0.75300 | $7.00 | Digi-Reel | $4148.50
FB1 | 1 | Ferrite bead, 8.5 Ω @ 100 MHz, 8 A, 4 mΩ max DCR, 0603 | Murata Electronics | BLE18PS080SN1D | Mouser | https://www.mouser.com/en/ProductDetail/Murata-Electronics/BLE18PS080SN1D | No | 2 | 2 | $0.31000 | $0.00 | Cut tape/bulk/tray | $0.62 | 110 | 110 | $0.15000 | $7.00 | MouseReel | $23.50 | 1100 | 1100 | $0.07500 | $7.00 | MouseReel | $89.50
J101,J102,J104,J105,J108 | 5 | 4-position Mini-Fit Jr. vertical header, 4.2 mm | Molex | 0039299049 | DigiKey | https://www.digikey.com/en/products/detail/molex/0039299049/3160172 | No | 6 | 6 | $2.63000 | $0.00 | Cut tape/bulk/tray | $15.78 | 550 | 550 | $1.69348 | $0.00 | Bulk/tray/exact qty | $931.41 | 5500 | 5500 | $1.44385 | $0.00 | Bulk/tray/exact qty | $7941.18
J103 | 1 | 8-position Mini-Fit Jr. vertical header, 4.2 mm | Molex | 0039289088 | DigiKey | https://www.digikey.com/en/products/detail/molex/0039289088/1633809 | No | 2 | 2 | $4.58000 | $0.00 | Cut tape/bulk/tray | $9.16 | 110 | 110 | $3.30910 | $0.00 | Bulk/tray/exact qty | $364.00 | 1100 | 1100 | $2.95392 | $0.00 | Bulk/tray/exact qty | $3249.31
J106,J107 | 2 | 10-position Mini-Fit Jr. vertical header, 4.2 mm | Molex | 0039289108 | DigiKey | https://www.digikey.com/en/products/detail/molex/0039289108/1633810 | No | 3 | 3 | $4.98000 | $0.00 | Cut tape/bulk/tray | $14.94 | 220 | 220 | $3.59430 | $0.00 | Bulk/tray/exact qty | $790.75 | 2200 | 2200 | $3.05547 | $0.00 | Bulk/tray/exact qty | $6722.03
L1 | 1 | 2.2 µH ±20%, 4.7 A rated, 6.2 A Isat | Würth Elektronik | 74438356022 | DigiKey | https://www.digikey.com/en/products/detail/w%C3%BCrth-elektronik/74438356022/5725347 | No | 2 | 2 | $1.94000 | $0.00 | Cut tape/bulk/tray | $3.88 | 110 | 110 | $1.67200 | $7.00 | Digi-Reel | $190.92 | 1100 | 1100 | $1.54100 | $7.00 | Digi-Reel | $1702.10
Q1,Q2,Q3,Q4,Q5,Q6 | 6 | N-MOSFET, 30 V, 154 mA, 300 mW, SC-75 | onsemi | NTA7002NT1G | Mouser | https://www.mouser.com/en/ProductDetail/onsemi/NTA7002NT1G | No | 7 | 7 | $0.29000 | $0.00 | Cut tape/bulk/tray | $2.03 | 660 | 660 | $0.08100 | $7.00 | MouseReel | $60.46 | 6600 | 9000 | $0.04800 | $0.00 | Full reel (3000/reel) | $432.00
R6,R12,R13,R33,R34,R35,R36,R37,R38,R39,R40,R41,R42,R43,R44,R45,R46,R47 | 18 | 2.00 kΩ ±1%, 0.10 W, 0402 | Panasonic Industry | ERJ-2RKF2001X | DigiKey | https://www.digikey.com/en/products/detail/panasonic-electronic-components/ERJ-2RKF2001X/192194 | No | 20 | 20 | $0.03100 | $0.00 | Cut tape/bulk/tray | $0.62 | 1980 | 1980 | $0.00868 | $7.00 | Digi-Reel | $24.19 | 19800 | 20000 | $0.00519 | $0.00 | Full reel (10000/reel) | $103.80
R7,R18 | 2 | 39 mΩ ±1%, 0.75 W, Kelvin 2010 | Ohmite | LVK20R039FER | DigiKey | https://www.masterelectronics.com/en/productdetail/ohmite/lvk20r039fer-12028965.html | No | 3 | 3 | $1.52000 | $0.00 | DigiKey cut tape | $4.56 | 220 | 220 | $0.77000 | $7.00 | Digi-Reel | $176.40 | 2200 | 2200 | $0.68000 | $7.00 | Digi-Reel | $1503.00
R8,R11,R19,R20 | 4 | 50 mΩ ±1%, 0.75 W, Kelvin 2010 | Ohmite | LVK20R050FER | Newark | https://www.newark.com/c/passive-components/resistors-fixed-value/prl/results?brand=ohmite&resistance=0.05ohm | No | 5 | 5 | $1.97000 | $0.00 | Cut tape / bulk | $9.85 | 440 | 440 | $0.85600 | $0.00 | Newark free Re-Reel | $376.64 | 4400 | 5000 | $0.42800 | $0.00 | Full reel (1000/reel) | $2140.00
R9,R10 | 2 | 0 Ω jumper, 1206 | Keystone Electronics | 5108 | DigiKey | https://www.digikey.com/en/products/detail/keystone-electronics/5108/5118869 | No | 3 | 3 | $0.27000 | $0.00 | Cut tape/bulk/tray | $0.81 | 220 | 220 | $0.20000 | $7.00 | Digi-Reel | $51.00 | 2200 | 2200 | $0.20000 | $7.00 | Digi-Reel | $447.00
R21 | 1 | 0 Ω jumper, 1/16 W, 0402 | Vishay Dale | CRCW04020000Z0ED | DigiKey | https://www.digikey.com/en/products/detail/vishay-dale/CRCW04020000Z0ED/1182611 | No | 2 | 2 | $0.10000 | $0.00 | Cut tape/bulk/tray | $0.20 | 110 | 110 | $0.00990 | $7.00 | Digi-Reel | $8.09 | 1100 | 1100 | $0.00653 | $7.00 | Digi-Reel | $14.18
R23,R24 | 2 | 4.70 kΩ ±1%, 1/16 W, 0402 | Vishay Dale | CRCW04024K70FKED | DigiKey | https://www.digikey.com/en/products/detail/vishay-dale/CRCW04024K70FKED/1178083 | No | 3 | 3 | $0.10000 | $0.00 | Cut tape/bulk/tray | $0.30 | 220 | 220 | $0.01570 | $7.00 | Digi-Reel | $10.45 | 2200 | 2200 | $0.00882 | $7.00 | Digi-Reel | $26.40
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

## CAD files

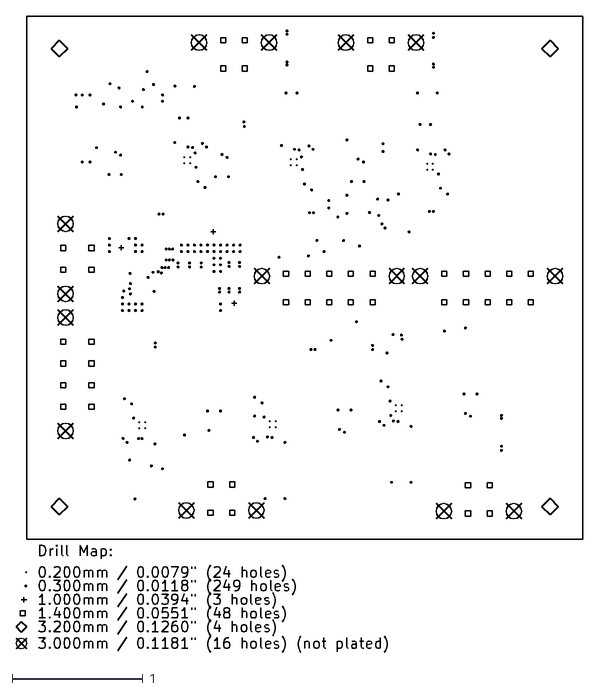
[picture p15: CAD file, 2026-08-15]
hardware/Isolated Multi-Rail Power Supply Monitor Sensor Board/Isolated Multi-Rail Power Supply Monitor Sensor Board-drl_map.dxf
4.33 x 4.86

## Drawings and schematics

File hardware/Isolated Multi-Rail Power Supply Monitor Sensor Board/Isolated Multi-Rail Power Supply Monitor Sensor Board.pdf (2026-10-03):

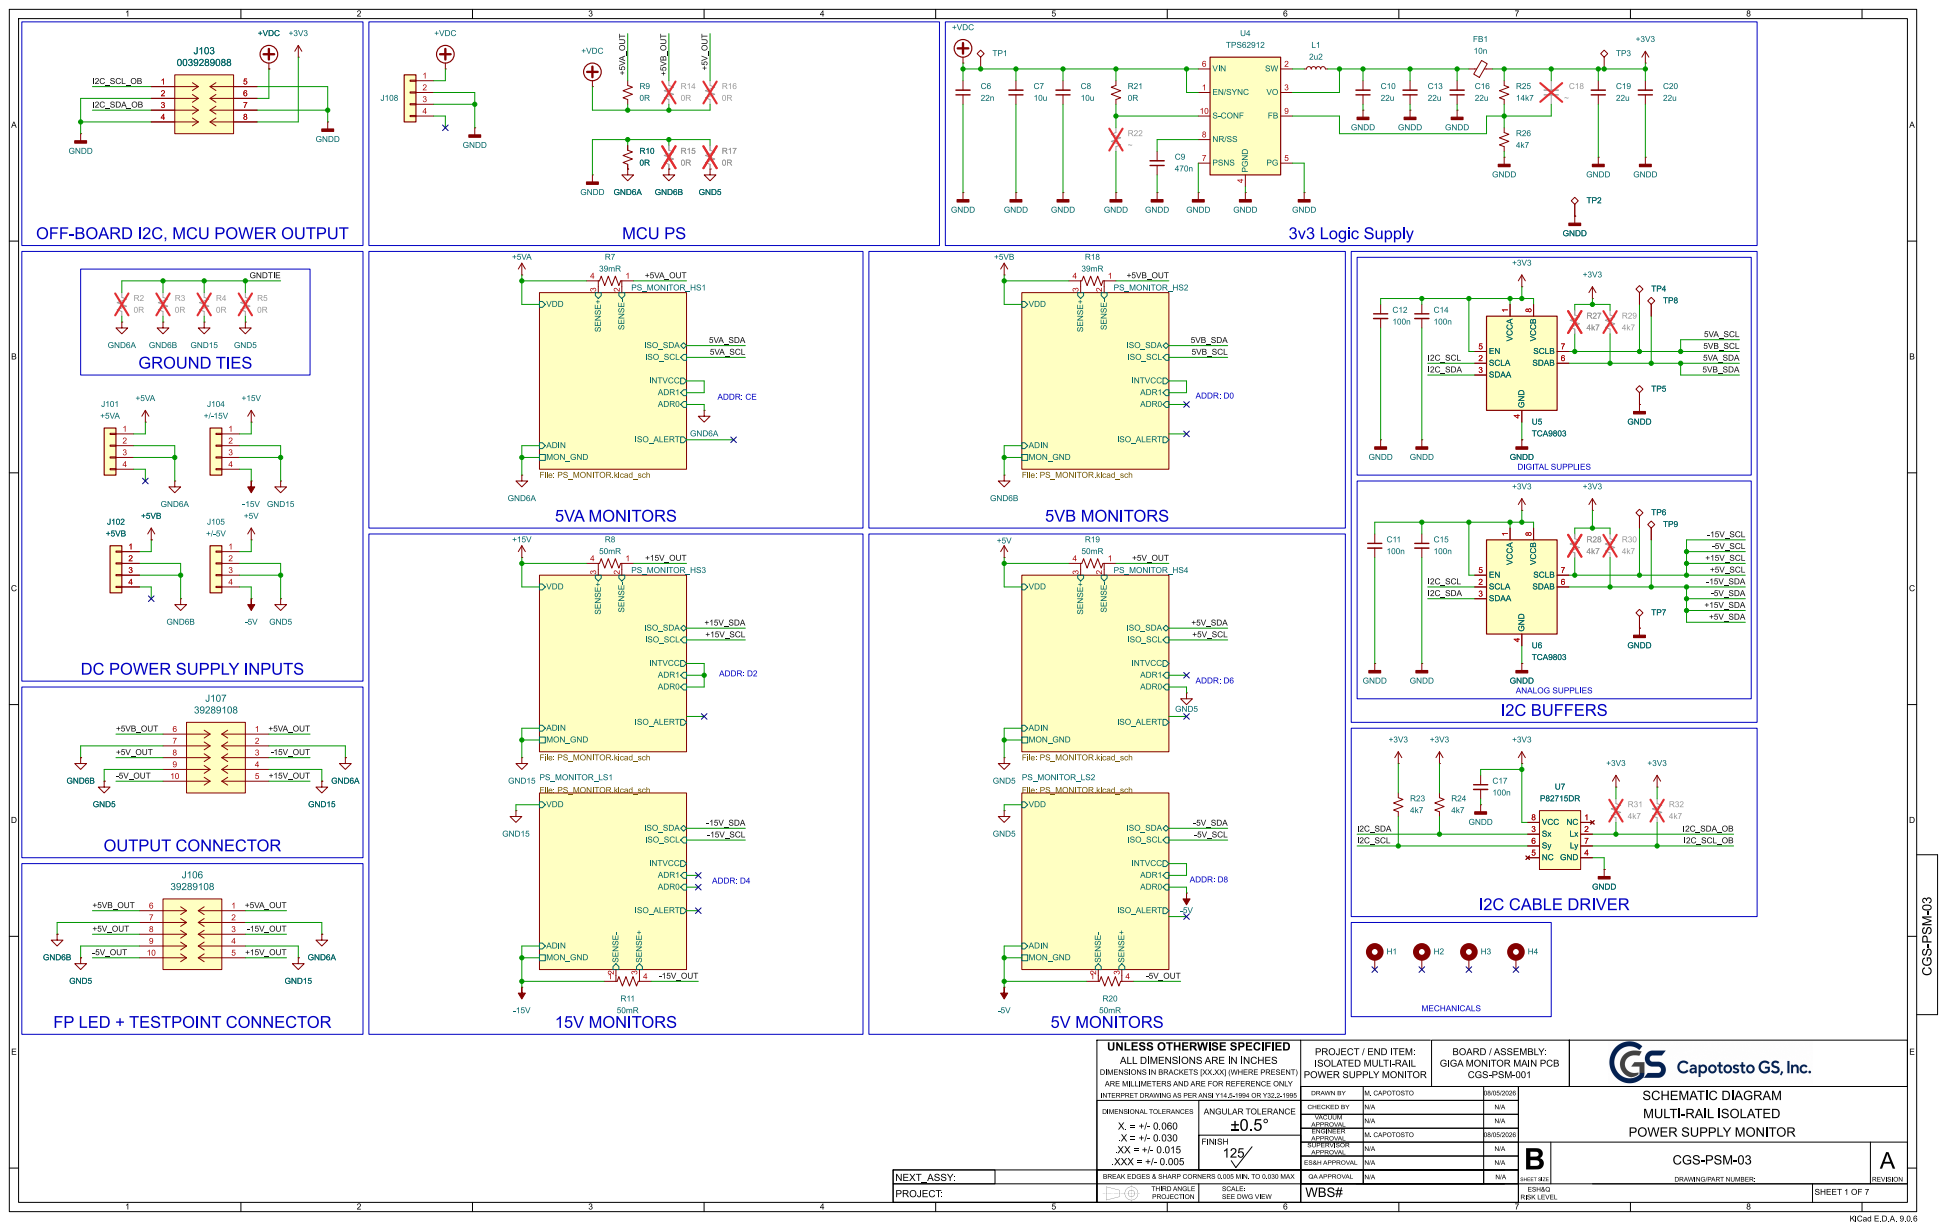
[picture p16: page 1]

4 SW 2 VO 3 FB 9 PG 5 U4 TPS62912 GNDD GND6A R10
I2C_SDA +5VA_OUT

+5V_SCL +5V_OUT
DC POWER SUPPLY INPUTS

FP LED + TESTPOINT CONNECTOR

SEE DWG VIEW UNLESS OTHERWISE SPECIFIED
ALL DIMENSIONS ARE IN INCHES
DIMENSIONS IN BRACKETS [XX.XX] (WHERE PRESENT) ARE MILLIMETERS AND ARE FOR REFERENCE ONLY

GIGA SUPPLYMONITOR MONITORMAIN PCB

INTERPRET DRAWING AS PER ANSI Y14.5-1994 OR Y32.2-1995 NEXT_ASSY:

DRAWN BY QA APPROVAL SUPERVISOR

SCHEMATIC DIAGRAM
MULTI-RAIL ISOLATED
KiCad E.D.A. 9.0.6 POWER SUPPLY MONITOR

ES&H APPROVAL APPROVAL WBS# | M. CAPOTOSTO | | RISK LEVEL SHEET SIZE | CGS-PSM-03 SHEET 1 OF 7 DRAWING/PART NUMBER: | A REVISION

BREAK EDGES & SHARP CORNERS 0.005 MIN. TO 0.030 MAX

THIRD ANGLE PROJECTION SCALE: | | ESH&Q

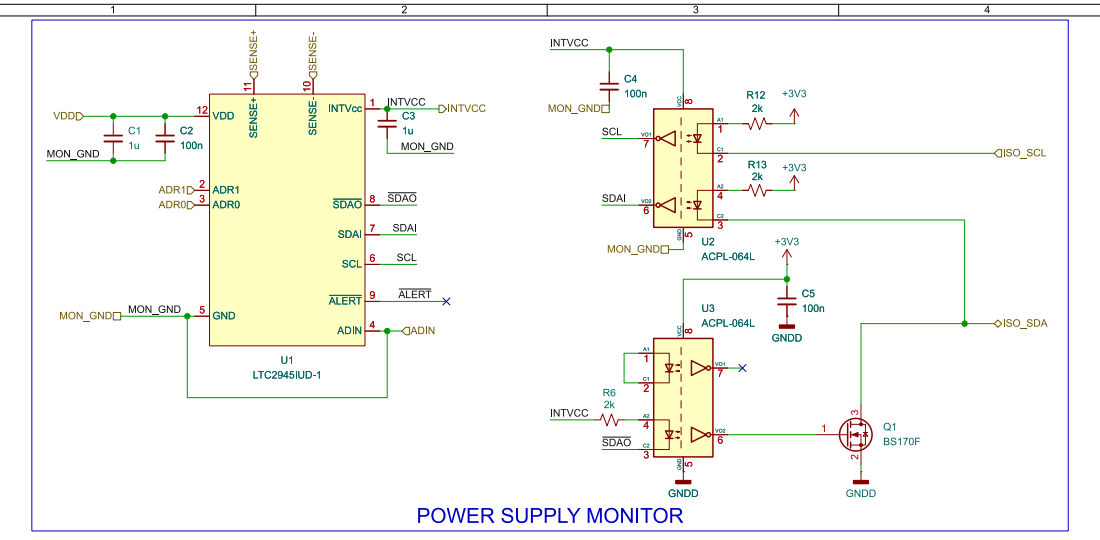
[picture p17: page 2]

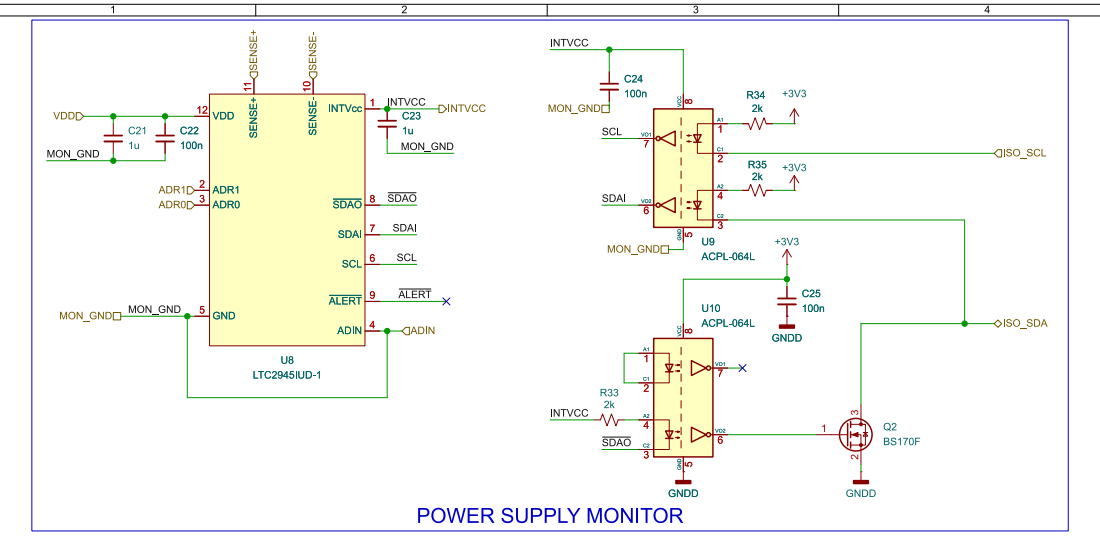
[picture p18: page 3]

~{SDAO} SCLPOWER SUPPLY MONITOR

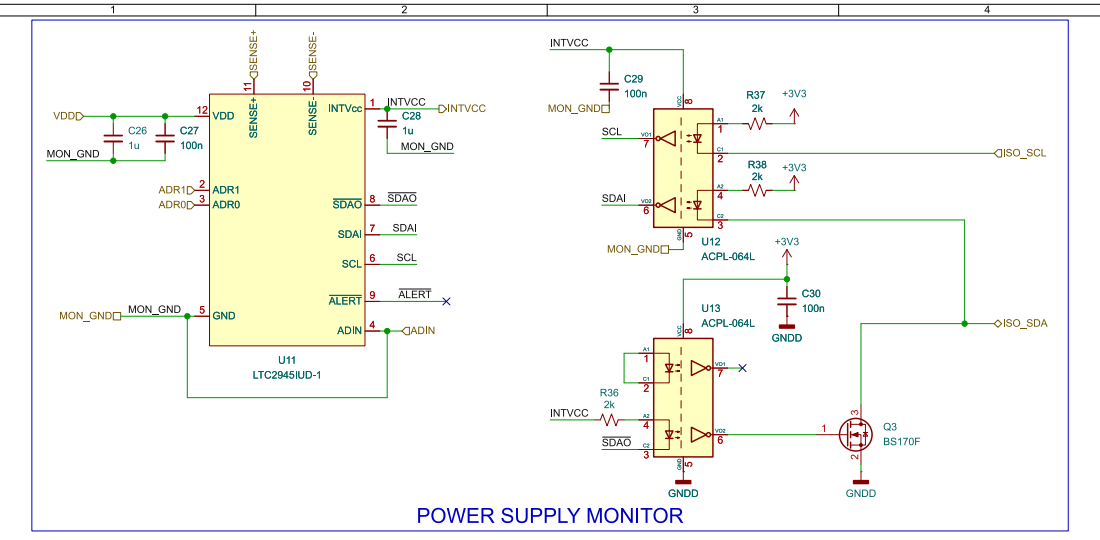
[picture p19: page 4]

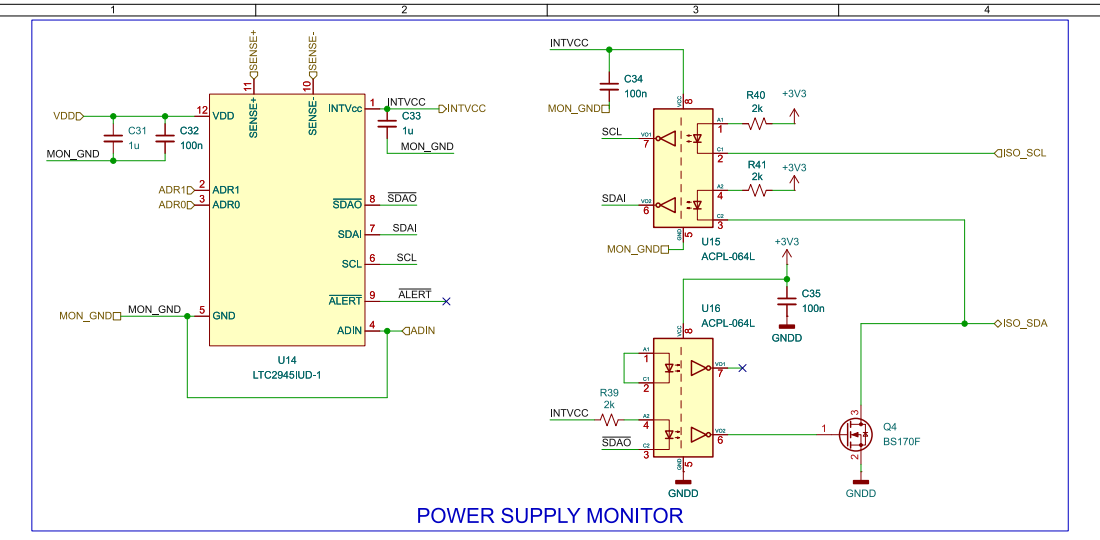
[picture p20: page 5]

INTVCC POWER SUPPLY MONITOR

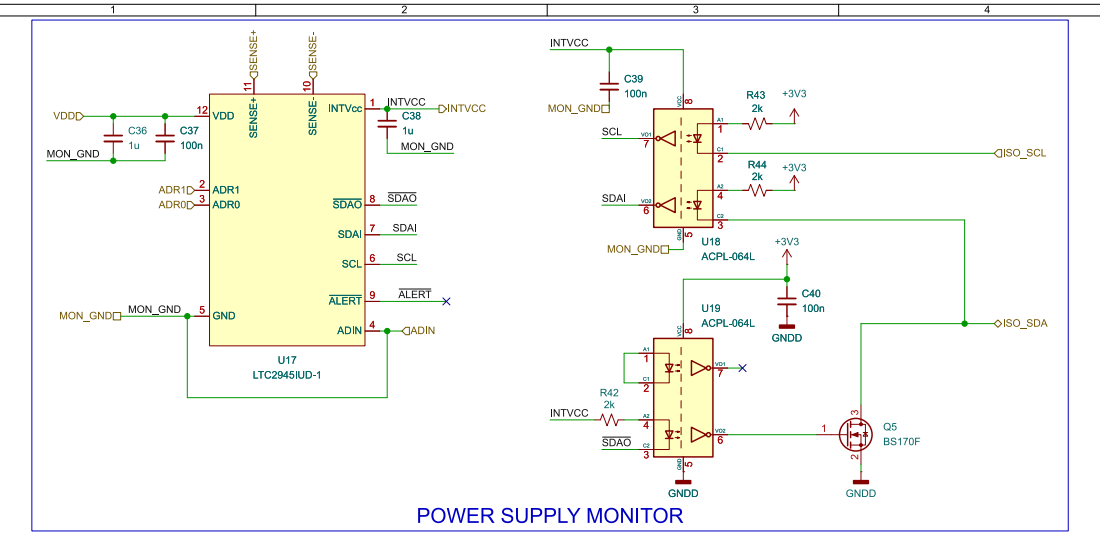
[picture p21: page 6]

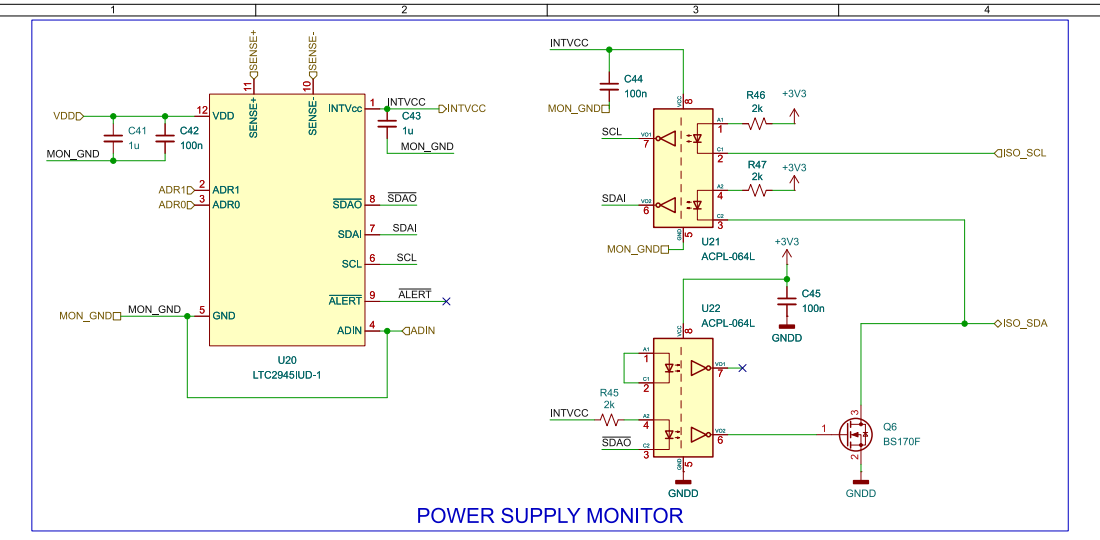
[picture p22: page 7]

3 2 Q6 BS170F VDD 12 ADR1 2 ADR0 3 GND 5 SENSE+ 11 SENSE- 10

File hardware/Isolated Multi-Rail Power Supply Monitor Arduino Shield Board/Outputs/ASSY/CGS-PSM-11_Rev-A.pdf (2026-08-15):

1 | 2 | 3 | 4 | 5 | 6 | 7 | 8

A

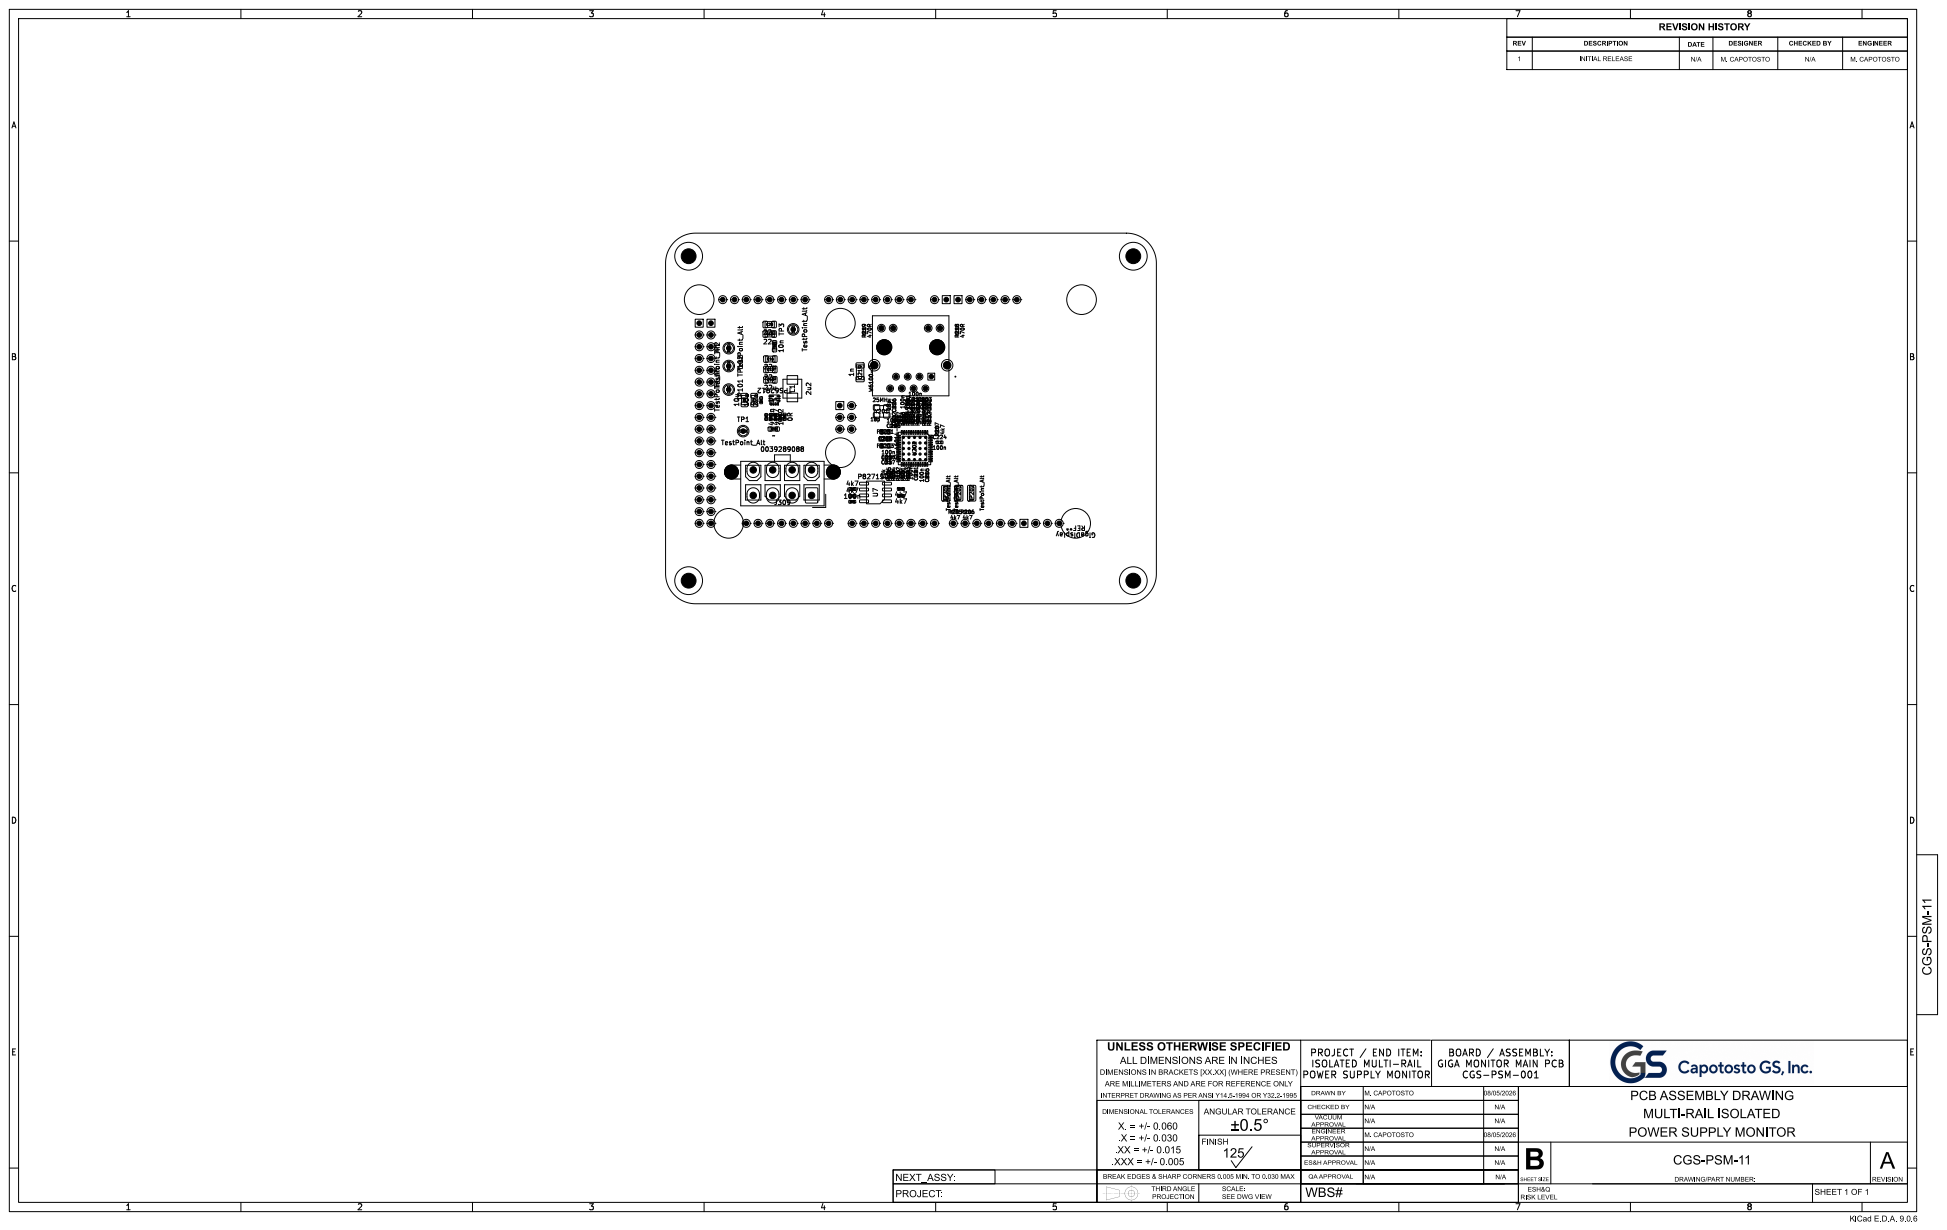
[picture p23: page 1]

SEE DWG VIEW UNLESS OTHERWISE SPECIFIED
ALL DIMENSIONS ARE IN INCHES
DIMENSIONS IN BRACKETS [XX.XX] (WHERE PRESENT) ARE MILLIMETERS AND ARE FOR REFERENCE ONLY

INTERPRET DRAWING AS PER ANSI Y14.5-1994 OR Y32.2-1995 NEXT_ASSY:

DRAWN BY QA APPROVAL SUPERVISOR

BREAK EDGES & SHARP CORNERS 0.005 MIN. TO 0.030 MAX

1 | 2 | 3 | 4 | 5 | 6 | 7 | 8

A

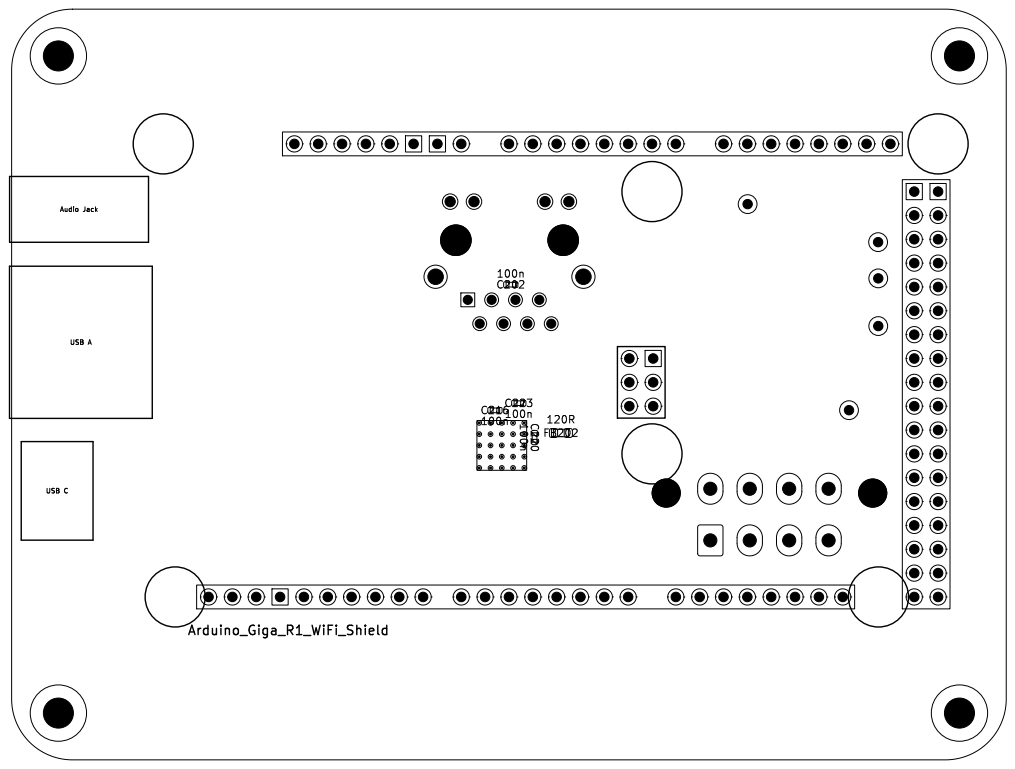
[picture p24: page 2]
SHEET SIZE; DRAWING/PART NUMBER:; REVISION SHEET 2 OF 2; KiCad E.D.A. 9.0.6 B; CGS-PSM-11; Arduino_Giga_R1_WiFi_Shield; Audio Jack USB A USB C

E CGS⁻PSM⁻¹¹

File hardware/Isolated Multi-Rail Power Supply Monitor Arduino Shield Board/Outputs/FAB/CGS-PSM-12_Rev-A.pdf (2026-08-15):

x | BOARD CHARACTERISTICS

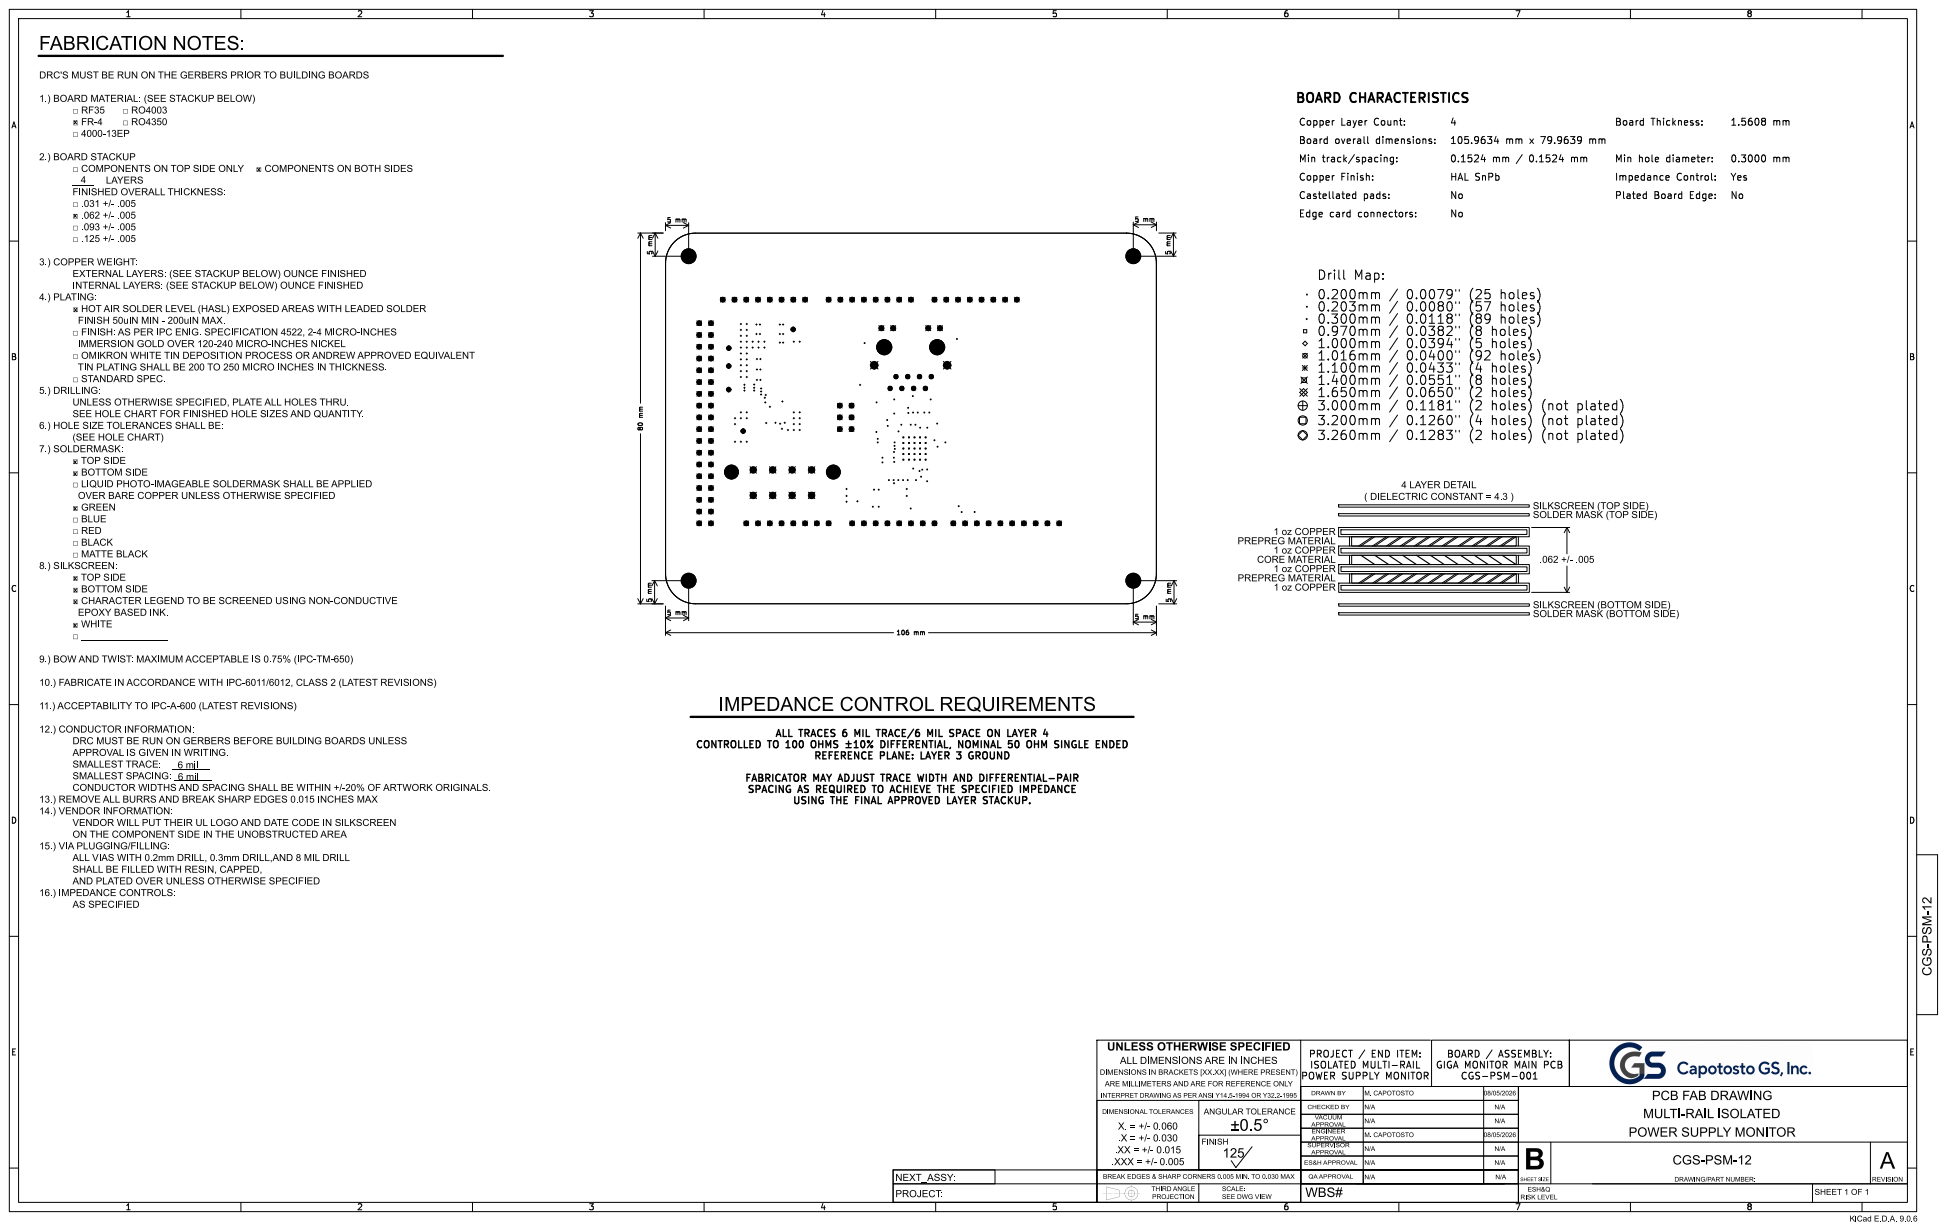
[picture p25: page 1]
SHEET SIZE; DRAWING/PART NUMBER:; REVISION; ESH&Q; RISK LEVEL; SHEET 1 OF 1; N/A M. CAPOTOSTO; VACUUM; APPROVAL; ES&H APPROVAL; M. CAPOTOSTO; CHECKED BY; ENGINEER; APPROVAL WBS#; .XXX = +/- 0.005 FINISH125; ANGULAR TOLERANCE; THIRD ANGLE; PROJECTION SCALE:; PROJECT:; PROJECT / END ITEM:; POWER /; ASSEMBLY:; GIGASUPPLY MONITOR MONITOR MAIN; PCB; CGS-PSM-001; HAL SnPb Edge card connectors:; Copper Layer Count:; Impedance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

Board Thickness: 0.1524 mm / 0.1524 mm

SPACING AS REQUIRED TO ACHIEVE THE SPECIFIED IMPEDANCE USING THE FINAL APPROVED LAYER STACKUP. x

REFERENCE PLANE: LAYER 3 GROUND

FABRICATOR MAY ADJUST TRACE WIDTH AND DIFFERENTIAL-PAIR

E CGS⁻PSM⁻¹²

SEE DWG VIEW UNLESS OTHERWISE SPECIFIED
ALL DIMENSIONS ARE IN INCHES
DIMENSIONS IN BRACKETS [XX.XX] (WHERE PRESENT) ARE MILLIMETERS AND ARE FOR REFERENCE ONLY

ISOLATEDBOARD MULTI-RAIL

INTERPRET DRAWING AS PER ANSI Y14.5-1994 OR Y32.2-1995 NEXT_ASSY:

DRAWN BY QA APPROVAL SUPERVISOR

PCB FAB DRAWING
MULTI-RAIL ISOLATED
KiCad E.D.A. 9.0.6 POWER SUPPLY MONITOR
CGS-PSM-12

APPROVAL DIMENSIONAL TOLERANCES X. = +/- 0.060

BREAK EDGES & SHARP CORNERS 0.005 MIN. TO 0.030 MAX

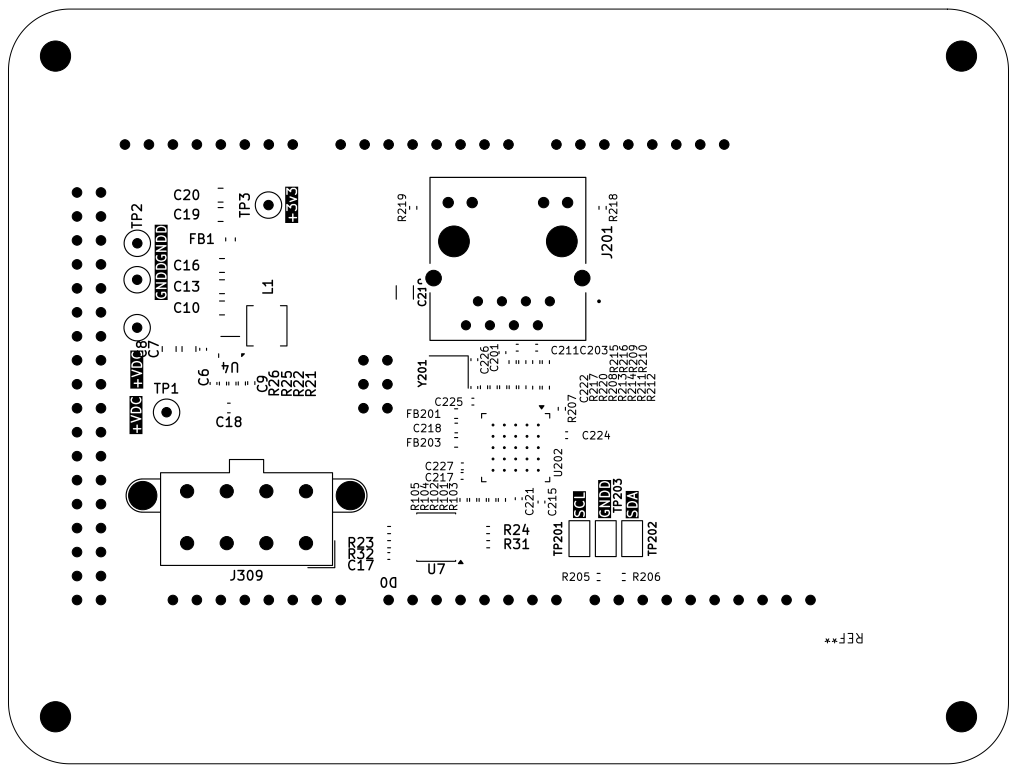
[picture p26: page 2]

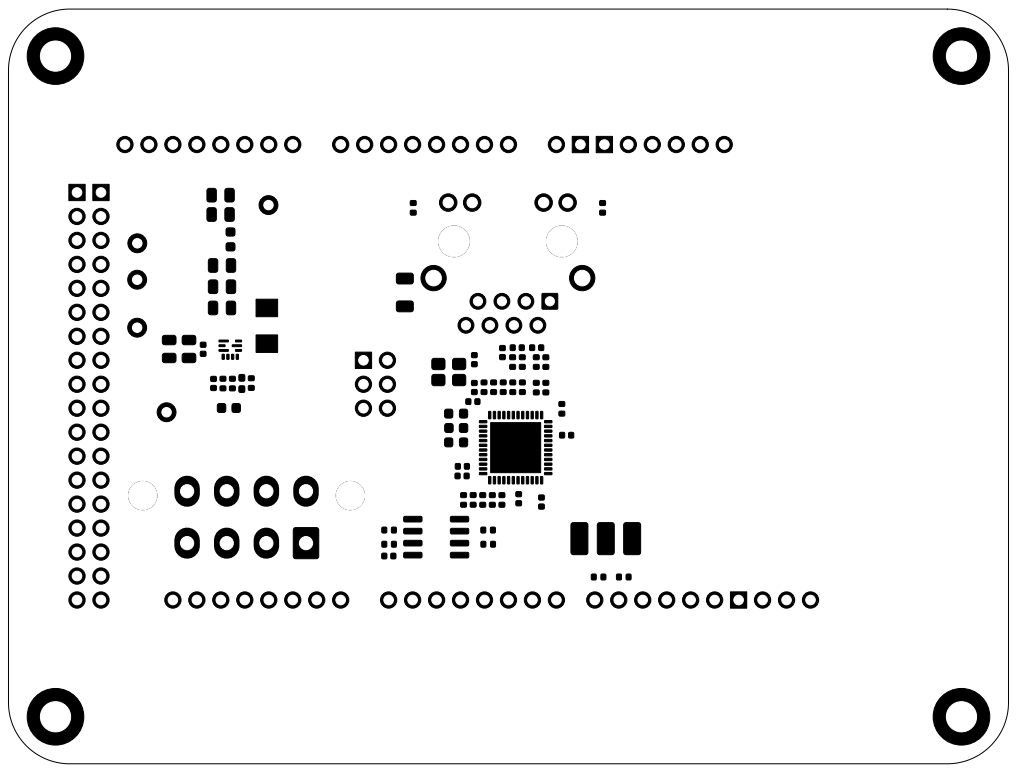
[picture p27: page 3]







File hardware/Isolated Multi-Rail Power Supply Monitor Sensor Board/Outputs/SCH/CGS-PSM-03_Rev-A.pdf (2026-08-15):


8 SCLB 7 SDAB 6 U5 TCA9803 EN 5 SCLA 2 SDAA 3 VCCA

DIGITAL SUPPLIES GROUND TIES

ANALOG SUPPLIES DC POWER SUPPLY INPUTS

SEE DWG VIEW UNLESS OTHERWISE SPECIFIED
ALL DIMENSIONS ARE IN INCHES
DIMENSIONS IN BRACKETS [XX.XX] (WHERE PRESENT) ARE MILLIMETERS AND ARE FOR REFERENCE ONLY

GIGA SUPPLYMONITOR MONITORMAIN PCB

INTERPRET DRAWING AS PER ANSI Y14.5-1994 OR Y32.2-1995 NEXT_ASSY:

DRAWN BY QA APPROVAL SUPERVISOR

SCHEMATIC DIAGRAM
MULTI-RAIL ISOLATED
KiCad E.D.A. 9.0.6 POWER SUPPLY MONITOR

ES&H APPROVAL APPROVAL WBS# | M. CAPOTOSTO | | RISK LEVEL SHEET SIZE | CGS-PSM-03 SHEET 1 OF 7 DRAWING/PART NUMBER: | A REVISION

BREAK EDGES & SHARP CORNERS 0.005 MIN. TO 0.030 MAX

THIRD ANGLE PROJECTION SCALE: | | ESH&Q





INTVCC
C23 U15 ACPL-064L C33
SCL SDAI POWER SUPPLY MONITOR


INTVCC
SCL SDAI POWER SUPPLY MONITOR


100n ADIN
INTVCC
SCL SDAI POWER SUPPLY MONITOR

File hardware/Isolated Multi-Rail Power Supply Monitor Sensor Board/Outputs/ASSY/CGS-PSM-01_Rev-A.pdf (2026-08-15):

1 | 2 | 3 | 4 | 5 | 6 | 7 | 8

A


SEE DWG VIEW UNLESS OTHERWISE SPECIFIED
ALL DIMENSIONS ARE IN INCHES
DIMENSIONS IN BRACKETS [XX.XX] (WHERE PRESENT) ARE MILLIMETERS AND ARE FOR REFERENCE ONLY

INTERPRET DRAWING AS PER ANSI Y14.5-1994 OR Y32.2-1995 NEXT_ASSY:

DRAWN BY QA APPROVAL SUPERVISOR

BREAK EDGES & SHARP CORNERS 0.005 MIN. TO 0.030 MAX

1 | 2 | 3 | 4 | 5 | 6 | 7 | 8

A

SHEET SIZE; DRAWING/PART NUMBER:; REVISION SHEET 2 OF 2; KiCad E.D.A. 9.0.6 B; CGS-PSM-01 R4

E CGS⁻PSM⁻⁰¹

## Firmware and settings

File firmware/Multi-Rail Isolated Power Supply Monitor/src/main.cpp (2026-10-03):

/*
  Arduino GIGA R1 + GIGA Display Shield + Ethernet Shield 2
  Modular six-channel power monitor.

  Services:
    HTTP dashboard: TCP port 80
    EPICS PSCDriver: TCP port 8765
*/

#include <Arduino.h>
#include "AppConfig.h"
#include "AppState.h"
#include "DisplayUI.h"
#include "EthernetServices.h"
#include "HttpDashboard.h"
#include "PersistentStorage.h"
#include "PscProtocol.h"
#include "SensorConfig.h"
#include "SensorManager.h"

namespace {
uint32_t lastSensorPollMs = 0;
uint32_t lastDisplayMs = 0;
}

void setup() {
  Serial.begin(115200);

  const uint32_t serialWaitStart = millis();
  while (!Serial && millis() - serialWaitStart < 1500) {
    delay(10);
  }

  initializeSettingsStorage();  //Initialize QSPI configuration
  initializeSensors();  //Initialize I2C PMICs
  initializeDisplay();  //Initialize display shield
  initializeEthernet();  //Initialize ethernet shield
  redrawDisplay();  //Redraw display
}

void loop() {
  const uint32_t now = millis();

  if (now - lastSensorPollMs >= SENSOR_POLL_PERIOD_MS) {
    lastSensorPollMs = now;
    updateSensorMeasurements();  //Update the sensor readouts
  }

  if (now - lastDisplayMs >= DISPLAY_REFRESH_PERIOD_MS) {
    lastDisplayMs = now;
    redrawDisplay();  //Redraw display with new values
  }

  /*
    PSC is serviced both before and after HTTP so a browser request cannot
    unnecessarily delay the persistent IOC connection.
  */
  servicePsc();  //R/W to the IOC
  serviceHttp();  //R/W to the webpage
  servicePsc();  //R/W to the IOC
}

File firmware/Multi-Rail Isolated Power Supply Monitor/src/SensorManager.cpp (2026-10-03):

#include "SensorManager.h"

#include <Arduino.h>
#include <Wire.h>

#include "AppConfig.h"
#include "AppState.h"
#include "LTC2945.h"
#include "SensorConfig.h"

namespace {

// All six isolator outputs share the same GIGA-side bus.
TwoWire &sensorBus = Wire2;

/*
  Array order must match channels[] in AppState.cpp:
    0 +6VA
    1 +6VB
    2 +5V
    3 -5V
    4 +15V
    5 -15V

  The two negative rails remain in SENSE+ high-side mode. Only the reported
  voltage sign is inverted in software.
*/

// Constructor arguments:
//   I2C bus, device address, shunt resistance,
//   voltage polarity multiplier, current polarity multiplier
LTC2945 sensors[CHANNEL_COUNT] = {
  {sensorBus, LTC_ADDRESS_6VA,  SHUNT_6VA_OHMS,  +1.0f, +1.0f},
  {sensorBus, LTC_ADDRESS_6VB,  SHUNT_6VB_OHMS,  +1.0f, +1.0f},
  {sensorBus, LTC_ADDRESS_P5V,  SHUNT_P5V_OHMS,  +1.0f, +1.0f},
  {sensorBus, LTC_ADDRESS_M5V,  SHUNT_M5V_OHMS,  -1.0f, +1.0f},
  {sensorBus, LTC_ADDRESS_P15V, SHUNT_P15V_OHMS, +1.0f, +1.0f},
  {sensorBus, LTC_ADDRESS_M15V, SHUNT_M15V_OHMS, -1.0f, +1.0f}
};

void printAddress(uint8_t address) {
  Serial.print("0x");

  if (address < 0x10) {
    Serial.print('0');
  }

  Serial.print(address, HEX);
}

void reportSensorTransition(
  uint8_t index,
  bool previousOnline,
  bool currentOnline
) {
  if (previousOnline == currentOnline) {
    return;
  }

  Serial.print(channels[index].name);
  Serial.print(" ");
  Serial.println(currentOnline ? "ONLINE" : "OFFLINE");
}

}

//Prints the channel names and I2C addresses to console. 
void printSensorConfiguration() {
  Serial.println();
  Serial.println("LTC2945 sensor configuration:");

  for (uint8_t i = 0; i < CHANNEL_COUNT; ++i) {
    Serial.print("  ");
    Serial.print(channels[i].name);
    Serial.print("  address ");
    printAddress(sensors[i].address());
    Serial.println();
  }

  Serial.println();
}

/*
  Initializes the I2C bus and each LTC2945 monitor.

  Each channel begins in an invalid/offline state. A sensor that responds
  successfully is configured by LTC2945::begin().
  
  Failed initialization records the I2C error and immediately sets the failure count to the
  offline threshold.

  A complete measurement pass is performed before the display and PSC
  interfaces begin so users get initialized data.
*/
void initializeSensors() {
  sensorBus.begin();
  sensorBus.setClock(SENSOR_I2C_CLOCK_HZ);

  printSensorConfiguration();

  for (uint8_t i = 0; i < CHANNEL_COUNT; ++i) {
    MonitorChannel &channel = channels[i];

    channel.readingValid = false;
    channel.sensorOnline = false;
    channel.sensorError = 0;
    channel.consecutiveSensorFailures = 0;
    channel.lastValidReadingMs = 0;

    const bool initialized = sensors[i].begin();

    Serial.print(channel.name);
    Serial.print(" at ");
    printAddress(sensors[i].address());

    if (initialized) {
      Serial.println(" acknowledged and configured");
    } else {
      channel.sensorError = sensors[i].lastError();
      channel.consecutiveSensorFailures =
        SENSOR_FAILURES_TO_OFFLINE;

      Serial.print(" failed, error 0x");
      Serial.println(channel.sensorError, HEX);
    }
  }

  // Populate the first complete snapshot before the display and PSC start.
  updateSensorMeasurements();
}

/*
  Polls all six LTC2945 channels and updates the shared MonitorChannel state.

  Successful reads:
    - replace V/I with the newest measurement
    - mark the reading valid and sensor online
    - clear the communication error/failure counter
    - update the timestamp and alarm state

  Failed reads:
    - preserve the last valid voltage/current values
    - record the LTC2945 communication error
    - increment the fail counter
    - mark the sensor offline only after the configured failure threshold

  The failure threshold prevents a single transient I2C error from causing
  an unnecessary ONLINE/OFFLINE state transition.
*/
void updateSensorMeasurements() {
  for (uint8_t i = 0; i < CHANNEL_COUNT; ++i) {
    MonitorChannel &channel = channels[i];
    const bool previousOnline = channel.sensorOnline;

    LTC2945::Reading reading;

    if (sensors[i].read(reading)) {
      channel.voltage = reading.voltage;
      channel.current = reading.current;
      channel.readingValid = true;
      channel.sensorOnline = true;
      channel.sensorError = 0;
      channel.consecutiveSensorFailures = 0;
      channel.lastValidReadingMs = millis();

      updateAlarmState(channel);
    } else {
      channel.sensorError = sensors[i].lastError();

      if (channel.consecutiveSensorFailures < 255) {
        ++channel.consecutiveSensorFailures;
      }

      if (channel.consecutiveSensorFailures >=
          SENSOR_FAILURES_TO_OFFLINE) {
        channel.sensorOnline = false;
      }

      /*
        Keep the last valid voltage and current. Replacing a failed read with
        zero would make an I2C fault look like a real rail undervoltage.
      */
    }

    // Log sensor state changes only to prevent needless prints
    reportSensorTransition(
      i,
      previousOnline,
      channel.sensorOnline
    );
  }
}

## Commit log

2026-08-15 Add PSU Monitor KiCAD Project
    [CGS-PSM-01_Rev-A_BOT.gbr, CGS-PSM-01_Rev-A_TOP.gbr, CGS-PSM-02_Rev-A.drl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]
2026-08-15 Update both PCBs
    [CGS-PSM-01_Rev-A_BOT.gbr, CGS-PSM-01_Rev-A_TOP.gbr, CGS-PSM-02_Rev-A.drl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]
2026-09-11 Nightly commit
    [Isolated Multi-Rail Power Supply Monitor Arduino Shield Board BOM.xlsx, Isolated Multi-Rail Power Supply Monitor Arduino Shield Board.csv, Isolated Multi-Rail 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]
2026-09-21 Update documentation for Week 2 Assignment
    [Isolated Multi-Rail Power Supply Monitor Arduino Shield Board.kicad_sch]
2026-10-03 Updating for Week 3 Assignment
    [Isolated Multi-Rail Power Supply Monitor Sensor Board.kicad_sch, Week 3 BOM.xlsx]
2026-10-03 Add comments to SensorManager.cpp
    Add comments to SensorManager.cpp
2026-10-09 Add Python instrument driver package as submodule to repo
